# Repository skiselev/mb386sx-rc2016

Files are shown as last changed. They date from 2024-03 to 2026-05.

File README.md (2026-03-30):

# Alsea River 386SX Motherboard
An 386SX/486SLC Motherboard based on SARC RC2016 Chipset

## Introduction

The origin of this project is the [M396F motherboard replica by Marco Both](https://github.com/Marco-Both/M396F-Replika). Marco replicated the PCB layout of a certain revision of M396F motherboard. He didn't provide the schematic.

I reverse engineered the schematic based on his PCB layout and made a PCB layout using that schematic similar to the Marco's replica. This was the initial version of this project - [version 1.0](https://github.com/skiselev/mb386sx-rc2016/tree/v1.0).

The subsequent versions contain the following improvements:

* Use Dallas DS12885 RTC/NVRAM (aka CMOS) with a CR2032 battery instead of Motorola MC146818 with a NiCad battery. This reduces the likliehood of motherboard damage due to a leaking battery. A more modern RTC IC also reduces the number of components
* Use SST39SF010A Flash ROM instead of an EPROM or OTP ROM. The Flash ROM is in-circuit programmable, allowing BIOS and BIOS extension upgrades. It has a bigger 128 KiB capacity, all of which is mapped to the CPU memory. The SST39SF010A is a currently manufactured part
* Use PS/2 compatible keyboard controller, VIA VT82C42N or similar. The motherboard implements a dual PS/2 port with both keyboard and mouse signals. A PS/2 keyboard/mouse splitter cable can be used to connect both a keyboard and a mouse.
* Use ATX case compatible mounting holes placement. Implement ATX power supply power on circuit. This allows using the motherboard with more modern ATX cases and power supplies
* Use DIP-8 / half-can crystal oscillators for the CPU and FPU clocks. This removes the need for a difficult to get clock synthesizer IC used in the original motherboard, while still allowing changing the CPU and the FPU clock by switching the oscillators
* Implement headers for the CPU. The CPU can be either installed on a [386SX Universal Socket Adapter](https://github.com/skiselev/i386sx-socket), or soldered down on the motherboard
* On board disagnostic LEDs, Power, and Reset switches

Alsea River 386SX - Assembled Board

## Status

* Board version 2.3 tested and works properly.
* Board version 2.2 has the fix for the BIOS /OE issue, but it has not been actually built and tested yet.
* Board version 2.1 boots up to BIOS, DOS, and Linux, after performing the fix described in the Known Issues section.
* The following CPUs have been tested with the board version 2.1:
  * Intel 386SX, part name: NG80386SX33. Installed on a 386SX Universal Socket Adapter, configured for 5V. Runs well at 33 MHz.
  * Texas Instruments 486SLCX2-50, part name: TI486SXLC2-G50-WN. Installed on a 386SX Universal Socket Adapter, configured for 3.3V. Runs well at 25 MHz, 33 MHz, and 40 MHz. Unable to enable clock doubling yet.
  * Texas Instruments 486SLCX2-50, part name: TI486SXLC2-G50-PQ. Installed on a 386SX Universal Socket Adapter, configured for 3.3V. Runs well at 25 MHz, 33 MHz, and 40 MHz. Unable to enable clock doubling yet.
  * Texas Instruments 486SLC/E-33. part name: TX486SLC/E-33PAF. Installed on a 386SX Universal Socket Adapter, configured for 5V. Runs well at 33 MHz. Also works at 40 MHz, although gets quite hot. Stability has not been verified yet with 40 MHz.
* PS/2 mouse tested and works properly with both 2 button and 3 button wheeled mouse using [CuteMouse driver](https://cutemouse.sourceforge.net/).
* AMI BIOS 5.10 and [Award BIOS 4.50](https://github.com/skiselev/mb386sx-rc2016/tree/main/BIOS) from other SARC RC2016 based motherboards tested. The latter provides better configurability using MODBIN.

## Hardware Documentation

* [Alsea River 386SX Motherboard - User Guide](User_Guide.md)
* [SARC RC2016 Chipset](SARC_RC2016.md)
* [Cyrix and TI 486SLC/SXLC Processors](Cyrix_and_TI_486.md)

### Schematic and PCB Layout

* [Schematic - Version 2.3](KiCad/AT386SX-Schematic-2.3.pdf)
* [PCB Layout - Version 2.3](KiCad/AT386SX-Board-2.3.pdf)

### Bill of Materials

#### Version 2.3

[Alsea River 386SX Motherboard project on Mouser.com](https://www.mouser.com/Tools/Project/Share?AccessID=6eadf3eb2e) - View and order most components except of the CPU, chipset, keyboard controller, SIMM-30 sockets, and the PCB.

Component type     | Reference | Description                                          | Quantity | Possible sources and notes 
------------------ | --------- | ---------------------------------------------------- | -------- | --------------------------
PCB                |           | Alsea River 386SX PCB - Version 2.1                  | 1        | Order from a PCB manufacturer of your choice using provided Gerber or KiCad files
Integrated Circuit | U1        | 386SX CPU, TI486SXLC, Cx486SLC CPU, 100 pin BQFP     | 1        | eBay
Integrated Circuit | U2        | 387SX FPU or compatible, 68 pin PLCC                 | 1        | eBay. Optional
Integrated Circuit | U3        | SARC RC2016A5, 208 pin PQFP                          | 1        | UTsource
Integrated Circuit | U4        | DS12885 RTC, 24 pin DIP                              | 1        | Mouser [700-DS12885](https://www.mouser.com/ProductDetail/700-DS12885)
Integrated Circuit | U5        | VT82C42N keyboard/mouse controller, 40 pin DIP       | 1        | eBay
Integrated Circuit | U6        | SST39SF010A 128 KiB Flash ROM, 32 pin DIP            | 1        | Mouser [804-39SF010A7CPHE](https://www.mouser.com/ProductDetail/804-39SF010A7CPHE)
Integrated Circuit | U7        | 74HC05 inverters with open drain outputs, 14 pin DIP | 1        | Mouser [595-SN74AHC05N](https://www.mouser.com/ProductDetail/595-SN74AHC05N), [595-SN74HC05N](https://www.mouser.com/ProductDetail/595-SN74HC05N), [595-SN74LS06N](https://www.mouser.com/ProductDetail/595-SN74LS06N)
Integrated Circuit | U8        | 74HCT14 inverters with Schmitt trigger inputs, 14 pin DIP | 1   | Mouser [595-SN74AHCT14N](https://www.mouser.com/ProductDetail/595-SN74AHCT14N), [595-SN74HCT14N](https://www.mouser.com/ProductDetail/595-SN74HCT14N)
Integrated Circuit | U9        | 74HCT74 D-flip flops, 14 pin DIP                     | 1        | Mouser [595-SN74AHCT74N](https://www.mouser.com/ProductDetail/595-SN74AHCT74N), [595-SN74HCT74N](https://www.mouser.com/ProductDetail/595-SN74HCT74N), 
Integrated Circuit | U10       | LM7905 -5V voltage regulator, TO-220-3               | 1        | Mouser [863-MC7905CTG](https://www.mouser.com/ProductDetail/863-MC7905CTG), [926-LM7905CT/NOPB](https://www.mouser.com/ProductDetail/926-LM7905CT-NOPB)
Transistor         | Q1        | 2N3904, NPN transistor, TO-92                        | 1        | Mouser [512-2N3904TA](https://www.mouser.com/ProductDetail/512-2N3904TA)
LED                | D1        | 3 mm LED, blue                                       | 1        | Optional. Mouser [604-WP710A10QBD/D](https://www.mouser.com/ProductDetail/604-WP710A10QBD-D), [696-SSL-LX3054USBD](https://www.mouser.com/ProductDetail/696-SSL-LX3054USBD), [749-3BWD-S](https://www.mouser.com/ProductDetail/749-3BWD-S)
LED                | D2        | 3 mm LED, bi-color red/green                         | 1        | Optional. Mouser [604-WP937EGW](https://www.mouser.com/ProductDetail/604-WP937EGW), [696-SSL-LX3054IGW](https://www.mouser.com/ProductDetail/696-SSL-LX3054IGW), [749-3BC](https://www.mouser.com/ProductDetail/749-3BC)
LED Spacer         | D1, D2    | Spacer for 3 mm LEDs, 3mm height                     | 2        | Optional. Mouser [749-ELM-2-3MM](https://www.mouser.com/ProductDetail/749-ELM-2-3MM)
Crystal Oscillator | X1        | 66 MHz (twice desired CPU frequency), 5V, DIP-8      | 1        | Mouser 50 MHz: [520-TCH5000](https://www.mouser.com/ProductDetail/520-TCH5000), [815-ACH-50-EK](https://www.mouser.com/ProductDetail/815-ACH-50-EK), [774-MXO45HS-3C-50.0](https://www.mouser.com/ProductDetail/774-MXO45HS-3C-50.0); 66.6666MHz: [774-MXO45HS2C66.6666](https://www.mouser.com/ProductDetail/774-MXO45HS2C66.6666), [520-TCH6666-X](https://www.mouser.com/ProductDetail/520-TCH6666-X); 80 MHz: [520-ECS-2200B-800](https://www.mouser.com/ProductDetail/520-ECS-2200B-800), [774-MXO45HS-3C-80.0](https://www.mouser.com/ProductDetail/774-MXO45HS-3C-80.0)
Crystal Oscillator | X2        | 66 MHz (twice desired FPU frequency), 5V, DIP-8      | 1        | Optional. See above.
Crystal Resonator  | Y1        | 14.31818 MHz, parallel, HC-49U                       | 1        | Mouser [815-ABL-14.31818B2](https://www.mouser.com/ProductDetail/815-ABL-14.31818B2), [559-FOXS143-20-LF](https://www.mouser.com/ProductDetail/559-FOXS143-20-LF)
Crystal Resonator Insulator | Y1 | Mylar insulator for HC-49U crystal resonators      | 1        | Optional. Mouser [749-CI-192-028-SR](https://www.mouser.com/ProductDetail/749-CI-192-028-SR)
Crystal Resonator  | Y2        | 32768 Hz, watch crystal, 6 pf, D = 2.1 mm, L = 6.2 mm  | 1      | Mouser [815-AB26T32768KHZ6B](https://www.mouser.com/ProductDetail/815-AB26T32768KHZ6B), [520-ECS327-6-13-X](https://www.mouser.com/ProductDetail/520-ECS327-6-13-X), or [628-VT200F-6PF20PPM](https://www.mouser.com/ProductDetail/628-VT200F-6PF20PPM)
IC Socket          | U2        | 68 pin PLCC, through hole                            | 1        | Mouser [737-PLCC-68-AT](https://www.mouser.com/ProductDetail/737-PLCC-68-AT), [517-8468-11B1-RK-TP](https://www.mouser.com/ProductDetail/517-8468-11B1-RK-TP), [575-682444](https://www.mouser.com/ProductDetail/575-682444)
IC Socket          | U4        | 24 pin DIP                                           | 1        | Mouser [737-ICS-624-T](https://www.mouser.com/ProductDetail/737-ICS-624-T), [517-4824-6000-CP](https://www.mouser.com/ProductDetail/517-4824-6000-CP), [571-1-2199298-8](https://www.mouser.com/ProductDetail/571-1-2199298-8)
IC Socket          | U5        | 40 pin DIP                                           | 1        | Mouser [737-ICS-640-T](https://www.mouser.com/ProductDetail/737-ICS-640-T), [517-4840-6000-CP](https://www.mouser.com/ProductDetail/517-4840-6000-CP), [571-1-2199299-5](https://www.mouser.com/ProductDetail/571-1-2199299-5)
IC Socket          | U6        | 32 pin DIP                                           | 1        | Mouser [737-ICS-632-T](https://www.mouser.com/ProductDetail/737-ICS-632-T), [517-4832-6000-CP](https://www.mouser.com/ProductDetail/517-4832-6000-CP), [571-1-2199300-2](https://www.mouser.com/ProductDetail/571-1-2199300-2)
IC Socket          | U7 - U9   | 14 pin DIP                                           | 3        | Mouser [737-ICS-314-T](https://www.mouser.com/ProductDetail/737-ICS-314-T), [517-4814-3000-CP](https://www.mouser.com/ProductDetail/517-4814-3000-CP), [571-1-2199298-3](https://www.mouser.com/ProductDetail/571-1-2199298-3)
Oscillator Socket  | X1, X2    | 4 pin DIP                                            | 2        | Mouser [535-1108800](https://www.mouser.com/ProductDetail/535-1108800)
Battery            | BT1       | CR2032 battery                                       | 1        | Mouser [81-CR2032](https://www.mouser.com/ProductDetail/81-CR2032), [658-CR2032](https://www.mouser.com/ProductDetail/658-CR2032), [614-CR2032-200](https://www.mouser.com/ProductDetail/614-CR2032-200)
Battery Socket     | BT1       | CR2032 battery socket, through hole                  | 1        | Mouser [122-2420-GR](https://www.mouser.com/ProductDetail/122-2420-GR), [122-2620-GR](https://www.mouser.com/ProductDetail/122-2620-GR)
Connector          | J1 - J4   | SIMM 30 socket, 30 pin                               | 4        | eBay
Connector          | J5 - J10  | ISA card edge connector, 98 pin                      | 6        | Mouser [587-395-098-520-350](https://www.mouser.com/ProductDetail/587-395-098-520-350)
Connector          | J11       | PS/2 Keyboard/Mouse connector, Mini-DIN 6 pin        | 1        | Mouser [806-KMDGX-6S-BS](https://www.mouser.com/ProductDetail/806-KMDGX-6S-BS)
Connector          | J12       | ATX power connector, 20 pin                          | 1        | Mouser [538-46015-2006](https://www.mouser.com/ProductDetail/538-46015-2006)
Connector          | J13       | 2x8 pin header, 2.54 mm (0.1") pitch, through hole   | 1        | Mouser [737-PH2-16-UA](https://www.mouser.com/ProductDetail/737-PH2-16-UA)
Connector          | J14 - J17 | 2x14 pin socket, 2 mm pitch, through hole            | 4        | Optional. Mouser [538-79107-7062](https://www.mouser.com/ProductDetail/538-79107-7062), [200-SQT11301LD](https://www.mouser.com/ProductDetail/200-SQT11301LD), [200-SQT11301FD](https://www.mouser.com/ProductDetail/200-SQT11301FD)
Connector          | JP1 - JP3 | 2 pin header, 2.54 mm (0.1") pitch, through hole     | 3        | Mouser [737-PH1-02-UA](https://www.mouser.com/ProductDetail/737-PH1-02-UA)
Connector          | JP4 - JP6 | 3 pin header, 2.54 mm (0.1") pitch, through hole     | 3        | Mouser [737-PH1-03-UA](https://www.mouser.com/ProductDetail/737-PH1-03-UA). Some headers are optional, and can be hardwired for the soldered CPU.
Connector          | JP1 - JP6 | Shunt, 2 pin, 2.54 mm (0.1") pitch                   | 4        | Mouser [737-MSA-G](https://www.mouser.com/ProductDetail/737-MSA-G), [806-SX1100-B](https://www.mouser.com/ProductDetail/806-SX1100-B)
Switch             | SW1, SW2  | 6 mm tactile switch, vertical, through hole          | 2        | Optional. Mouser [653-B3F-1000](https://www.mouser.com/ProductDetail/653-B3F-1000)
Capacitor          | C1 - C3   | 30 pF, 50V MLCC, 5.08 mm (0.2") pitch                | 3        | Mouser [594-K300J10C0GF5UH5](https://www.mouser.com/ProductDetail/594-K300J10C0GF5UH5)
Capacitor          | C4 - C7   | 47 pF, 50V MLCC, 5.08 mm (0.2") pitch                | 4        | Mouser [810-FG28C0G1H470JNT6](https://www.mouser.com/ProductDetail/810-FG28C0G1H470JNT6)
Capacitor          | C8        | 100 pF, 50V MLCC, 5.08 mm (0.2") pitch               | 1        | Mouser [810-FG28C0G1H101JNT6](https://www.mouser.com/ProductDetail/810-FG28C0G1H101JNT6)
Capacitor          | C9        | 220 pF, 50V MLCC, 5.08 mm (0.2") pitch               | 1        | Mouser [810-FG28C0G1H221JNT6](https://www.mouser.com/ProductDetail/810-FG28C0G1H221JNT6)
Capacitor          | C10 - C21 | 100 nF, 25V MLCC, 5.08 mm (0.2") pitch               | 12       | Mouser [594-K104K15X7RF53H5](https://www.mouser.com/ProductDetail/594-K104K15X7RF53H5), [810-FG28X7R1H104KNT6](https://www.mouser.com/ProductDetail/810-FG28X7R1H104KNT6)
Capacitor          | C22, C23  | 1 uF, 10V MLCC, 5.08 mm (0.2") pitch                 | 2        | Mouser [810-FG28X5R1H105KRT6](https://www.mouser.com/ProductDetail/810-FG28X5R1H105KRT6)
Capacitor          | C24 - C48 | 10 uF, 25V electrolytic, 5 mm diameter, 2.5 mm pitch | 25       | Mouser [667-EEU-FR1H100](https://www.mouser.com/ProductDetail/667-EEU-FR1H100)
Polyfuse           | F1        | 1.1A, 5.08 mm (0.2") pitch                           | 1        | Mouser [650-RUSBF110-2](https://www.mouser.com/ProductDetail/650-RUSBF110-2)
Ferrite Choke      | L1 - L4   | axial                                                | 4        | Mouser [623-2743001112LF](https://www.mouser.com/ProductDetail/623-2743001112LF)
Resistor           | R1 - R12  | 10 ohm, 0.25 W, axial                                | 12       | Mouser [708-CF14JT10R0](https://www.mouser.com/ProductDetail/708-CF14JT10R0), [603-MFR-25FBF52-10R](https://www.mouser.com/ProductDetail/603-MFR-25FBF52-10R)
Resistor           | R13 - R15 | 22 ohm, 0.25 W, axial                                | 3        | Mouser [708-CF14JT22R0](https://www.mouser.com/ProductDetail/708-CF14JT22R0), [603-MFR-25FBF52-22R](https://www.mouser.com/ProductDetail/603-MFR-25FBF52-22R)
Resistor           | R16, R17  | 56 ohm, 0.25 W, axial                                | 2        | Mouser [708-CF14JT56R0](https://www.mouser.com/ProductDetail/708-CF14JT56R0), [603-MFR-25FBF52-56R](https://www.mouser.com/ProductDetail/603-MFR-25FBF52-56R)
Resistor           | R18 - R21 | 100 ohm, 0.25 W, axial                               | 4        | Mouser [708-CF14JT100R](https://www.mouser.com/ProductDetail/708-CF14JT100R), [603-MFR-25FBF52-100R](https://www.mouser.com/ProductDetail/603-MFR-25FBF52-100R)
Resistor           | R22       | 330 ohm, 0.25 W, axial                               | 1        | Mouser [708-CF14JT330R](https://www.mouser.com/ProductDetail/708-CF14JT330R), [603-MFR-25FBF52-330R](https://www.mouser.com/ProductDetail/603-MFR-25FBF52-330R)
Resistor           | R23 - R29 | 470 ohm, 0.25 W, axial                               | 7        | Mouser [708-CF14JT470R](https://www.mouser.com/ProductDetail/708-CF14JT470R), [603-MFR-25FBF52-470R](https://www.mouser.com/ProductDetail/603-MFR-25FBF52-470R)
Resistor           | R30, R31  | 1 kohm, 0.25 W, axial                                | 2        | Mouser [708-CF14JT1K00](https://www.mouser.com/ProductDetail/708-CF14JT1K00), [603-MFR-25FBF52-1K](https://www.mouser.com/ProductDetail/603-MFR-25FBF52-1K)
Resistor           | R32       | 4.7 kohm, 0.25 W, axial                              | 1        | Mouser [708-CF14JT4K70](https://www.mouser.com/ProductDetail/708-CF14JT4K70), [603-MFR-25FBF52-4K7](https://www.mouser.com/ProductDetail/603-MFR-25FBF52-4K7)
Resistor           | R33 - R38 | 10 kohm, 0.25 W, axial                               | 6        | Mouser [708-CF14JT10K0](https://www.mouser.com/ProductDetail/708-CF14JT10K0), [603-MFR-25FBF52-10K](https://www.mouser.com/ProductDetail/603-MFR-25FBF52-10K)
Resistor           | R39       | 22 kohm, 0.25 W, axial                               | 1        | Mouser [708-CF14JT22K0](https://www.mouser.com/ProductDetail/708-CF14JT22K0), [603-MFR-25FBF52-22K](https://www.mouser.com/ProductDetail/603-MFR-25FBF52-22K)
Resistor           | R40       | 1 Mohm, 0.25 W, axial                                | 1        | Mouser [708-CF14JT1M00](https://www.mouser.com/ProductDetail/708-CF14JT1M00), [603-MFR-25FBF52-1M](https://www.mouser.com/ProductDetail/603-MFR-25FBF52-1M)
Resistor Array     | RN1       | 330 ohm, 8 resistors, bussed, 9 pin SIL              | 1        | Mouser [652-4609X-1LF-330](https://www.mouser.com/ProductDetail/652-4609X-1LF-330), [652-4609X-AP1-331LF](https://www.mouser.com/ProductDetail/652-4609X-AP1-331LF)
Resistor Array     | RN2, RN3  | 4.7 kohm, 5 resistors, bussed, 6 pin SIL             | 2        | Mouser [652-4606X-1LF-4.7K](https://www.mouser.com/ProductDetail/652-4606X-1LF-4.7K), [652-4606X-AP1-472LF](https://www.mouser.com/ProductDetail/652-4606X-AP1-472LF)
Resistor Array     | RN4       | 4.7 kohm, 8 resistors, bussed, 9 pin SIL             | 1        | Mouser [652-4609X-1LF-4.7K](https://www.mouser.com/ProductDetail/652-4609X-1LF-4.7K), [652-4609X-AP1-472LF](https://www.mouser.com/ProductDetail/652-4609X-AP1-472LF)
Resistor Array     | RN5       | 10 kohm, 4 resistors, bussed, 5 pin SIL              | 1        | Mouser [652-4605X-1LF-10K](https://www.mouser.com/ProductDetail/652-4605X-1LF-10K), [652-4605X-AP1-103LF](https://www.mouser.com/ProductDetail/652-4605X-AP1-103LF)

## Software

### BIOS

For the testing purposes I am using BIOSes from other commerical motherboards based on the same SARC RC2016 chipset. [The Retro Web](https://theretroweb.com/bios?itemsPerPage=24&chipsetIds[]=648) has a collection of the BIOSes for this chipset.

#### BIOS Progamming and ROM ICs support.

The is designed for the 128 KiB SST SST39SF010A Flash ROM. This ROM is mapped to the 0xE0000-0xFFFFF (or, with 8086 segments, E000:0000 to F000:FFFF). The upper 64 KiB - 0xF0000-0xFFFFF (F000:0000-F000:FFFF) are typically used for the BIOS ROM. The lower 64 KiB - 0xE0000-0xEFFFF can be used for BIOS extensions. Please take that into the consideration when programming the Flash ROM. Make sure to load the BIOS image to the top 64 KiB of the Flash ROM, starting at the address 0x10000. Other pin compatible 128 KiB Flash ROMs, such as AMD AM29F010A, SST SST29EE010, Atmel AT29C010A can be also used without any changes.

It is also possible to use 256 KiB and 512 KiB Flash ROMs, for example SST39SF020 and SST39SF040. Note that the A17 address line is connected to VCC (logic high/"1") and the address line A18 is connected to the ground (logic low/"0"). Therefore when using these flash ROMs, please program the 64 KiB BIOS image starting at the addres 0x30000 of the Flash ROM.

Finally, the board also should work with 64 KiB EPROMs and OTP ROMs, e.g., 27C512. In this case, install the EPROM to the right side of the socket, that is pin 1 of the EPROM should go to the pin 3 of the socket.

## Changes

* Version 2.3
  * Use non-plated through holes for the plastic posts of SIMM30 sockets
  * Ground the shield of the PS/2 connector
  * Update silkscreen: Add acknowledgements, move references and values of DRAM resistors to make them more visible
  * Update schematic: Update a few pins on the RC2016A symbol

* Version 2.2
  * Fix the Flash ROM /OE issue: Connect Flash ROM /OE to ISA /MEMR
  * Renumber DRAM banks - swap Bank 0 and Bank 1. Rename DRAM signals accordingly
  * Add CPU pin 1 marking on the silkscreen
  * Renumber SIMM and ISA slots, so that the reference numbers increase from the top of the PCB to the bottom
  * Renumber electrolytic capacitors, so that the reference numbers increase from the top of the PCB to the bottom
  * Use 22 kohm resistor for R39
  * Remove load capacitors on the ISA bus signals, that are not populated anyway
  * Add a polyfuse for the PS/2 port

* Version 2.1
  * Renumber the component references according to the values and locations on the PCB
  * Update silkscreen
  * Add signal names on the back silkscreen

* Version 2.0
  * Use ATX power supply connector
  * Add ATX power-on circuit

* Version 1.9
  * Add pin headers for the CPU

* Version 1.8
  * Connect /OE and /WE of the BIOS ROM to allow Flash ROM in-system programming
  * Rotate the PCB into portrait orientation

* Version 1.7
  * Use single front panel connector

* Version 1.6
  * Use a low profile 14.31818 MHz crystal (or an SMD part)
  * Add support for the separate FPU clock
  * Use half can oscillators for the CPU and the FPU clocks
  * Use discrete resistors for DRAM interface
  * Use resistors with 300 mil (7.62 mm) lead spacing
  * Move R23 down closer to JP8

* Version 1.5
  * Add more 10 uF filtering capacitors to the power rails
  * Remove extra capacitors for /IOW and RESET signals (use capacitors between two leftmost ISA slots
  * Use resistor arrays for SA17-SA19 pull-ups

* Version 1.4
  * Increase board depth by 0.1". Move mount holes to ATX compatible locations

* Version 1.3
  * Wire keyboard controller in PS/2 mode. Use PS/2 Mini-Din connector in a PS/2 dualport configuration

* Version 1.2
  * Add support for 128 KiB Flash ROM ICs for BIOS. SST39SF010A or similar.
 
* Version 1.1
  * Use DS12885 RTC with CR2032 coin cell battery

* Version 1.0
  * Reverse engineered schematic of M396F motherboard
  * PCB layout closely based on the original M396F layout with a few minor changes

## Known Issues

* Versions 1.8 - 2.1
  * The board will not boot into the BIOS.
    * Workaround: Cut the trace going to the Flash ROM pin 24. Solder a wire to connect the flash ROM /OE signal, pin 24 to the ISA /MEMR signal, ISA bus pin 89.
    * The issue happens because following the reset, 386SX fetches instructions starting from address 0xFFFFF0 - the last 16 bytes of its 16 MiB address space. But the board uses /SMEMR signal for the Flash ROM /OE, and that signal is only generated when reading the first megabyte of memory. So the BIOS ROM does not get the /OE signal.

* Versions 1.0 - 2.1
  * DRAM bank 0 and bank 1 swapped around. Bank 0 is the one closer to the edge of the board.

## Wishlist

* On-board speaker
* Try using more common values for C1 - C2: 27 pF or 33 pF are more commonly available than 30 pF
* 3.3V CPU support
  * The current plan is to test this using the [386SX Universal Socket Adapter](https://github.com/skiselev/i386sx-socket)
  * Separate VCC plane for the CPU
  * Linear voltage regulator
  * Solder jumpers to bypass the voltage regulator and connect the CPU to 5V
* 4 layer PCB
  * VCC and ground planes
* Consider using SMD components

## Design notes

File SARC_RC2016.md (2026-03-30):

# SARC RC2016 Chipset

This documentation is a result of a reverse engineering of an M386F motherboard and observing the chipset configuration registers settings set by AMI and AWARD BIOSes from RC2016-based motherboards.

## Chipset Configuration Registers

The SARC RC2016 configuation registers are accessed by writing the configuration register index to the I/O port 0x22 and then writing or reading the data from the I/O port 0x23

Register Index | Register Bits | Function                                                                   | Default Settings and Notes
---------------|---------------|----------------------------------------------------------------------------|------------------------------------------------------------------------------------------------
0x80           | Bits 7-5      | Unknown                                                                    | Read as 000 on both AMI 5.20 and Award 4.50 BIOSes
0x80           | Bit 4         | Current turbo switch state: 0 = on, 1 = off                                | Appears to be read-only, reflecting the current state of the turbo switch. Also see 0x90, bit 6
0x80           | Bit 3         | FPU status: 0 = no FPU, 1 = FPU installed                                  | Appears to be read-only, set by chipset depending on whether the FPU is installed or not
0x80           | Bits 2-1      | Unknown                                                                    | Read as 000 on both AMI 5.20 and Award 4.50 BIOSes
0x80           | Bit 0         | Unknown                                                                    | Read as 1 on both AMI 5.20 and Award 4.50 BIOSes
0x81           | Bit 7         | Unknown                                                                    | Set to 0 by both AMI 5.20 and Award 4.50 BIOSes
0x81           | Bit 6         | Number of DRAM banks: 0 = 1 bank, 1 = 2 banks                              | Set by the BIOS depending on the number of DRAM banks installed
0x81           | Bits 5-4      | DRAM bank (SIMM) size: 00 = 256 KiB, 10 = 1 MiB, 11 = 4 MiB                | Set by the BIOS depending  on the SIMM size installed
0x81           | Bits 3-1      | Unknown                                                                    | Set to 111 by both AMI 5.20 and Award 4.50 BIOSes
0x81           | Bit 0         | ROM BIOS shadowing control: 0 = disabled, 1 = enabled                      | Set to 1 by BIOS if ROM BIOS shadowing is enabled
0x82           | Bits 7-6      | Unknown                                                                    | Set to 00 by both AMI 5.20 and Award 4.50 BIOSes
0x82           | Bits 5-4      | System BIOS ROM F0000-FFFFF shadowing control: 00 = disabled, 11 = enabled | Set to 11 by both AMI 5.20 and Award 4.50 BIOSes when System BIOS shadowing is enabled
0x82           | Bits 3-0      | Unknown                                                                    | Set to 1111 by both AMI 5.20 and Award 4.50 BIOSes
0x83           | Bits 7,3      | C0000-C3FFF ROM shadowing control: 0xxx0xxx = disabled, 1xxx1xxx = enabled | Set to 1xxx1xxx by both AMI 5.20 and Award 4.50 BIOSes when Video BIOS shadowing is enabled
0x83           | Bits 6,2      | C4000-C7FFF ROM shadowing control: x0xxx0xx = disabled, x1xxx1xx = enabled | Set to x1xxx1xx by both AMI 5.20 and Award 4.50 BIOSes when Video BIOS shadowing is enabled
0x83           | Bits 5,1      | C8000-CBFFF ROM shadowing control: xx0xxx0x = disabled, xx1xxx1x = enabled | Set to xx1xxx1x by both AMI 5.20 and Award 4.50 BIOSes when C8000-CBFFF shadowing is enabled
0x83           | Bits 4,0      | CC000-CFFFF ROM shadowing control: xxx0xxx0 = disabled, xxx1xxx1 = enabled | Set to xxx1xxx1 by both AMI 5.20 and Award 4.50 BIOSes when CC000-CFFFF shadowing is enabled
0x84           | Bits 7,3      | D0000-D3FFF ROM shadowing control: 0xxx0xxx = disabled, 1xxx1xxx = enabled | Set to 1xxx1xxx by both AMI 5.20 and Award 4.50 BIOSes when C0000-C3FFF shadowing is enabled
0x84           | Bits 6,2      | D4000-D7FFF ROM shadowing control: x0xxx0xx = disabled, x1xxx1xx = enabled | Set to x1xxx1xx by both AMI 5.20 and Award 4.50 BIOSes when C4000-C7FFF shadowing is enabled
0x84           | Bits 5,1      | D8000-DBFFF ROM shadowing control: xx0xxx0x = disabled, xx1xxx1x = enabled | Set to xx1xxx1x by both AMI 5.20 and Award 4.50 BIOSes when C8000-CBFFF shadowing is enabled
0x84           | Bits 4,0      | DC000-DFFFF ROM shadowing control: xxx0xxx0 = disabled, xxx1xxx1 = enabled | Set to xxx1xxx1 by both AMI 5.20 and Award 4.50 BIOSes when CC000-CFFFF shadowing is enabled
0x85           | Bits 7,3      | E0000-E3FFF ROM shadowing control: 0xxx0xxx = disabled, 1xxx1xxx = enabled | Set to 1xxx1xxx by both AMI 5.20 and Award 4.50 BIOSes when E0000-E3FFF shadowing is enabled
0x85           | Bits 6,2      | E4000-E7FFF ROM shadowing control: x0xxx0xx = disabled, x1xxx1xx = enabled | Set to x1xxx1xx by both AMI 5.20 and Award 4.50 BIOSes when E4000-E7FFF shadowing is enabled
0x85           | Bits 5,1      | E8000-EBFFF ROM shadowing control: xx0xxx0x = disabled, xx1xxx1x = enabled | Set to xx1xxx1x by both AMI 5.20 and Award 4.50 BIOSes when E8000-EBFFF shadowing is enabled
0x85           | Bits 4,0      | EC000-EFFFF ROM shadowing control: xxx0xxx0 = disabled, xxx1xxx1 = enabled | Set to xxx1xxx1 by both AMI 5.20 and Award 4.50 BIOSes when EC000-EFFFF shadowing is enabled
0x86           | Bits 7,6      | DRAM refresh burst: 00 = 1, 01 = 2, 10 = 3, 11 = 4                         | Set by the BIOS according to the DRAM refresh burst / rate configruation setting
0x86           | Bits 5,4      | DRAM refresh rate: 00 = 1, 01 = 2, 10 = 4, 11 = 8                          | Set by the BIOS according to the DRAM refresh burst / rate configruation setting
0x86           | Bits 3,2      | RAS to CAS width: 01 = CLK2 * 2, 00 = CLK2 * 4                             | Set to 00 by AMI 5.20 BIOS; Set by Award 4.50 BIOS according to "DRAM RAS TO CAS width" setting
0x86           | Bits 1,0      | DRAM RAS precharge: 01 = CLK2 * 6, 10 = CLK2 * 4                           | Set by the BIOS according to the DRAM RAS precharge configuration setting
0x87           | Bit 7         | IO channel refresh: 0 = enabled, 1 = disabled                              | Set by the BIOS according to the IO channel refresh configuration setting
0x87           | Bit 6         | ATBUS stepping: 0 = enabled, 1 = disabled                                  | Set by the BIOS according to the ATBUS stepping configuration setting
0x87           | Bit 5         | Turbo control: 0 = turbo off, 1 = turbo on                                 | Set by AWARD BIOS according to the "Boot Up System Speed" configuration setting. Can be changed using Ctrl-Alt-Plus/Minus. (1)
0x87           | Bit 4         | Turbo LED control: 0 = LED on, 1 = LED off                                 | Set by AWARD BIOS according to the "Boot Up System Speed" configuration setting. Can be changed using Ctrl-Alt-Plus/Minus. (1)
0x87           | Bits 3-2      | Unknown                                                                    | Set to 01 by both AMI 5.20 and Award 4.50 BIOSes
0x87           | Bit 1         | Fast A20 Gate: 0 = enabled, A20 is 0, 1 = disabled, CPU A20 propagated to memory and ISA bus | Controls internal chipset A20 gate circuit. Does not work properly with Cyrix/TI CPUs that require A20M signal. Use the keyboard contoller instead.
0x87           | Bit 0         | Fast CPU Reset: 0 = no reset, 1 = reset CPU                                | Set to 0 after a reset.
0x88           | Bits 3-0      | EMM Page Frame 0 map address (see table below)                             | Set to 0000 by AMI 5.20 BIOS. Award 4.50 BIOS sets to 0100 when 256 KiB SIMMs are installed.
0x88           | Bits 5-4      | EMM Page Frame 0 physical address, bits 15-14                              | Set to 00 by both AMI 5.20 and Award 4.50 BIOSes.
0x88           | Bits 7-6      | EMM Page Frame 0 function: 00 = disabled, 01 = aliased to System BIOS, 10 = mapped to AT bus, 11 = mapped to DRAM | Set to 00 by both AMI 5.20 and Award 4.50 BIOSes.
0x89           | Bits 7-0      | EMM Page Frame 0 physical address, bits 23-16                              | Set to 00000000 by both AMI 5.20 and Award 4.50 BIOSes.
0x8A           | Bits 3-0      | EMM Page Frame 1 map address (see table below)                             | Set to 0000 by both AMI 5.20 and Award 4.50 BIOSes.
0x8A           | Bits 5-4      | EMM Page Frame 1 physical address, bits 15-14                              | Set to 00 by both AMI 5.20 and Award 4.50 BIOSes.
0x8A           | Bits 7-6      | EMM Page Frame 1 function: 00 = disabled, 01 = aliased to System BIOS, 10 = mapped to AT bus, 11 = mapped to DRAM | Set to 00 by both AMI 5.20 and Award 4.50 BIOSes.
0x8B           | Bits 7-0      | EMM Page Frame 1 physical address, bits 23-16                              | Set to 00000000 by both AMI 5.20 and Award 4.50 BIOSes.
0x8C           | Bits 3-0      | EMM Page Frame 2 map address (see table below)                             | Set to 0000 by both AMI 5.20 and Award 4.50 BIOSes.
0x8C           | Bits 5-4      | EMM Page Frame 2 physical address, bits 15-14                              | Set to 00 by both AMI 5.20 and Award 4.50 BIOSes.
0x8C           | Bits 7-6      | EMM Page Frame 2 function: 00 = disabled, 01 = aliased to System BIOS, 10 = mapped to AT bus, 11 = mapped to DRAM | Set to 00 by both AMI 5.20 and Award 4.50 BIOSes.
0x8D           | Bits 7-0      | EMM Page Frame 2 physical address, bits 23-16                              | Set to 00000000 by both AMI 5.20 and Award 4.50 BIOSes.
0x8E           | Bits 3-0      | EMM Page Frame 3 map address (see table below)                             | Set to 0000 by both AMI 5.20 and Award 4.50 BIOSes.
0x8E           | Bits 5-4      | EMM Page Frame 3 physical address, bits 15-14                              | Set to 00 by both AMI 5.20 and Award 4.50 BIOSes.
0x8E           | Bits 7-6      | EMM Page Frame 3 function: 00 = disabled, 01 = aliased to System BIOS, 10 = mapped to AT bus, 11 = mapped to DRAM | Set to 00 by both AMI 5.20 and Award 4.50 BIOSes.
0x8F           | Bits 7-0      | EMM Page Frame 3 physical address, bits 23-16                              | Set to 00000000 by both AMI 5.20 and Award 4.50 BIOSes.
0x90           | Bit 7         | Unknown                                                                    | Set to 0 by AMI 5.20 BIOS; set to 1 by Award 4.50 BIOS.
0x90           | Bit 6         | Current turbo switch state: 0 = off, 1 = on                                | Appears to be read-only, reflecting the current state of the turbo switch. Also see 0x80, bit 4.
0x90           | Bit 5         | Unknown                                                                    | Set 0 to by both AMI 5.20 and Award 4.50 BIOSes.
0x90           | Bit 4         | Number of wait states: 0 = 1 wait state, 1 = 0 wait states                 | Set by the BIOS according to the wait states configuration setting.
0x90           | Bit 3         | RAS to CAS width: 0 = CLK2 * 4, 1 = CLK2 * 6                               | Set by AMI 5.20 BIOS according to the RAS to CAS width setting. Award 5.20 BIOS sets to 0 for 25 and 33 MHz CPUs and to 1 for 40 MHz CPUs.

1. Some Award BIOS calls set these bits to the current BIOS turbo setting regardless of the turbo switch or modifications to the configuration register

### EMM Page Frame Map Address

Register 0x88/0x8A/0x8C/0x8E, Bits 3-0 | Page Frame Map Address
---------------------------------------|-----------------------
0000                                   | 0xC000
0001                                   | 0xC400
0010                                   | 0xC800
0011                                   | 0xCC00
0100                                   | 0xD000
0101                                   | 0xD400
0110                                   | 0xD800
0111                                   | 0xDC00
1000                                   | 0xE000
1001                                   | 0xE400
1010                                   | 0xE800
1011                                   | 0xEC00
1100                                   | Unknown
1101                                   | Unknown
1110                                   | Unknown
1111                                   | Unknown

### Chipset Auto Settings - Award 4.50 BIOS

Setting            | Auto-16MHZ | Auto-20MHZ | Auto-25MHZ | Auto-33MHZ | Auto-40MHZ | Auto-50MHZ | AUTO-50DX2 | AUTO-66DX2
-------------------|------------|------------|------------|------------|------------|------------|------------|-----------
Register 0x86      | 11110110   | 11110110   | 11110110   | 11110010   | 11100010   | N/A        | N/A        | N/A
Register 0x87      | 00XXXXXX   | 00XXXXXX   | 00XXXXXX   | 00XXXXXX   | 00XXXXXX   | N/A        | N/A        | N/A
DRAM refresh burst | 4          | 4          | 4          | 4          | 4          | N/A        | N/A        | N/A
DRAM refresh rate  | 8          | 8          | 8          | 8          | 4          | N/A        | N/A        | N/A
RAS to CAS width   | CLK2 * 2   | CLK2 * 2   | CLK2 * 2   | CLK2 * 4   | CLK2 * 4   | N/A        | N/A        | N/A
DRAM RAS precharge | CLK2 * 4   | CLK2 * 4   | CLK2 * 4   | CLK2 * 4   | CLK2 * 4   | N/A        | N/A        | N/A

### DRAM Refresh Timing

SARC RC2016 uses 14.31818 MHz / 12 / 18 = 66.2878704 kHz as the DRAM refresh frequency.

(To check: Is the divider of 18 configurable using the PIT channel 1?)

* The DRAM refresh rate setting - chipset configuration register 0x86, bits 5,4 set the divider for this refresh frequency.
  * Refresh rate of 1 (register 0x86, bits 5,4 = '00') setting results in 66.2878704 kHz refresh frequency or approximately 15 us refresh period.
  * Refresh rate of 8 (register 0x86, bits 5,4 = '11') setting results in 66.2878704 / 8 = 8.2859838 kHz refresh frequency or approximately 120 us refresh period.
  * The slower refresh rate slighly improves system performance. Ideally, the DRAM/SIMM datasheet should be consulted to determine the correct refresh rates/periods.
* The DRAM refresh burst setting: chipset configuration register 0x86, bits 7,6 set the number of refresh cycles (burst) for each refresh period. 

### ISA Bus Timing

The SARC RC2016 uses 14.31818 MHz / 2 = 7.15909 MHz as ISA clock. That is the frequency BCLK signal is running at.

* 8-bit I/O: /IOR and /IOW timing: 4.5 clock cycles. Signals activated on the falling clock BCLK edge. Singals deactivated on the rising BCLK clock egde.
* 16-bit I/O: /IOR and /IOW timing: 1.5 clock cycles. Signals activated on the falling clock BCLK edge. Singals deactivated on the rising BCLK clock egde.
* Memory: /MEMR, /MEMW, /SMEMR, and /SMEMW timing: 2 clock cycles. Signals activated on the falling? clock BCLK edge. Singals deactivated on the falling? BCLK clock egde.

IO channel refresh setting - chipset configuration register 0x87, bit 7: when set to 1, enables generating refresh cycles on ISA bus by activating /REFRESH signal and suspending other transactions. When set 0 disables ISA refresh cycles, improving system performance.

## Chipset Pinout

### Pins by Function - Chipset, RTC, Keyboard Controller, and BIOS

Pin                                       | Signal Name | Description
------------------------------------------|-------------|------------
13,26,41,65,78,93,117,130,145,169,182,197 | GND         | Ground
12,40,64,92,116,144,168,196               | VCC         | VCC / 5 V Power
1,104,105                                 | NC          | Not connected (1)
7                                         | SPEAKER     | PC speaker, output
8                                         | RESET_SW    | Reset switch, input
9                                         | TURBO_LED   | Turbo LED, output
10                                        | PULLUP      | 4.7k pull-up, input (2)
11                                        | TURBO_SW    | Turbo switch, input
14                                        | X1          | 14.31818 MHz oscillator, input
15                                        | X2          | 14.31818 MHz oscillator, output
141                                       | KBC_IRQ1    | IRQ1 from keyboard controller, input
142                                       | BIOS_CS     | Active high CS for BIOS?, output (3)
143                                       | POWER_GOOD  | Power good from power supply, input
149                                       | RTC_DS      | DS signal to RTC, output
150                                       | RTC_AS      | AS signal to RTC, output
151                                       | RTC_RW      | RW signal to RTC, output
152                                       | /KBC_CS     | /CS to keyboard controller, output
153                                       | /GATE_A20   | /GATE_A20 from keyboard, input
154                                       | KBC_CLK     | Clock to keyboard controller, output
155                                       | /KBC_RC     | Reset from keyboard controller, input
156                                       | /BIOS_CS    | /CS to BIOS ROM (E0000-FFFFF), output
159                                       | /RTC_IRQ8   | /IRQ8 from RTC, input

1. Pins 1, 104, and 105 are not connected. They seem to be pulled high by the chipset during normal operation.
2. Needs to be pulled up with 4.7k - 10k. System will not POST without it. System hangs if this pin is grounded.
3. Pin 142 appears to be active when /BIOS_CS, pin 156 is also active, but it gets active a bit (one ISA clock cycle?!) earlier than /BIOS_CS.

### Pins by Function - CPU and FPU Interface

Pin             | Signal Name | Description
----------------|-------------|------------
42-63,74        | A32-A1      | CPU address bus, input
37              | FPU_PEREQ   | FPU PEREQ, output
38              | FPU_BUSY    | FPU BUSY, output
39              | FPU_ERROR   | FPU ERROR, input
66              | INTR        | CPU INTR, output
67              | NMI         | CPU NMI, output
68              | CPU_PEREQ   | CPU PEREQ, output
69              | CPU_BUSY    | CPU BUSY, output
70              | CPU_RESET   | CPU RESET, output
71              | W/R         | CPU and FPU W/R, input
72              | D/C         | CPU D/C, input
73              | M/IO        | CPU and FPU M/IO, input
75              | /BHE        | CPU /BHE, input
76              | /BLE        | CPU /BLE, input
77              | /ADS        | CPU and FPU /ADS, input
79              | CLK2        | CPU and FPU CLK2, input
80              | /READY      | CPU and FPU /READY, output
81              | HOLD        | CPU HOLD, output
82              | HLDA        | CPU HLDA, input
83-90,94-101    | D0-D15      | CPU data bus, bi-dir
91              | FPU_RESET   | FPU RESET, output

### Pins by Function - DRAM Interface

Pin             | Signal Name | Description
----------------|-------------|------------
102             | /RAS01      | DRAM /RAS, banks 0,1, output
103             | /RAS23      | DRAM /RAS, banks 2,3, output
106-109         | /CAS0-/CAS3 | DRAM /CAS0-/CAS3, output
110             | /MWE        | DRAM write enable, output
111-115,118-123 | MA0-MA10    | DRAM address bus, output
160             | DP_LO       | DRAM parity, low byte, bi-dir
161             | DP_HI       | DRAM parity, high byte, bi-dir

### Pins by Function - ISA Bus

Pin                  | Signal Name                      | Description
---------------------|----------------------------------|------------
2                    | AEN                              | ISA AEN, output
3                    | TC                               | ISA TC, output
4                    | OSC                              | ISA OSC clock 14.31818 MHz, output
5                    | BCLK                             | ISA bus clock, output
6                    | /REFRESH                         | ISA bus refresh, output
16,18,20,22,24,27,39 | /DACK7-/DACK5,/DACK3-/DACK0      | ISA DMA acknowledge, output
17,19,21,23,25,28,30 | DRQ7-DRQ5,DRQ3-DRQ0              | ISA DMA request, input
31                   | /0WS                             | ISA /0WS, input
32                   | MASTER                           | ISA MASTER, input
33                   | IO_CH_RDY                        | ISA IO_CH_RDY, input
34                   | IOCS16                           | ISA IOCS16, input
35                   | IO_CH_CHK                        | ISA IO_CH_CHK, input
36                   | MEMCS16                          | ISA MEMCS16, input
124-129,131-140      | SD0-SD16                         | ISA SD0-SD0 data bus, bi-dir
157                  | /RESET                           | Reset to ISA and peripherals, output
158                  | ALE                              | ISA ALE, output
162-167,170          | LA23-LA17                        | ISA LA23-LA17 unlatched address, output or bi-dir? 
171-181,183-188      | SA16-SA0                         | ISA SA16-SA0 latched address, output or bi-dir?
189                  | /SBHE                            | ISA /SBHE, output
190                  | /IOR                             | ISA I/O read, output
191                  | /IOW                             | ISA I/O write, output
192                  | /MEMR                            | ISA memory read, output
193                  | /MEMW                            | ISA memory write, output
194                  | /SMEMR                           | ISA memory read, low 1 MiB, output
195                  | /SMEMW                           | ISA memory write, low 1 MiB, output
198-208              | IRQ15,IRQ14,IRQ12-IRQ9,IRQ7-IRQ3 | ISA interrupt request, input

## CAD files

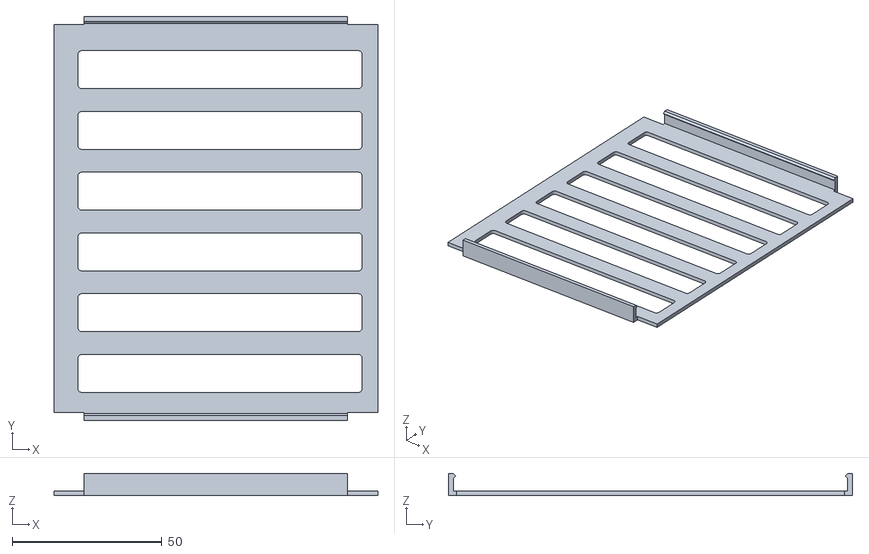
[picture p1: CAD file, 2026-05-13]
printed/Slots_Cover.stl
108.2 x 135.1 x 7.40

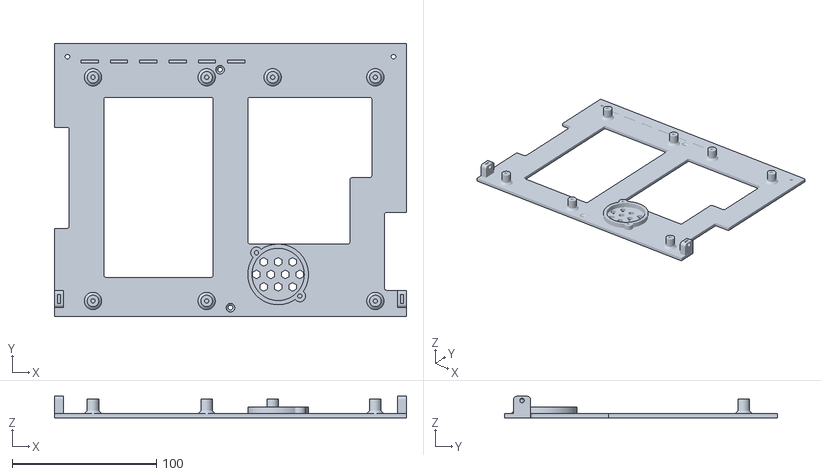
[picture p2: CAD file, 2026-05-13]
printed/Motherboard_Tray.stl
243.8 x 188.8 x 15.0

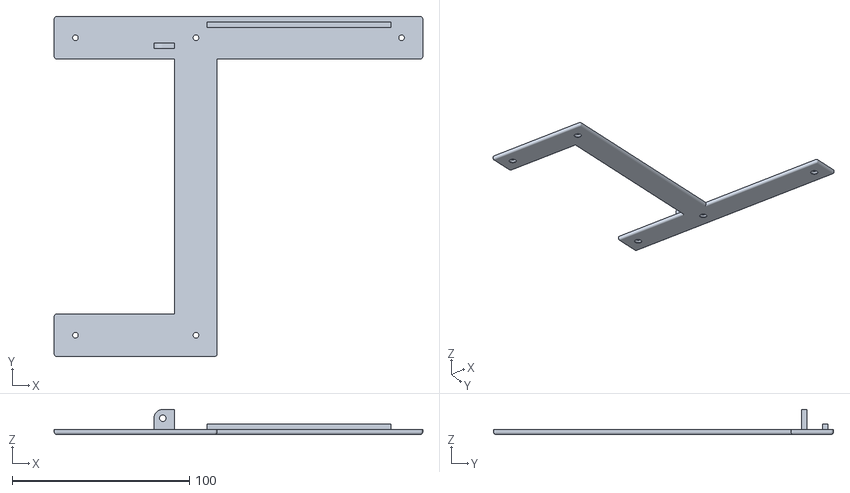
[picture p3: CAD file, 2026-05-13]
printed/Right.stl
208.0 x 191.8 x 14.2

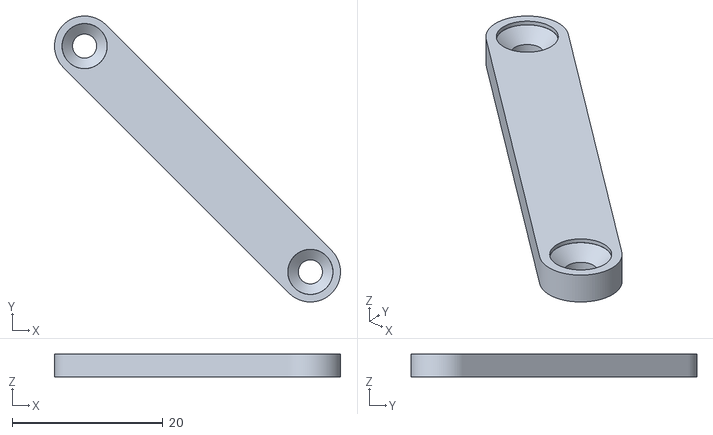
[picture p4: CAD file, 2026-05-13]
printed/Speaker_Bracket.stl
38.0 x 38.0 x 3.00

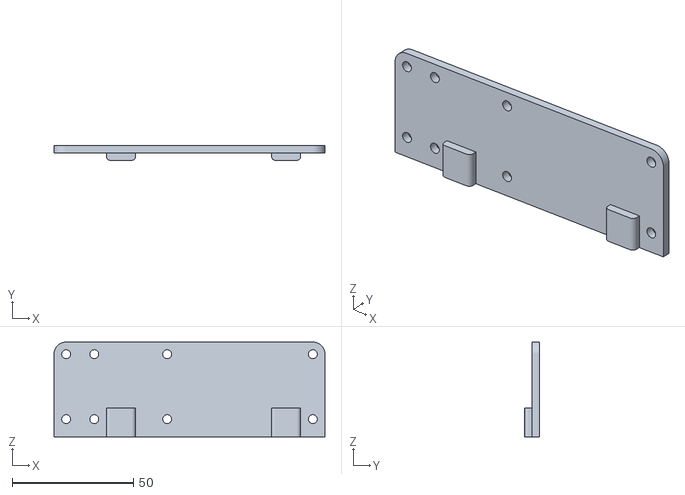
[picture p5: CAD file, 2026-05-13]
printed/Left_Drives_Bracket.stl
111.6 x 6.00 x 39.1

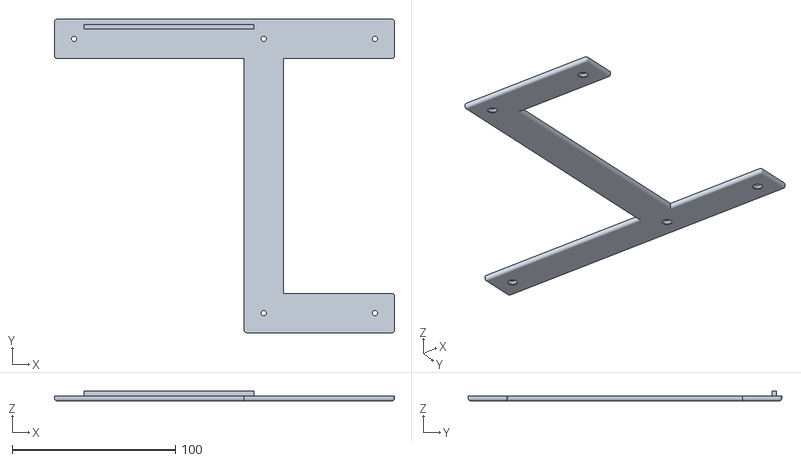
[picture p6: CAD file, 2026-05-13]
printed/Left.stl
208.0 x 191.8 x 6.00

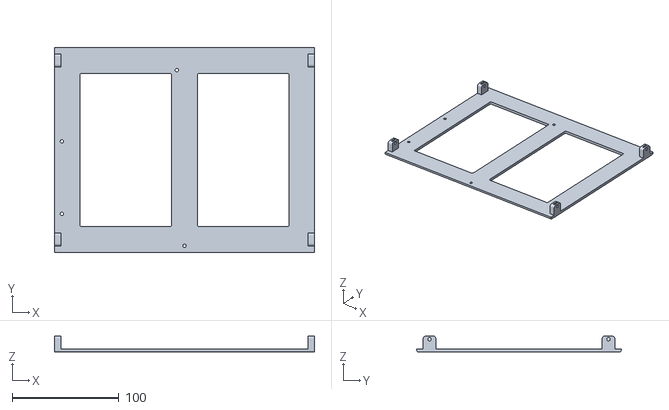
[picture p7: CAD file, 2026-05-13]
printed/Bottom.stl
243.8 x 191.8 x 15.0

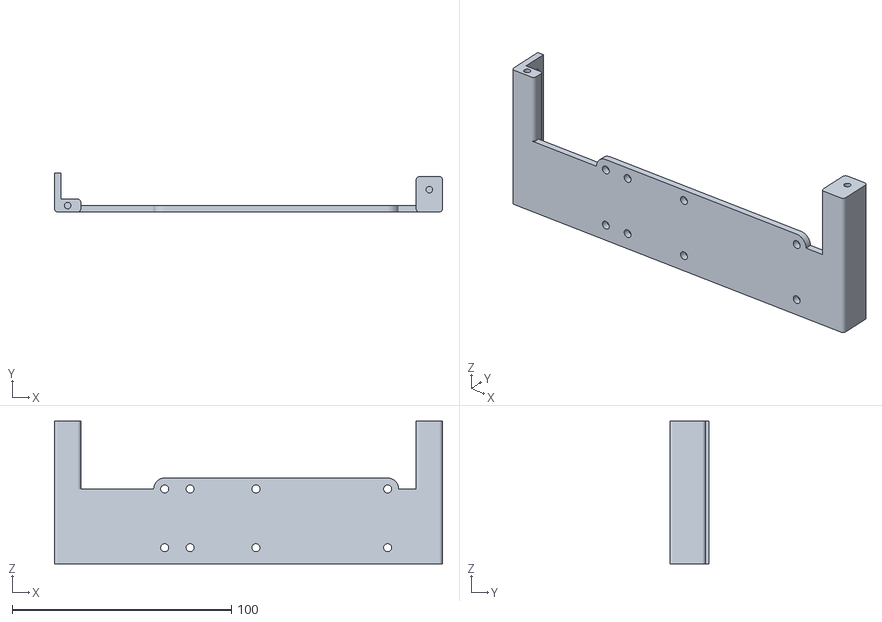
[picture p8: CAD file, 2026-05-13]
printed/Right_Drives_Bracket.stl
176.8 x 17.9 x 65.0

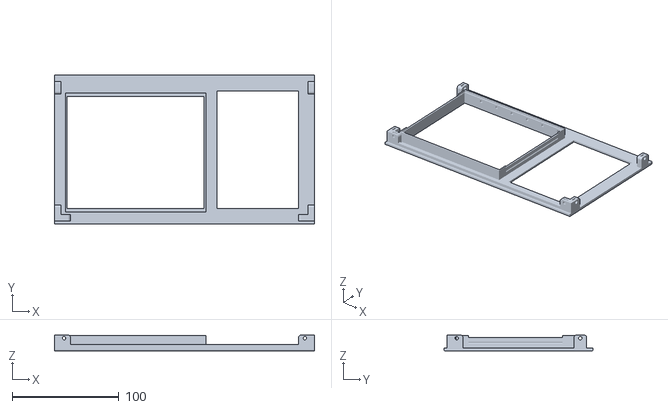
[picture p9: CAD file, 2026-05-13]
printed/Back.stl
243.8 x 140.0 x 15.0

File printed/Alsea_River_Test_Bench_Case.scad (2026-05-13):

// 3D Printed Test Bench Case for the Alsea River 386SX system
//
// Copyright (C) 2026 Sergey Kiselev.
//
// This program is free software: you can redistribute it and/or modify
// it under the terms of the GNU General Public License as published by
// the Free Software Foundation, either version 3 of the License, or
// (at your option) any later version.
//
// This program is distributed in the hope that it will be useful,
// but WITHOUT ANY WARRANTY; without even the implied warranty of
// MERCHANTABILITY or FITNESS FOR A PARTICULAR PURPOSE.  See the
// GNU General Public License for more details.
//
// You should have received a copy of the GNU General Public License
// along with this program.  If not, see <http://www.gnu.org/licenses/>.

// set only one of the variables below to true to draw the respective part
generate_preview = false;
render_back = false;
render_mb_tray = false;
render_bottom = false;
render_right_drives_bracket = false;
render_left_drives_bracket = false;
render_left = false;
render_right = false;
render_slots_cover = false;
render_speaker_bracket = true;

// All dimensions are in mm
in2mm=25.4;                 // mm per inch
mb_depth=6.8*in2mm;         // motherboard X dimension
mb_width=8.6*in2mm;         // motherboard Y dimension

// openings for cable routing on the sides of the motherboard
cable_routing_width_left=0.4*in2mm; // opening for cable routing on the left of the motherboard (floppy and IDE ribbon cables)
cable_routing_depth_left=70; // 2.68" for 50 pin SCSI connector
cable_routing_width_right=0.6*in2mm; // openning for cable routing on the right of the motherboard (ATX power cable)
cable_routing_depth_right=54; // 51.60 mm for 24 pin ATX power connector


bracket_depth=0.45*in2mm;    // depth of an ISA bracket (top part inside)
mb_to_case_back=0.065*in2mm;// motherboard to the inside of the back of the case
bottom_to_mb_height=65; // SFX power supply height is 2.5"

// case inside dimensions
inside_depth=mb_depth+bracket_depth+mb_to_case_back;
inside_width=mb_width+cable_routing_width_left+cable_routing_width_right;
inside_height=134;
case_thickness=3.0;
// case outside dimensions
case_depth=inside_depth+case_thickness*2;
case_width=inside_width+case_thickness*2;
case_height=inside_height+case_thickness*2;


corner_radius=case_thickness/2;
nut_inserts_radius = 2.6;       // corner radius for nut inserts
bracket_thickness=1.6;       // thickness of the material around ISA brackets
pcb_thickness=1.6;

mb_to_case_left=cable_routing_width_left;  // keep space for the cables on the sides of the motherboard
mb_to_left_slot=0.558*in2mm; // distance between the left edge of motherboard to the center of the leftmost slot cut-out
slot_height=0.61*in2mm;
slot_spacing=0.8*in2mm;  // distance between ISA slots
card_height=3.9*in2mm;   // height of an ISA card, not including edge connector
card_to_bracket_top=3.65*in2mm; // ISA card bottom to the top of the bracket

bracket_height=card_to_bracket_top+slot_height;             // height of an ISA bracket (motherboard to top part inside)
bracket_width=0.72*in2mm; // width of an ISA bracket
tongue_cutout_width=12; // width of a cutout for the tongue of an ISA bracket

bracket_tab_offset = (0.740+0.110)*in2mm-bracket_width; // offset of the bracket tab relative to the bracket's left side
slots=6;                // number of slots
slots_area_width=slots*slot_spacing+bracket_tab_offset*2; // width of slots plus a bit more
slots_area_left=mb_to_case_left+mb_to_left_slot-bracket_width/2-bracket_tab_offset; // distance from the inside left wall to slots area
echo("bracket_tab_offset", bracket_tab_offset);
echo("slots_area_width", slots_area_width);

standoff_height=10;
standoff_radius=4;
m3_hole_radius=3.2/2;
unc3_32_hole_radius=0.144*in2mm/2;
m3_tap_hole_radius=3.0/2;
m3_head_radius=3;

floppy_width=101.6;
floppy_height=25.4;
floppy_depth=145;
floppy_mount_height=5;
floppy_mount_depth_1=21;
floppy_mount_depth_2=floppy_mount_depth_1+60;
floppy_mount_depth_3=floppy_mount_depth_1+90;
floppy_bezel_depth=4;
floppy_x_offset=inside_depth+case_thickness-floppy_bezel_depth;

hdd_width=101.6;
hdd_height=26.1;
hdd_depth=147;
hdd_mount_height=6.35;
hdd_mount_depth_1=16.9;
hdd_mount_depth_2=hdd_mount_depth_1+60;
hdd_mount_depth_3=hdd_mount_depth_1+101.6;
hdd_x_offset=inside_depth+case_thickness-floppy_bezel_depth-floppy_mount_depth_1+hdd_mount_depth_1;

drive_spacing=hdd_mount_height+floppy_height-floppy_mount_height; // 26.75 mm - this allows reusing the same holes for HDD and floppy
drive_y_offset=10; // distance from left edge of bottom plate to the left side of drives
drive_z_offset=1; // distance from bottom plate to the bottom of an HDD

screw_to_edge=5; // width of the material around the screws in the drives mounting bracket and PSU mounts
bar_width=24; // width of bars in left, right, and motherboard tray panels

psu_depth=100;
psu_height=2.5*in2mm; // 63.5 mm
psu_width=125;
psu_mount_height1=psu_height/2-25.8;
psu_mount_height2=psu_height/2;
psu_mount_height3=psu_height/2+25.8;
psu_mount_width1=6;
psu_mount_width2=119;
psu_fan_diameter=80;
psu_x_offset=15;
psu_y_offset=inside_width-psu_width-0.25; // 0.25 mm tolerance for PSU size

tolerance=0.1;

// middle front support
support_width=12;
support_screw_length=10;

// speaker
speaker_radius=36/2;
speaker_height=4.5;
speaker_x_offset=inside_depth-speaker_radius-case_thickness-5;
speaker_y_offset=(inside_width+speaker_radius)/2+bar_width;

// distance between ventilation holes
vent_hole_radius=3;
vent_holes_horiz_step=10;
vent_holes_vert_step=sin(60)*vent_holes_horiz_step;

// number of faces in circular objects
$fn=90;

echo("Case width", case_width);
echo("Case depth", case_depth);
echo("Case height", case_height+bottom_to_mb_height+case_thickness);
echo("Space above ISA cards", inside_height-standoff_height-pcb_thickness-slot_height-card_height);
echo("Maximal ISA card length", inside_depth-bracket_depth-mb_to_case_back);
echo("Space between drive bracket and power supply", psu_y_offset-(drive_y_offset+hdd_width+tolerance+case_thickness));

include <ISA_Brackets.scad>


if (render_back) {
    rotate([0,0,-90]) {
        case_back();
    }
}

if (render_bottom) {
    rotate([0,0,-90]) {
        case_bottom();
    }
}
if (render_right_drives_bracket) {
    right_drives_bracket();
}
if (render_left_drives_bracket) {
    left_drives_bracket();
}
if (render_mb_tray) {
    rotate([0,0,-90]) {
        case_mb_tray();
    }
}
if (render_left) {
    rotate([0,0,-90]) {
        case_left();
    }
}
if (render_right) {
    rotate([180,0,-90]) {
        case_right();
    }
}
if (render_slots_cover) {
    slots_cover();
}
if (render_speaker_bracket) {
    rotate([180,0,0]) {
        speaker_bracket();
    }
}

if (generate_preview) {
    // back panel
    translate([0,0,case_height]) {
        rotate([0,90,0]) {
            color("cyan") case_back();
        }
    }
    // slots cover
    translate([case_thickness+bracket_depth,case_thickness+slots_area_left,case_thickness+standoff_height+pcb_thickness]) {
        rotate([0,-90,0]) {
            color("blue") slots_cover();
        }
    }
    // case motherboard tray
    translate([case_thickness,case_thickness,0]) {
        color("orange") case_mb_tray();
    }
    // case bottom
    translate([0,case_thickness,-bottom_to_mb_height-case_thickness]) {
        color("magenta") case_bottom();
        // drives mount brackets
        color("pink") right_drives_bracket();
        color("pink") left_drives_bracket();
    }

    // left panel
    translate([0,0,-bottom_to_mb_height]) {
        rotate([-90,0,0]) {
            color("green") case_left();
        }
    }
    // right panel
    translate([0,case_width,-bottom_to_mb_height]) {
        rotate([-90,0,0]) {
            color("red") case_right();
        }
    }

    // power supply
    translate([psu_x_offset+case_thickness, psu_y_offset+case_thickness,(psu_height-bottom_to_mb_height)/2]) {
        sfx_power_supply(); 
    }

    // motherboard and ISA brackets
    translate([case_thickness,case_thickness,case_thickness]) {
        // motherboard translate
        translate([mb_to_case_back+bracket_depth,mb_to_case_left,standoff_height]) {
            mb();
        }
        // ISA bracket
        translate([bracket_depth+br_thick,mb_to_case_left+mb_to_left_slot-br_width/2,standoff_height+pcb_thickness+bracket_height]) {
            rotate([90,90,180]) {
                eth_bracket();
            }
        }
    }
    // hard drive
    translate([hdd_x_offset-hdd_depth+case_thickness,hdd_width+case_thickness+drive_y_offset,-bottom_to_mb_height+drive_z_offset]){
        rotate([90,0,0]) {
            hard_drive();
        }
    }
    // floppy drive
    translate([floppy_x_offset-floppy_depth+case_thickness,floppy_width+case_thickness+drive_y_offset,-bottom_to_mb_height+drive_z_offset+drive_spacing+hdd_mount_height-floppy_mount_height]){
        rotate([90,0,0]) {
            floppy_drive();
        }
    }
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

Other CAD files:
printed/ISA_Brackets.scad

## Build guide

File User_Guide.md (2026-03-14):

# Alsea River 386SX Motherboard - User Guide

## Specifications

* Processor support: Intel 80386SX, AMD Am386SX/SXL, Cyrix Cx486SLC, TI Tx486SLC, TI TI486SXLC, and other processors pin compatible with Intel 80386SX.
* Math coprocessor support: Intel 80387SX or compatibles.
* Memory: From 512 KiB to 16 MiB of RAM, using 2 or 4 30 pin SIMM modules, from 256 KiB to 4 MiB each.
* System BIOS: 128 KiB flash ROM, that can be programmed in-system.
* 6 ISA slots.
* PS/2 keyboard and PS/2 mouse support.
* Real Time Clock (RTC) and battery backed non-volatile RAM (NVRAM), using replaceable CR2032 battery for backup.
* 20-pin ATX power connector.
* On-board diagnostic LEDs, and power and reset switches.

## Jumpers and Headers

### JP1 - Clear CMOS/NVRAM

Position | Description
---------|------------
Open     | Normal operation
Closed   | Clear CMOS/NVRAM

### JP2 - Select Display Type

Position | Description
---------|------------
Open     | Monochrome
Closed   | Color

Note: This jumper is applicable to the CGA and MDA display controllers.
VGA display controllers typically can detect the display type automatically, and the setting of this jumper has no effect on the VGA display type selection.

### JP3 - Keyboard Lock

Position | Description
---------|------------
Open     | Normal operation, keyboard unlocked
Closed   | Keyboard locked

### JP4 - CPU Clock Select

Position | Description
---------|------------
1-2      | 40 MHz
2-3      | 33 MHz or below

Note: Setting to 1-2 (40 MHz), effectively disables address pipelining, leading to a slightly slower performance. All 40 MHz CPUs tested so far work well with the 2-3 setting.

### JP5 - FPU Clock Select

Position | Description
---------|------------
1-2      | Synchronous operation. The FPU uses the same clock as the CPU, generated by the oscillator X1
2-3      | Asynchronous operation. The FPU uses the clock generated by the oscillator X2

### JP6 - IRQ12 Source Select

Position | Description
---------|------------
1-2      | IRQ12 is connected to the keyboard/mouse controller and used for PS/2 mouse
2-3      | IRQ12 is connected to the ISA bus

Note: Set the JP6 to the position 1-2 when using a PS/2 mouse

### J13 - Front Panel Header

Pin | Description                 | Pin | Description
----|-----------------------------|-----|------------
1   | Speaker (-) terminal        | 2   | Turbo switch input
3   | Not connected               | 4   | GND, Turbo switch
5   | GND                         | 6   | Not connected
7   | 5V, Speaker (+) terminal    | 8   | Power LED (+) terminal
9   | Turbo LED (+) terminal      | 10  | Power LED (+) terminal
11  | GND, Turbo LED (-) terminal | 12  | GND, Power LED (-) terminal
13  | Reset switch input          | 14  | Power switch input
15  | GND, Reset switch           | 16  | GND, Power switch

## On-board LEDs and Switches

The motherboard has two switches and two LEDs to simplify debug and use without an enclosure:
* SW1 - Power switch. Turns on the ATX power supply connected to the board and powers on the board.
* SW2 - Reset switch. Resets the CPU (cold reboot).
* D1 - Power LED (Blue). Lights up when the board is powered on.
* D2 - Activity LED (Red/Green):
  * When the motherboard is powered on, this LED changes color between red and green every time A7 address line changes from 0 to 1. Typically, if this LED changes colors or appears to be yellow, indicates that the CPU is executing the code. If it remains solid red or green, it is likely that the system is stuck or the CPU is halted.
  * When the motherboard is powered off, this LED lights up red, indicating that 5V standby voltage is applied to the motherboard.

## Memory Configuration

The motherboard has two memory banks:
* Bank 0 are the two SIMMs closer to the edge of the board.
* Bank 1 are the two SIMMs closer to the chipset.

A memory bank, if used, must be fully populated. That is, both SIMMs should be installed.
Bank 0 must be populated first, before populating Bank 1.
All SIMMs must be the same size.
The motherboard supports fast page mode (FPM) DRAM memory. Recommended memory latency 60-70ns.

### Supported Memory Configurations

Bank 0 (J1, J2) | Bank 1 (J3, J3) | Memory Size
----------------|-----------------|------------
256 KiB x 2     | None            | 512 KiB
256 KiB x 2     | 256 KiB x 2     | 1 MiB
512 KiB x 2     | None            | 1 KiB
512 KiB x 2     | 512 KiB x 2     | 2 MiB
1 MiB x 2       | None            | 2 MiB
1 MiB x 2       | 1 MiB x 2       | 4 MiB
4 MiB x 2       | None            | 8 MiB
4 MiB x 2       | 4 MiB x 2       | 16 MiB

## PS/2 Mouse Support

The PS/2 connector on Alsea River 386SX Motherboard contains PS/2 keyboard and PS/2 mouse signals. A PS/2 Y splitter cable should be used to connect both a keyboard and a mouse.
Note that with most Y splitter cables, the keyboard should be connected to the mouse connector, and the mouse should be connected to the keyboard connector. Refer to the table below for the splitter cable pinout.
Make sure to set jumper JP6 to 1-2 position for the PS/2 mouse operation.

### PS/2 Combo Port Pinout

Pin - Motherboard | Pin - Keyboard | Pin Mouse | Signal Description
------------------|----------------|-----------|-------------------
1                 | 1              | -         | Keyboard data
2                 | -              | 1         | Mouse data
3                 | 3              | 3         | GND, Ground
4                 | 4              | 4         | VCC, 5V
5                 | 5              | -         | Keyboard clock
6                 | -              | 5         | Mouse clock

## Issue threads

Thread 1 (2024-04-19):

-5V ?

andreacampanella, 2024-04-19:
I really like this project,  I noticed you are planning to use a ATX power supply, would be nice to have a -5v regulator on the board, maybe as an option, new PSUs that doesn't support -5v and many souncards needs that voltage to generate amplied sound.

skiselev, 2024-04-19:
Yes, that's the plan

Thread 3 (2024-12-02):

Are there fabrication ready files?

Nurmukhamed, 2024-12-02:
Hello Sergey.
Thank you for great work for adaptation motherboard.

I want to order 1-2 pcbs at jcbpcb (or other similar services), so i need gerber files and bom file.

Where i can get them? I have no expirience at kicad and dont know how to convert to gerber.

May you help me?

skiselev, 2024-12-02:
The project is not complete yet, not tested, not by me at least, therefore I don't feel comfortable releasing Gerber files.
With that being said, it should be pretty straight forward to load KiCad files in the KiCad software and generate Gerber files and BOM list...

Nurmukhamed, 2024-12-03:
OK. Lets try luck with KiCad.

I guess after fabrication i will found no errors, but if they appears i will notify you. It can help you to fix errors in schemes or pcb.

Marco-Both, 2024-12-09:
What is missing? Just the final test?

Bdw i made something new on the side. https://github.com/Marco-Both/A-one-286 And this time completely in Kicad. :-)

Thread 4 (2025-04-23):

Flash Bios

4bitFanatics, 2025-04-23:
Hello Sergey K, how are you? This project is incredible and very well designed, and I was very excited, I generated the Gerber and ordered 5 boards, I didn't pay attention to the BIOS, will a new BIOS version be written for this PCB? Thank you!

skiselev, 2025-04-23:
I haven't built and tested the project myself, so I'd be curious to know how it works for you.

Please use BIOS dumped from another motherboard with the RC2016 chipset.

Here are a couple of links:
https://minuszerodegrees.net/at_clone_bios/at_clone_bios.htm
https://github.com/dekuNukem/Vintage_Computer_ROM_Dumps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

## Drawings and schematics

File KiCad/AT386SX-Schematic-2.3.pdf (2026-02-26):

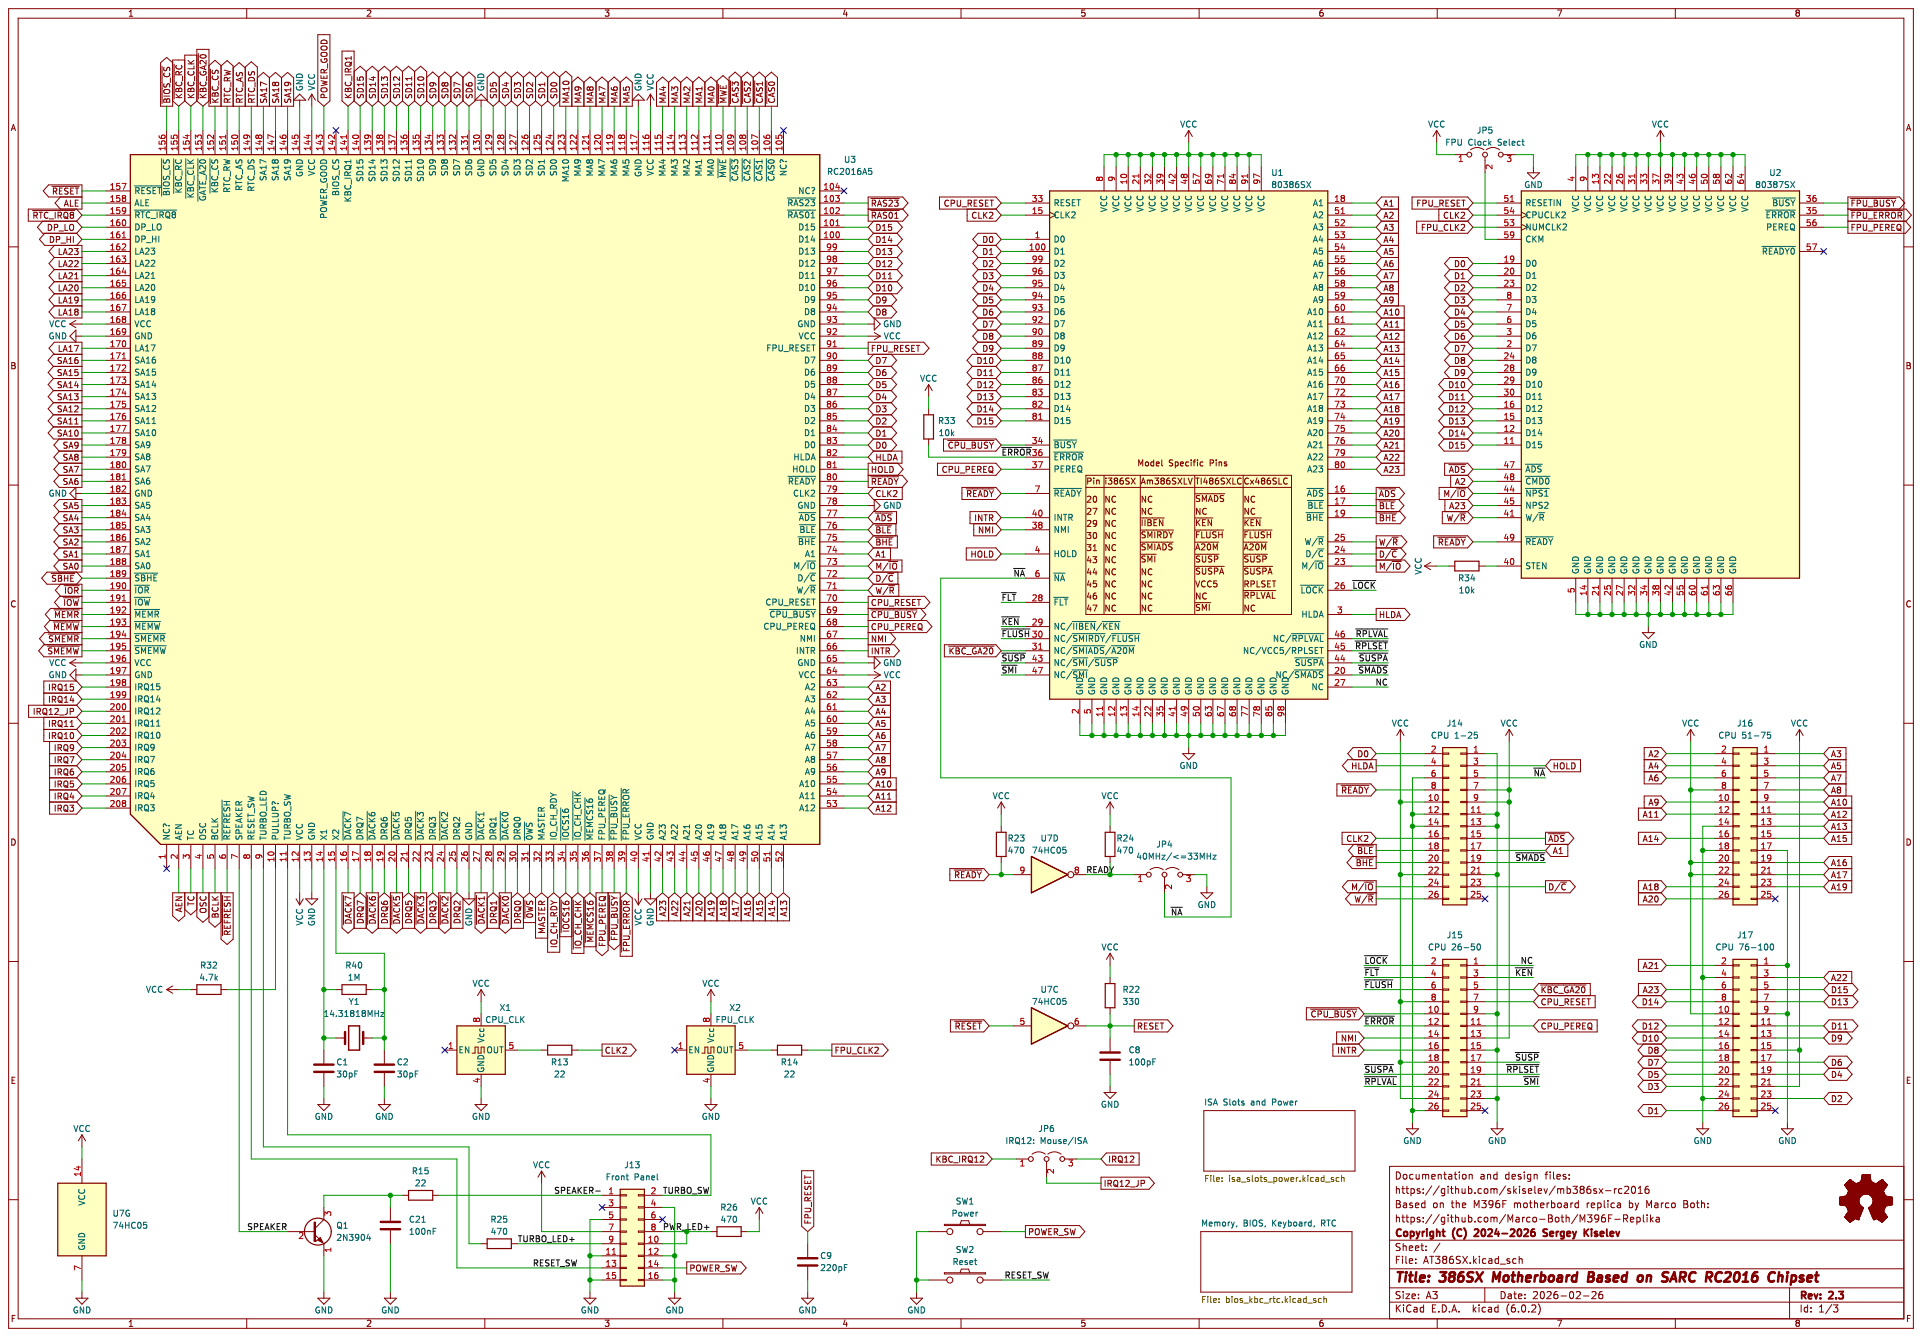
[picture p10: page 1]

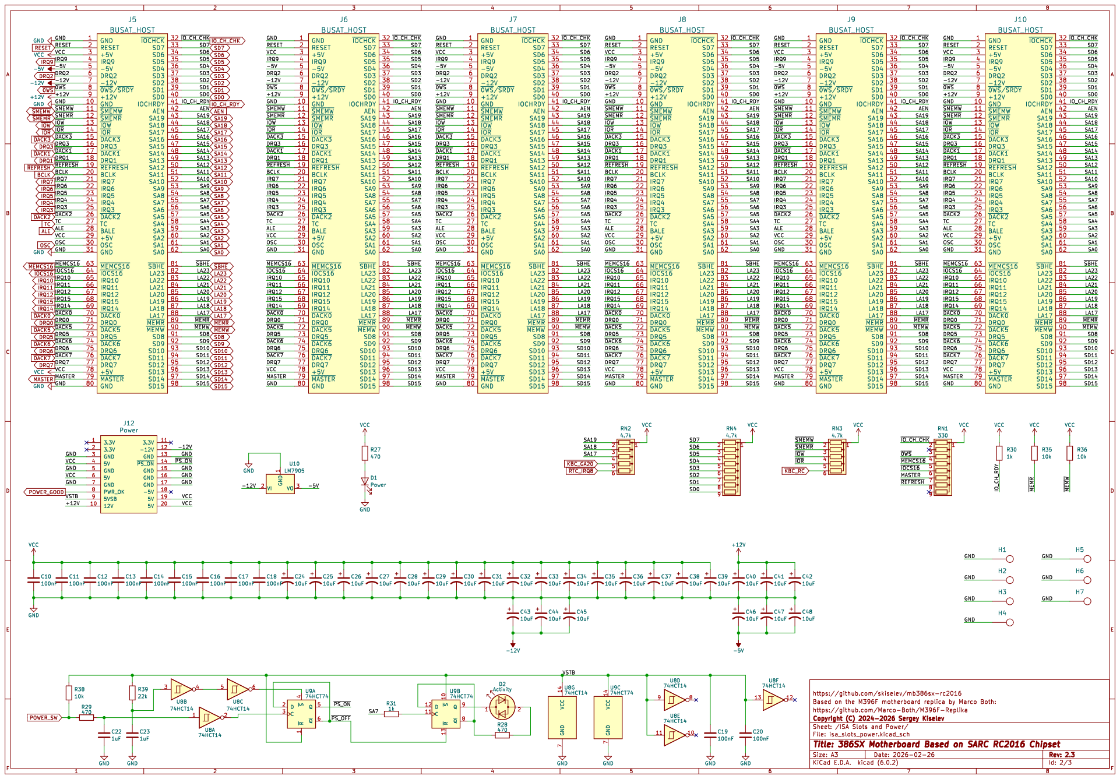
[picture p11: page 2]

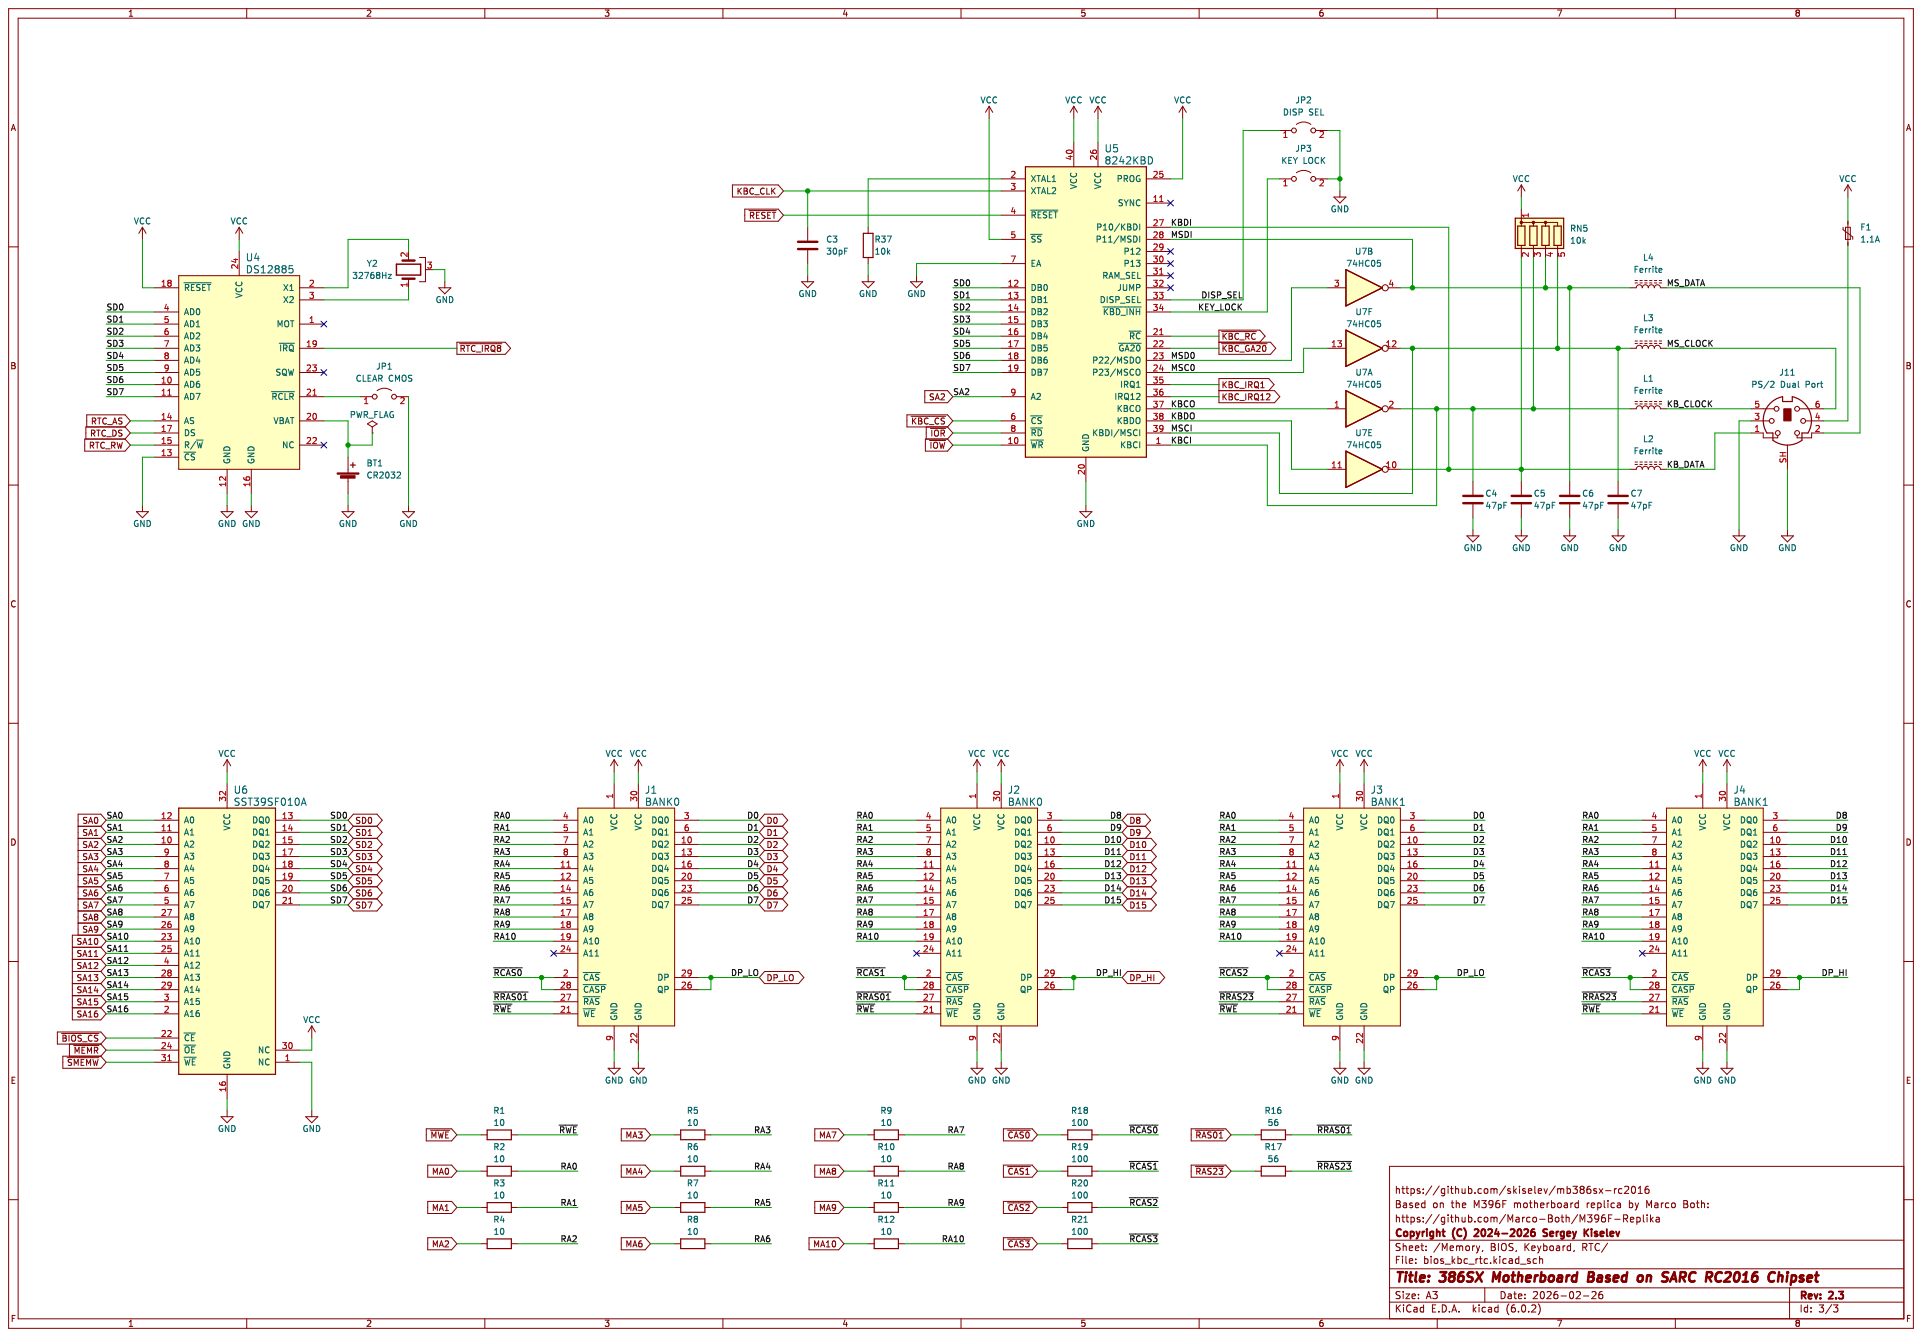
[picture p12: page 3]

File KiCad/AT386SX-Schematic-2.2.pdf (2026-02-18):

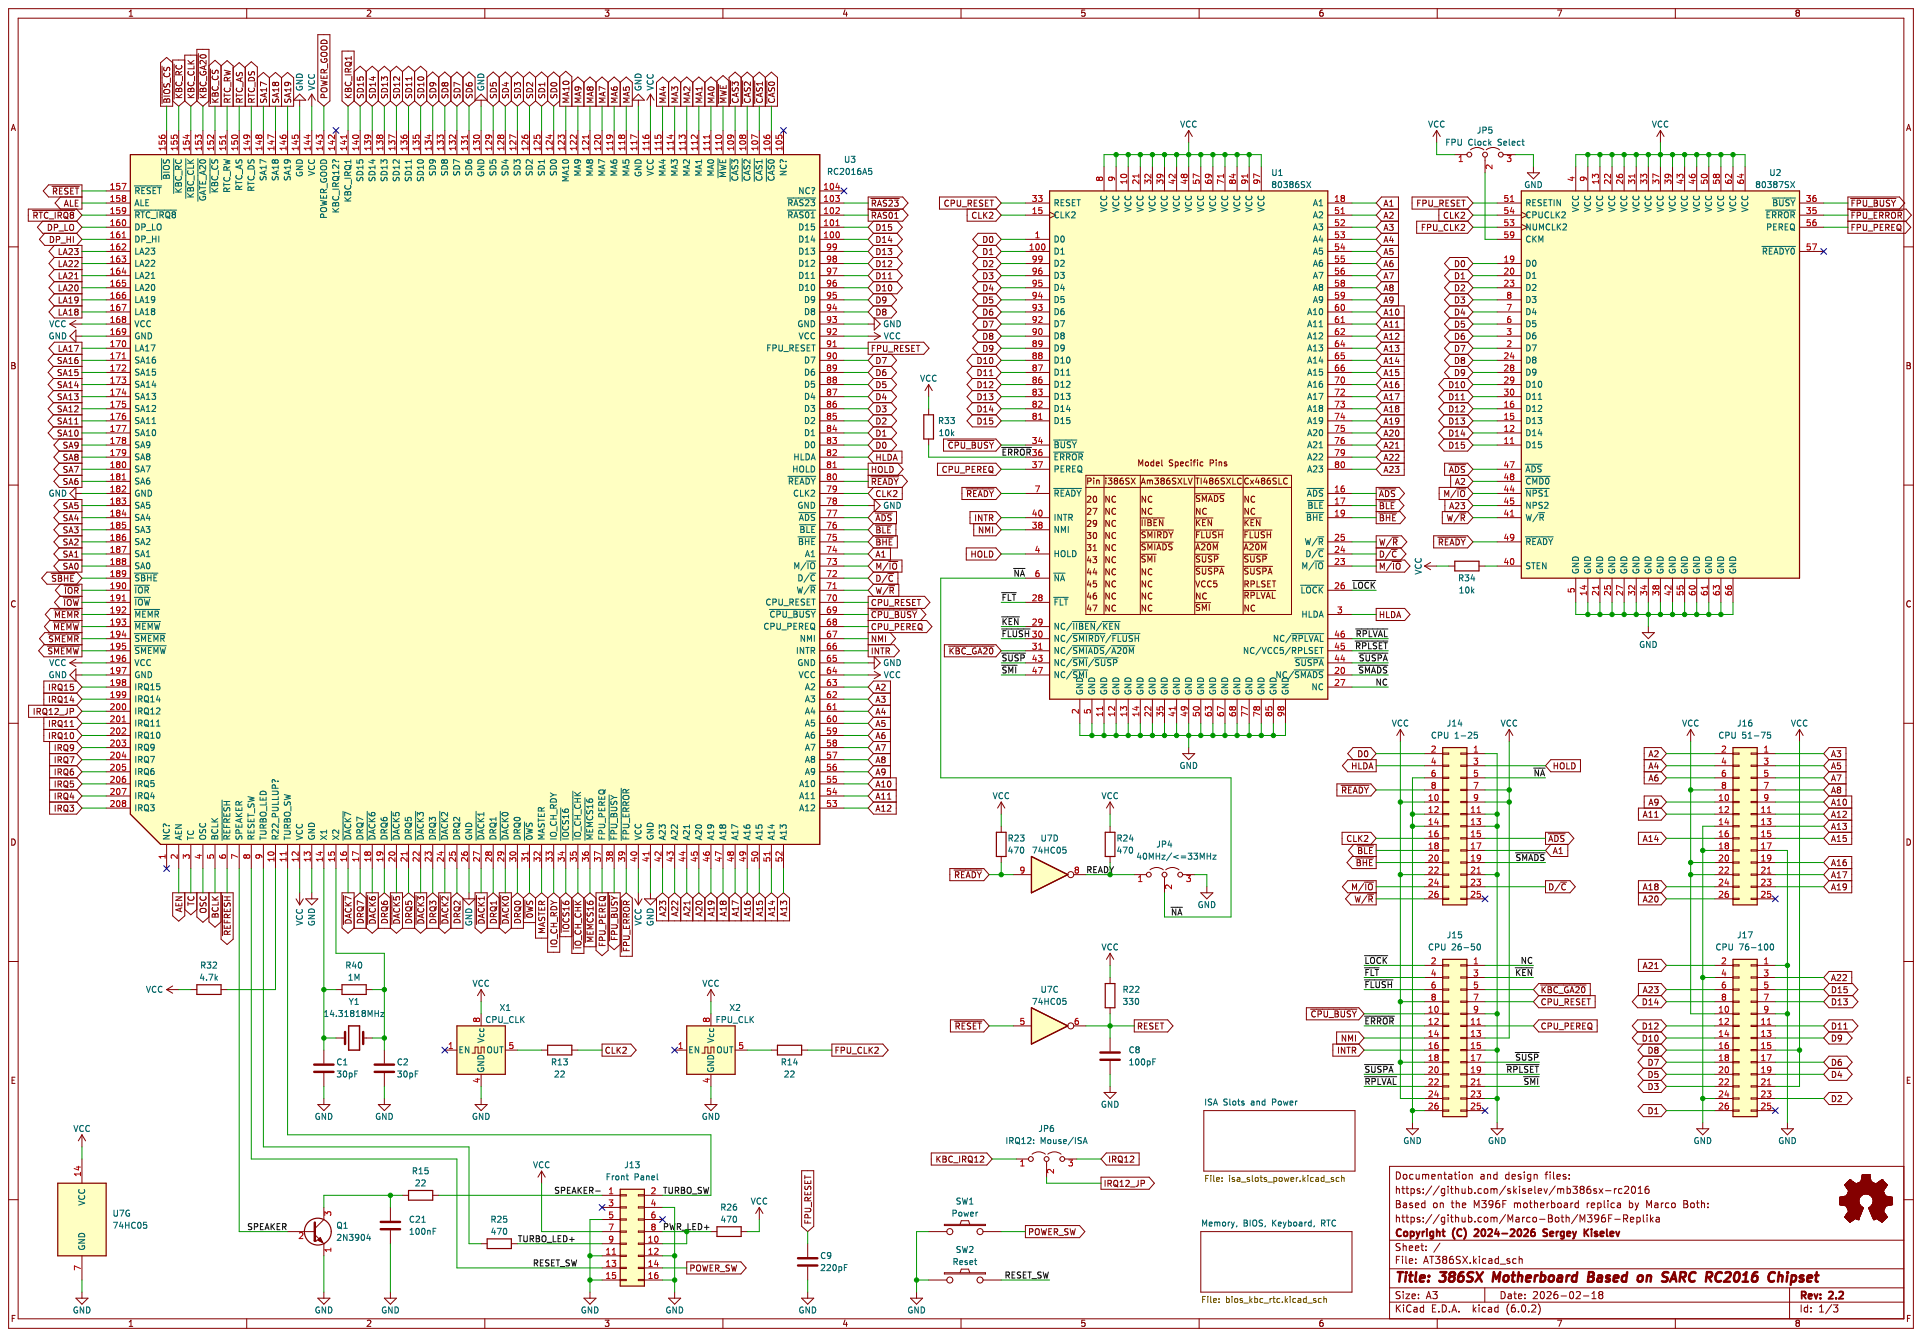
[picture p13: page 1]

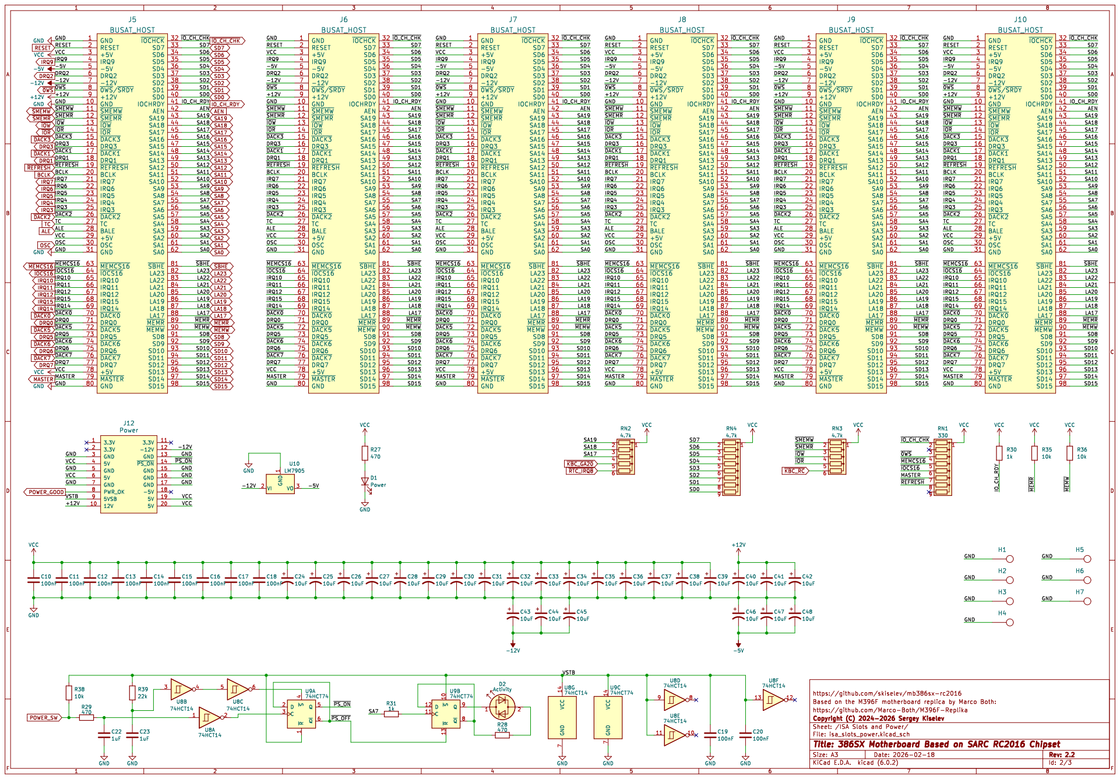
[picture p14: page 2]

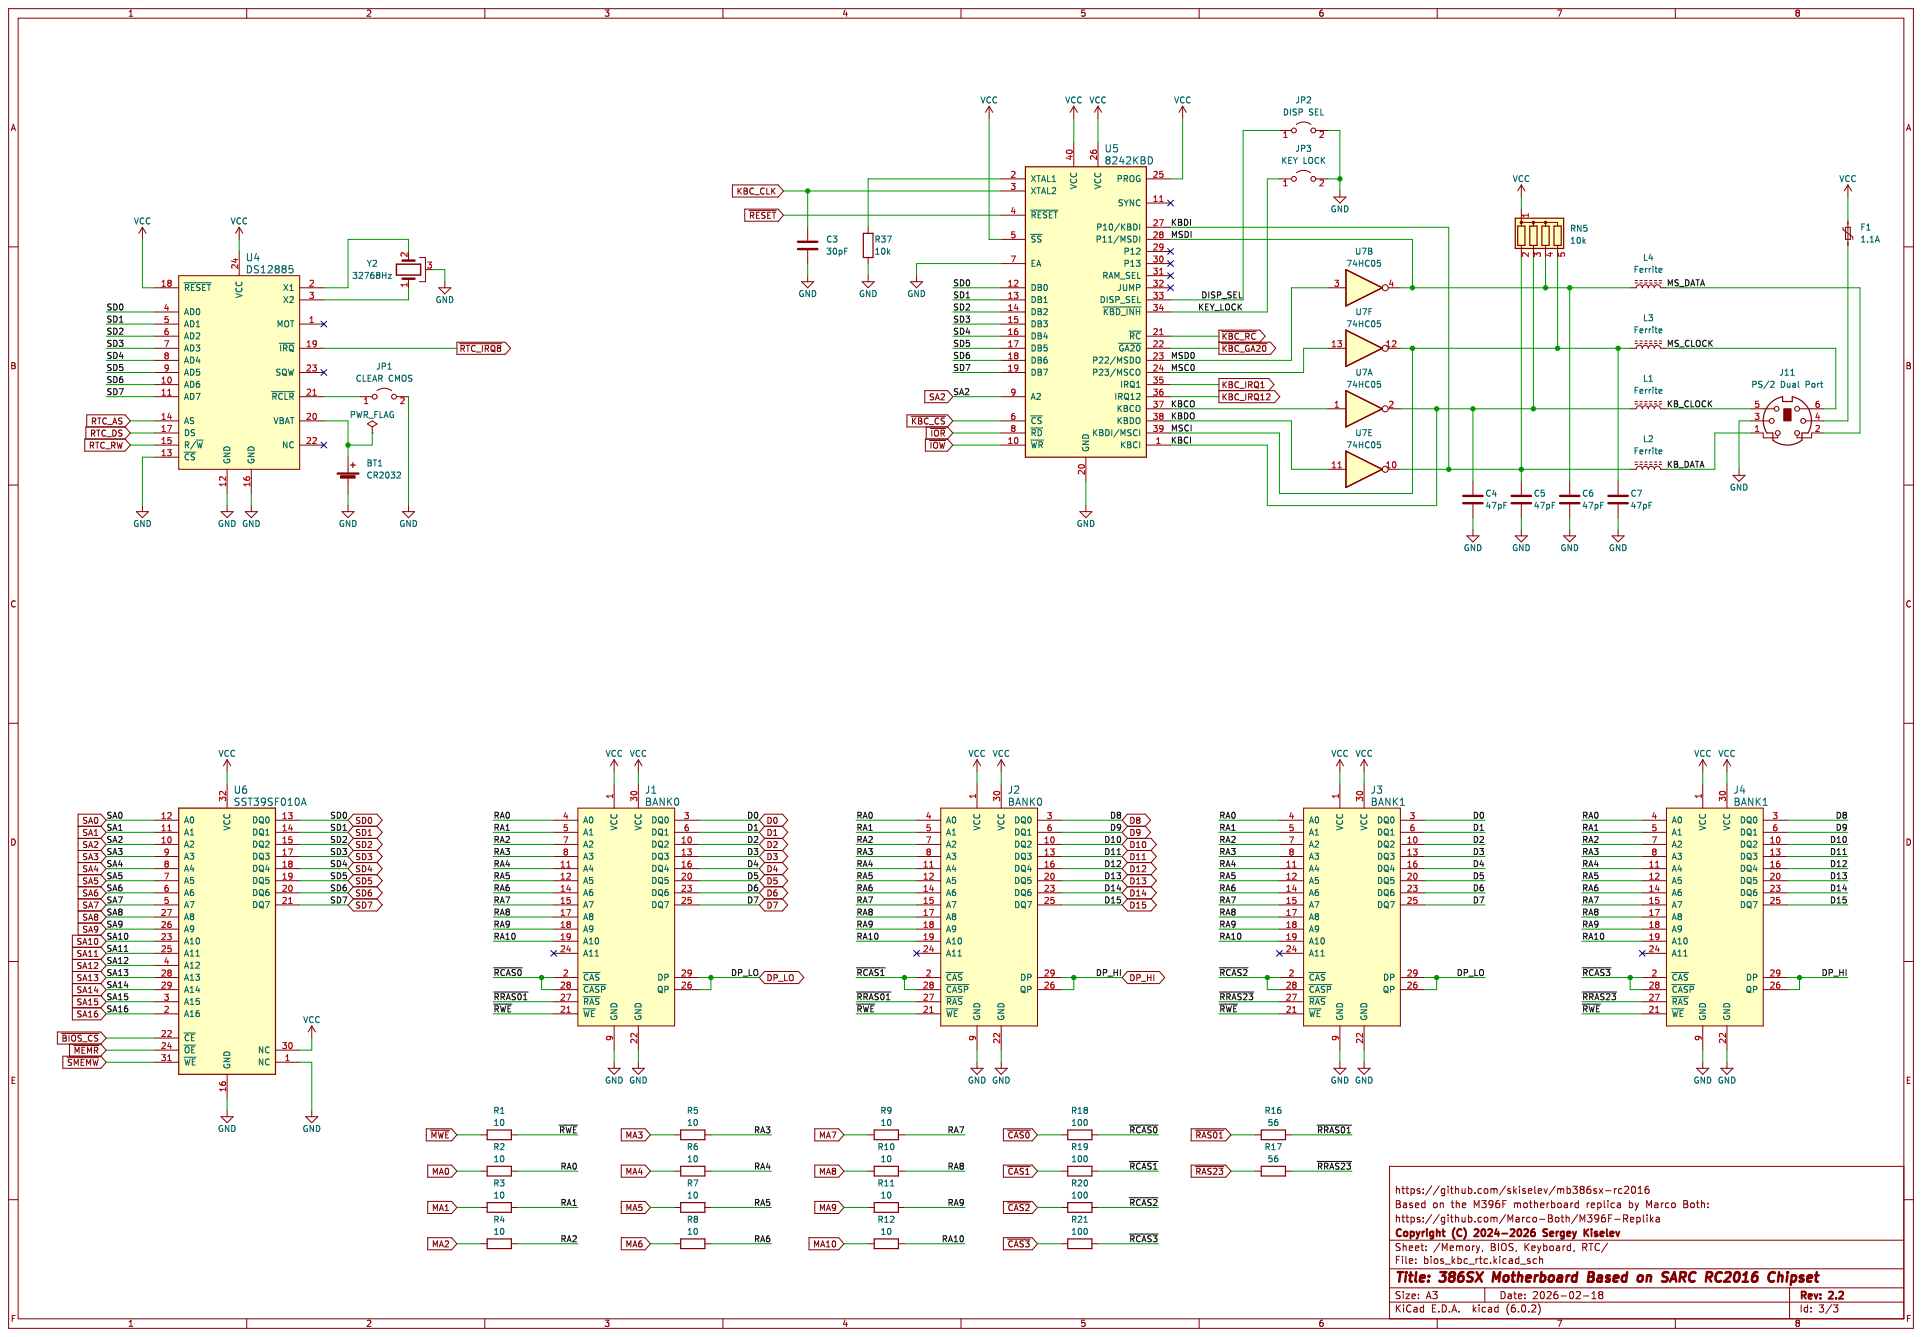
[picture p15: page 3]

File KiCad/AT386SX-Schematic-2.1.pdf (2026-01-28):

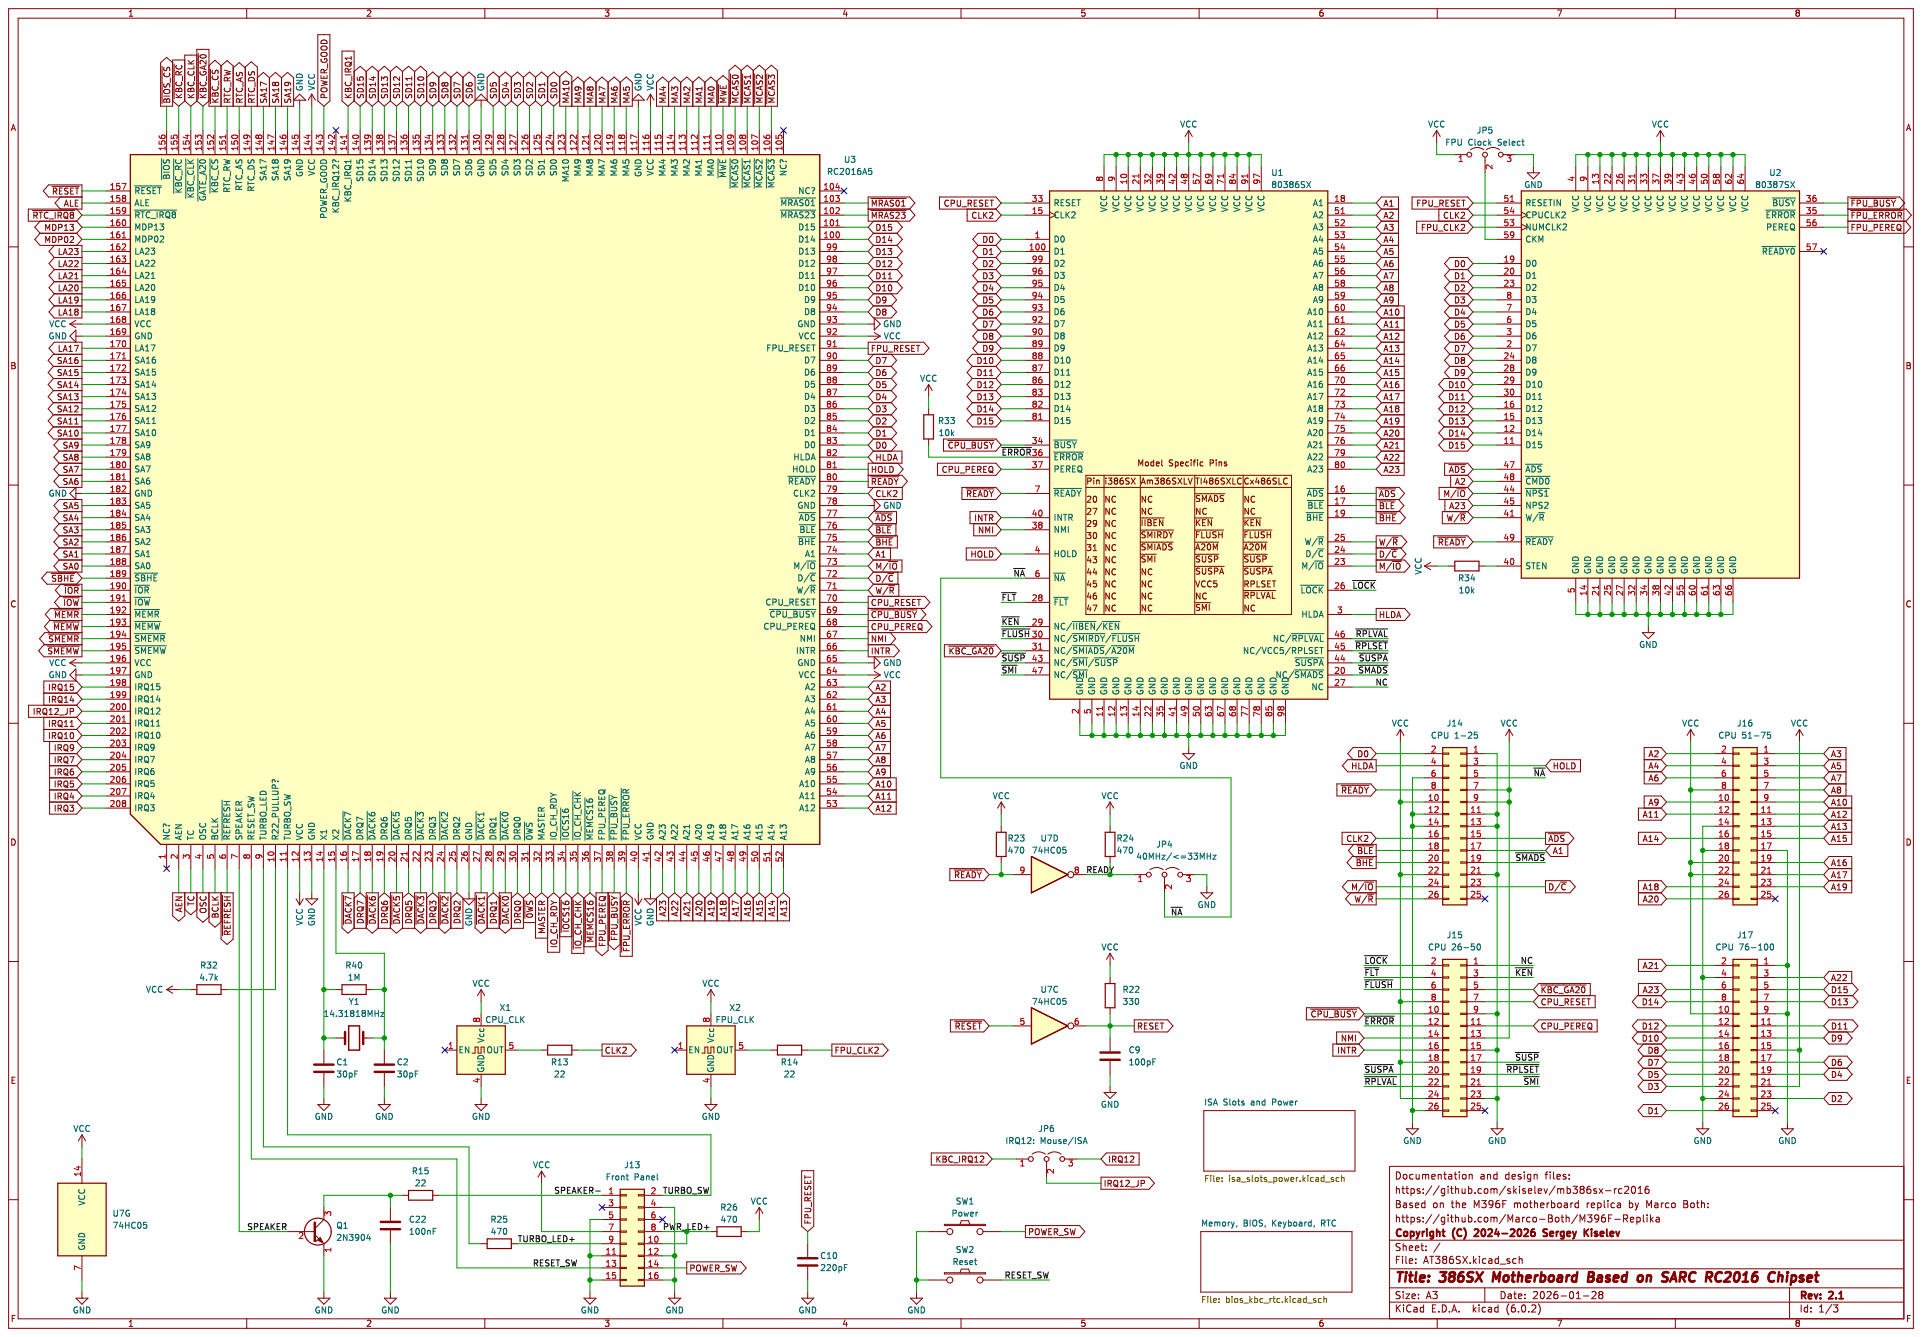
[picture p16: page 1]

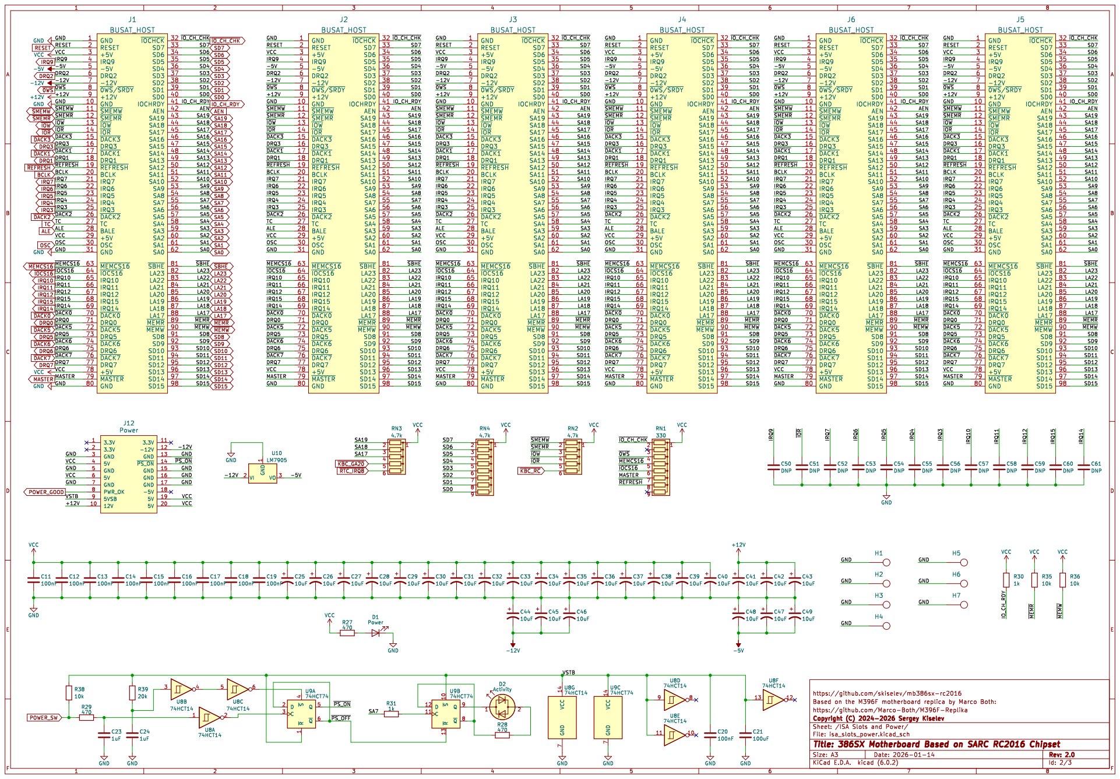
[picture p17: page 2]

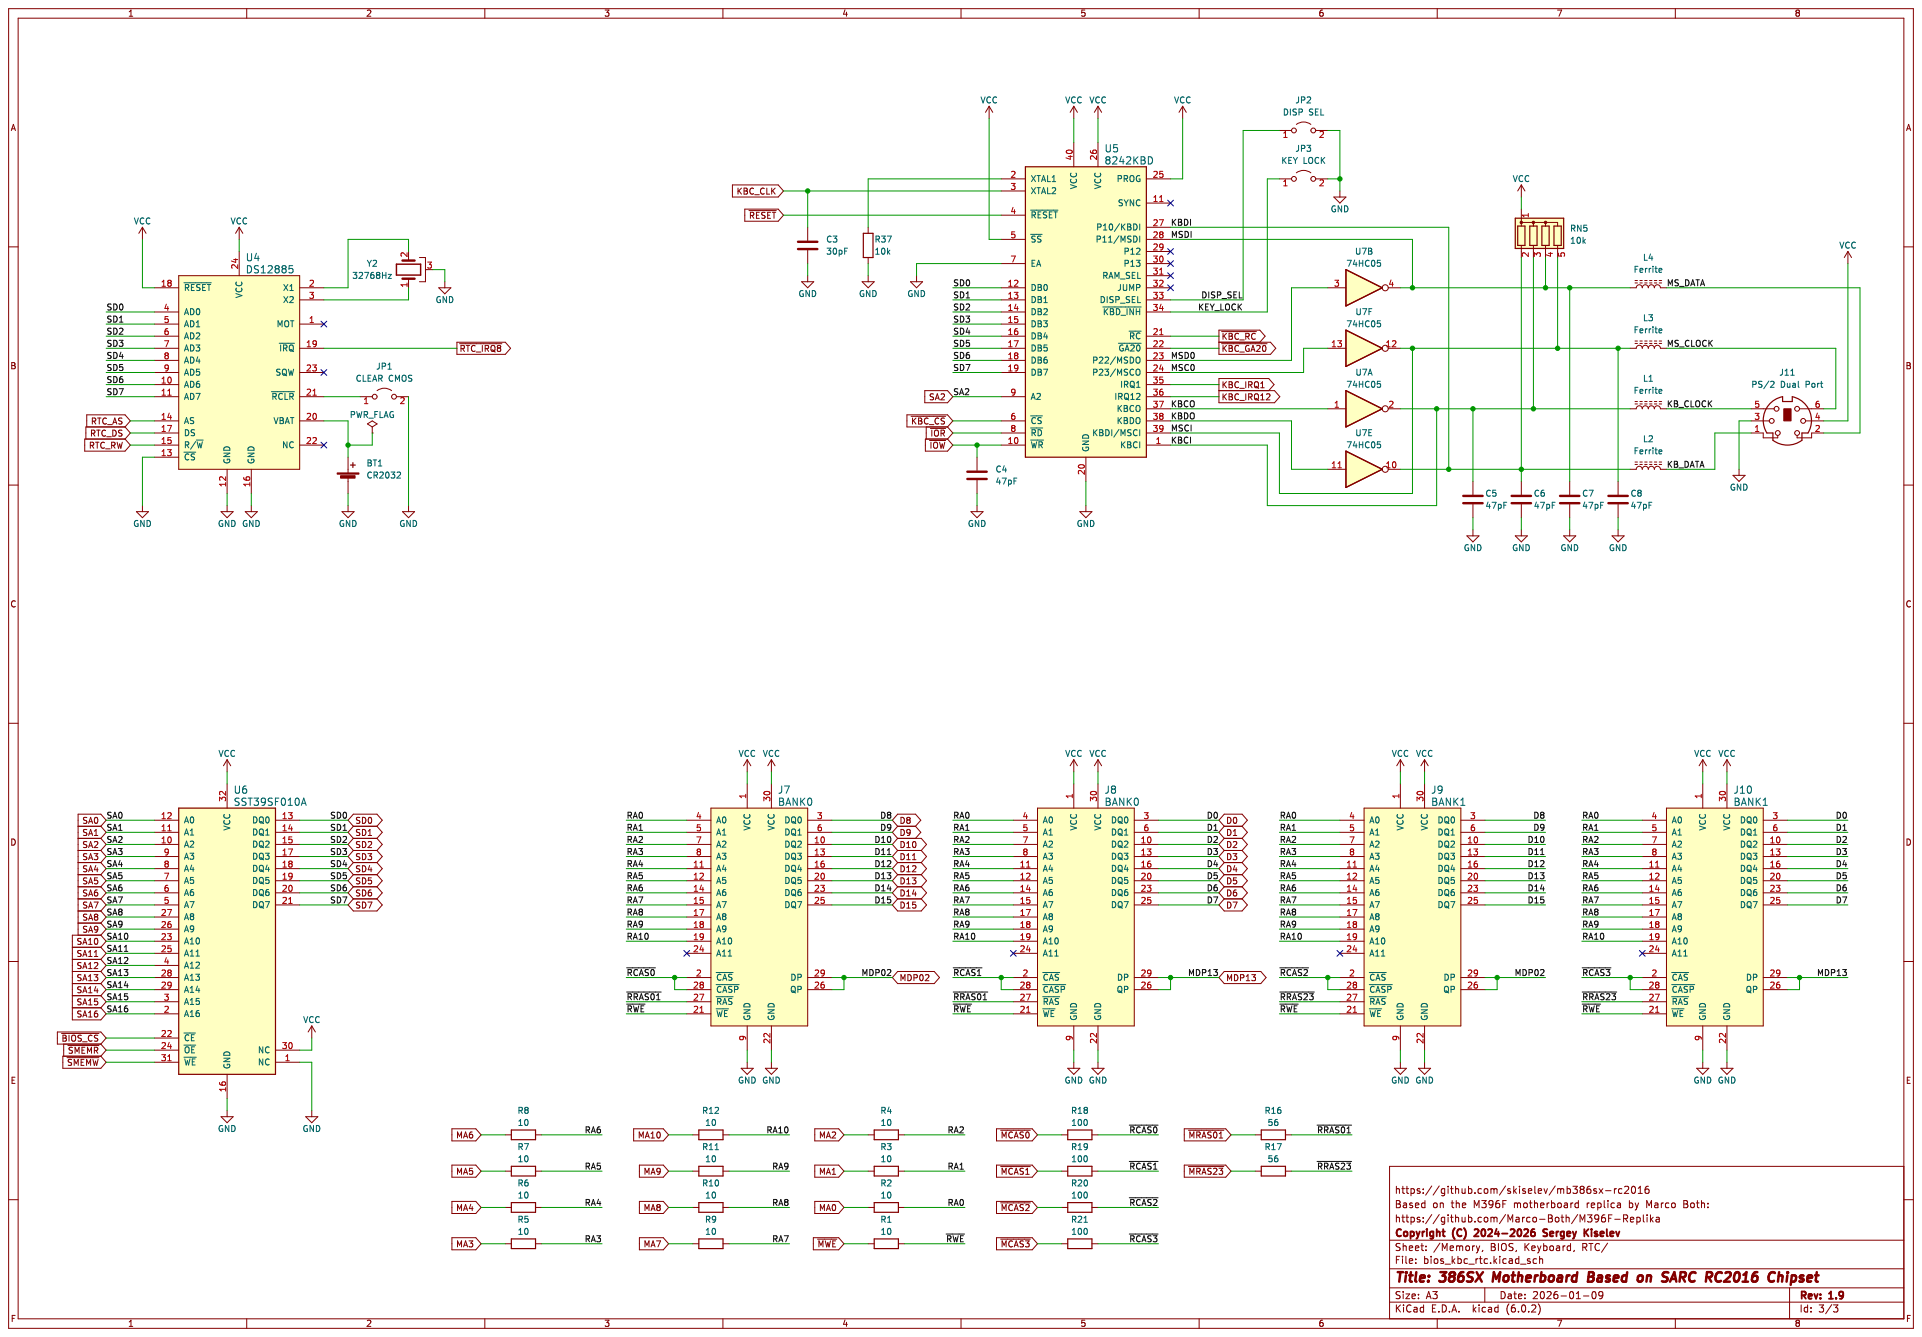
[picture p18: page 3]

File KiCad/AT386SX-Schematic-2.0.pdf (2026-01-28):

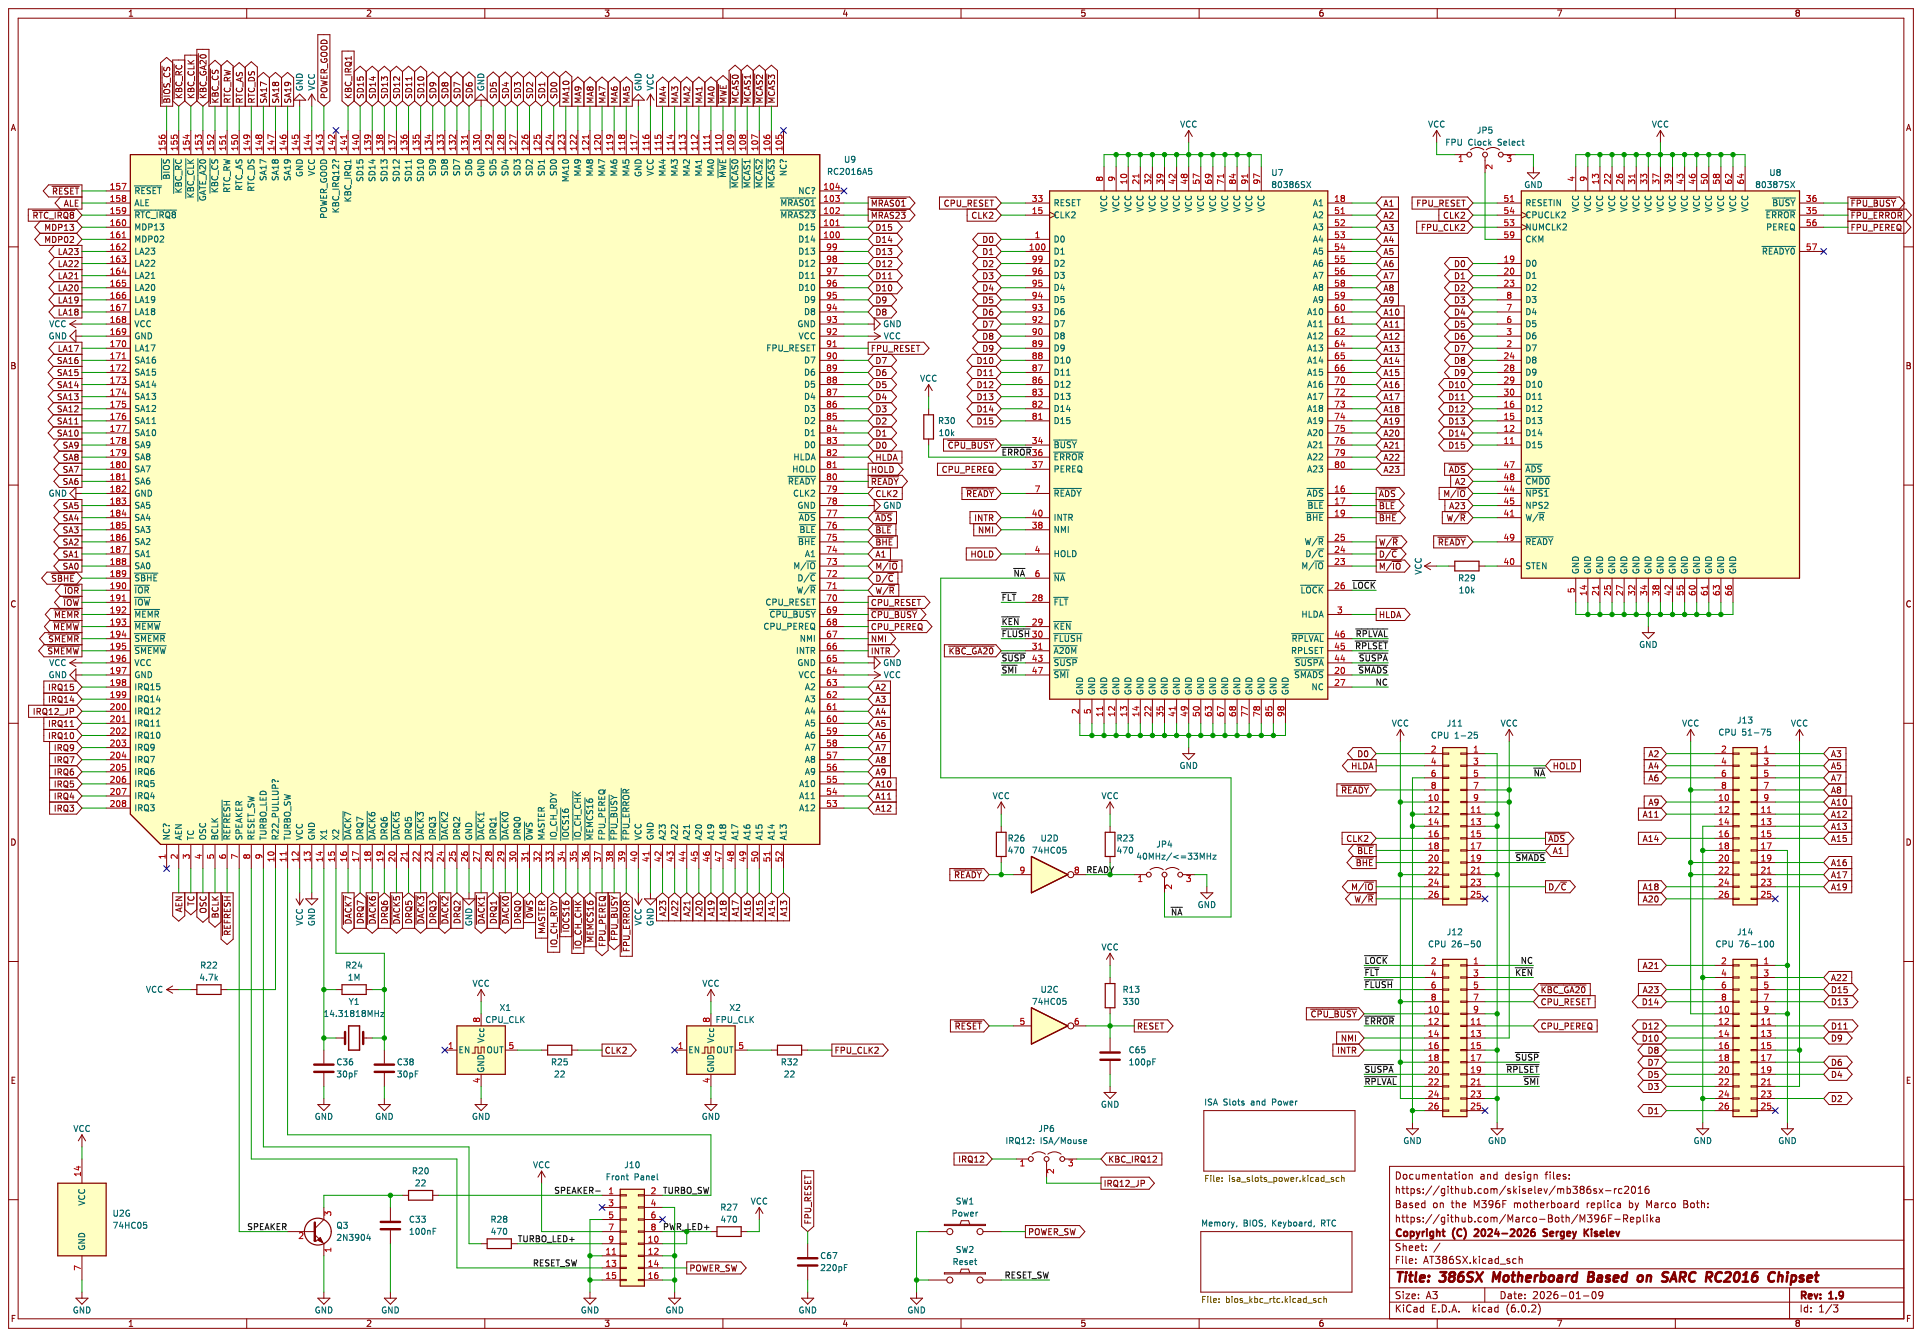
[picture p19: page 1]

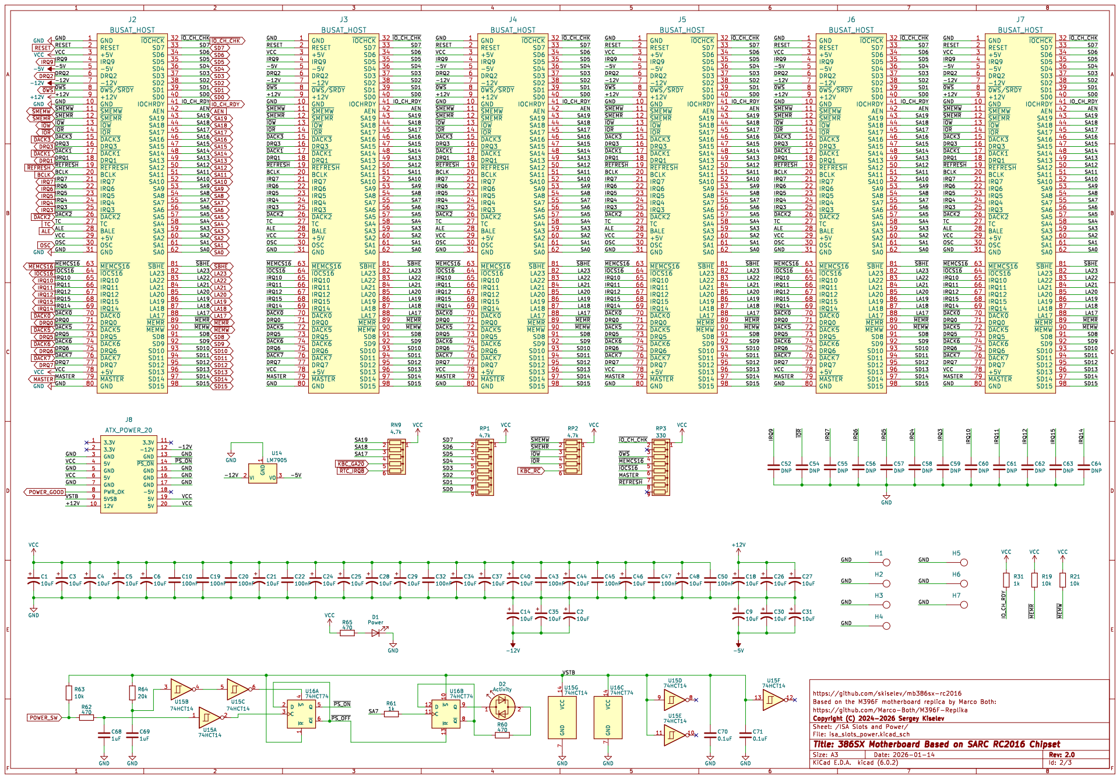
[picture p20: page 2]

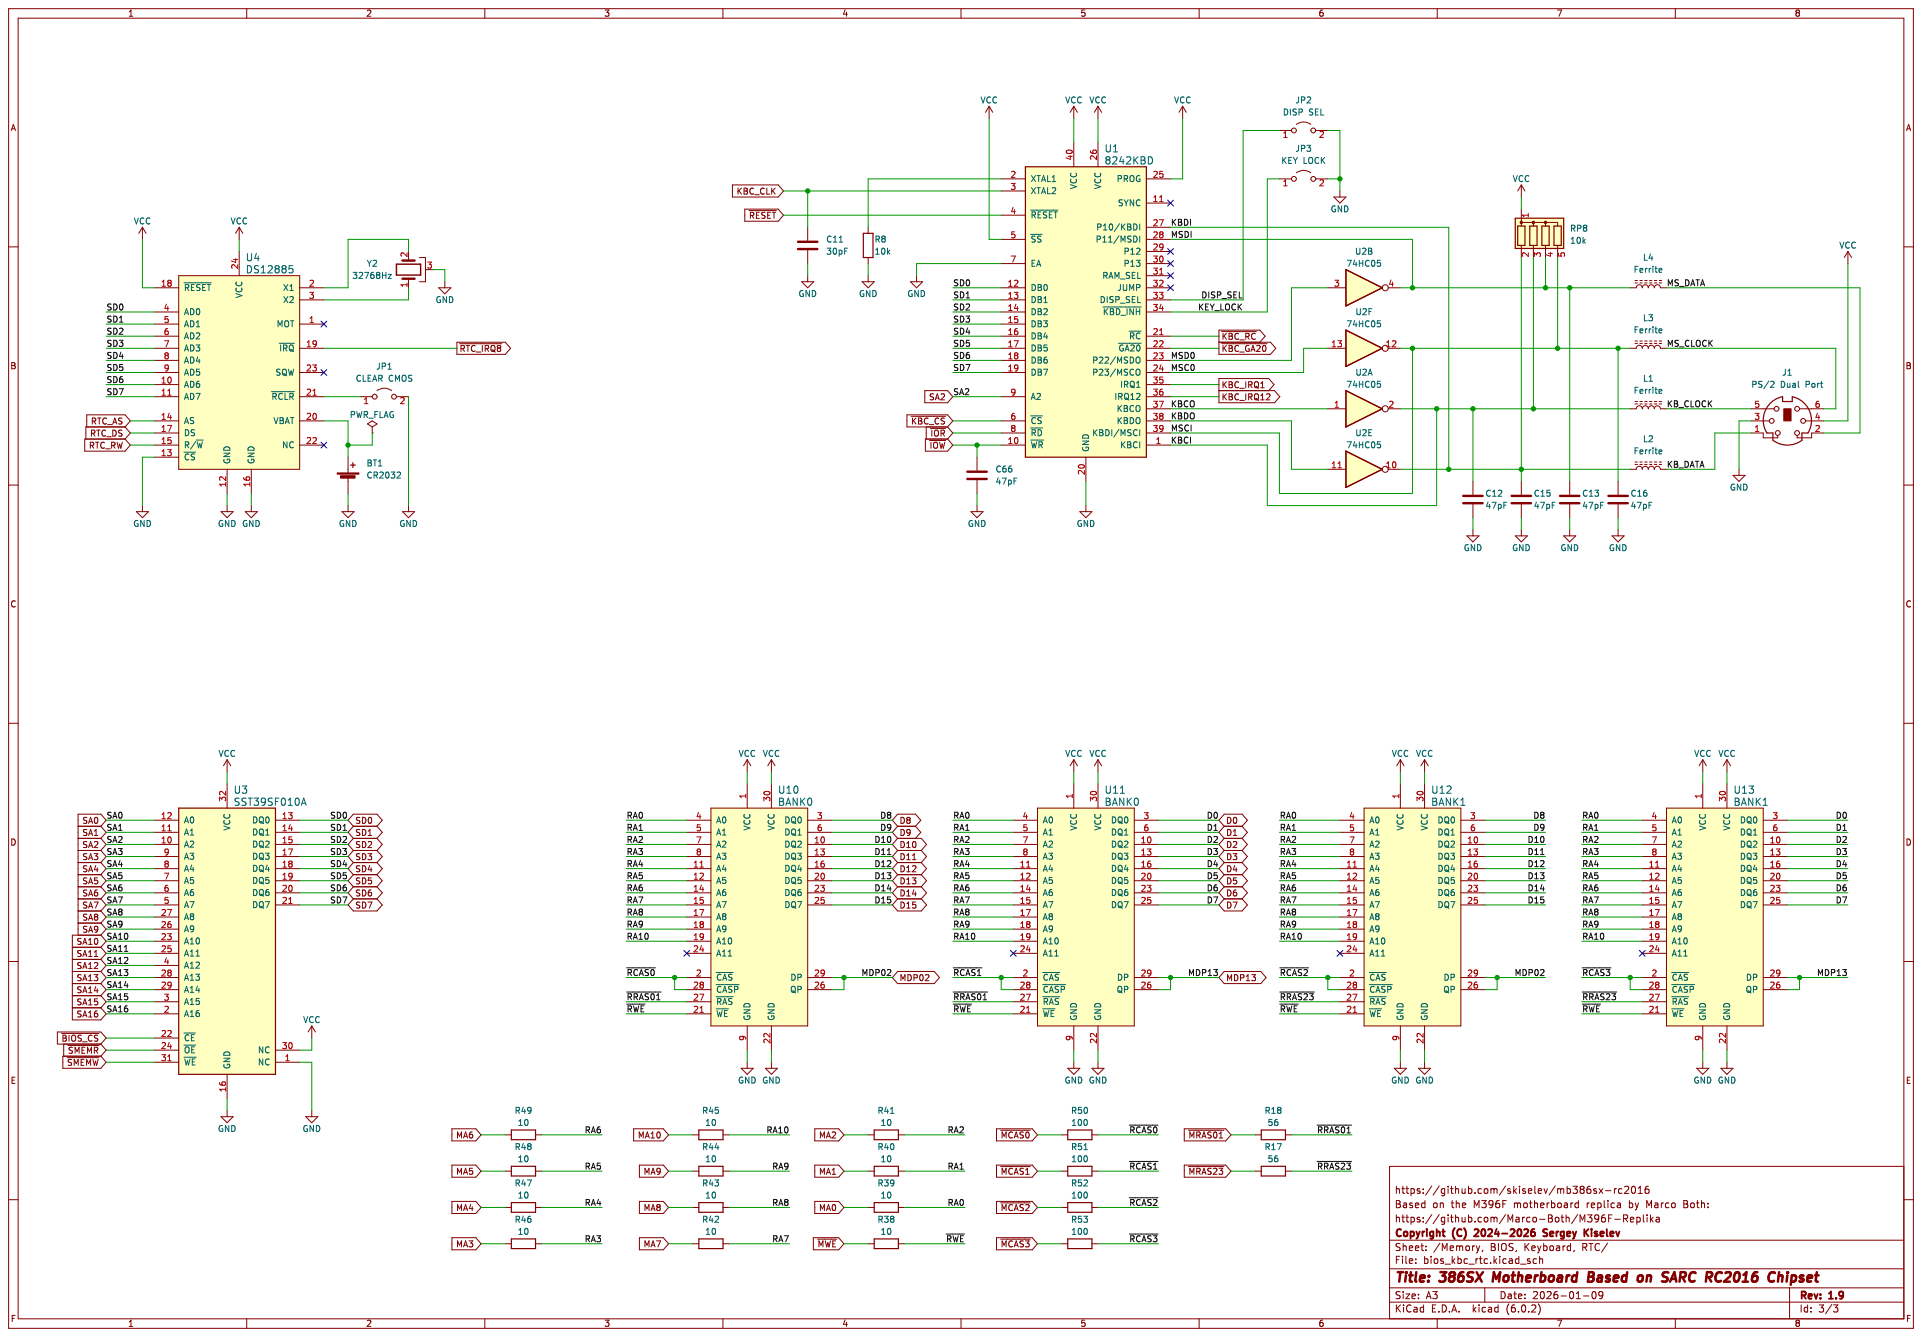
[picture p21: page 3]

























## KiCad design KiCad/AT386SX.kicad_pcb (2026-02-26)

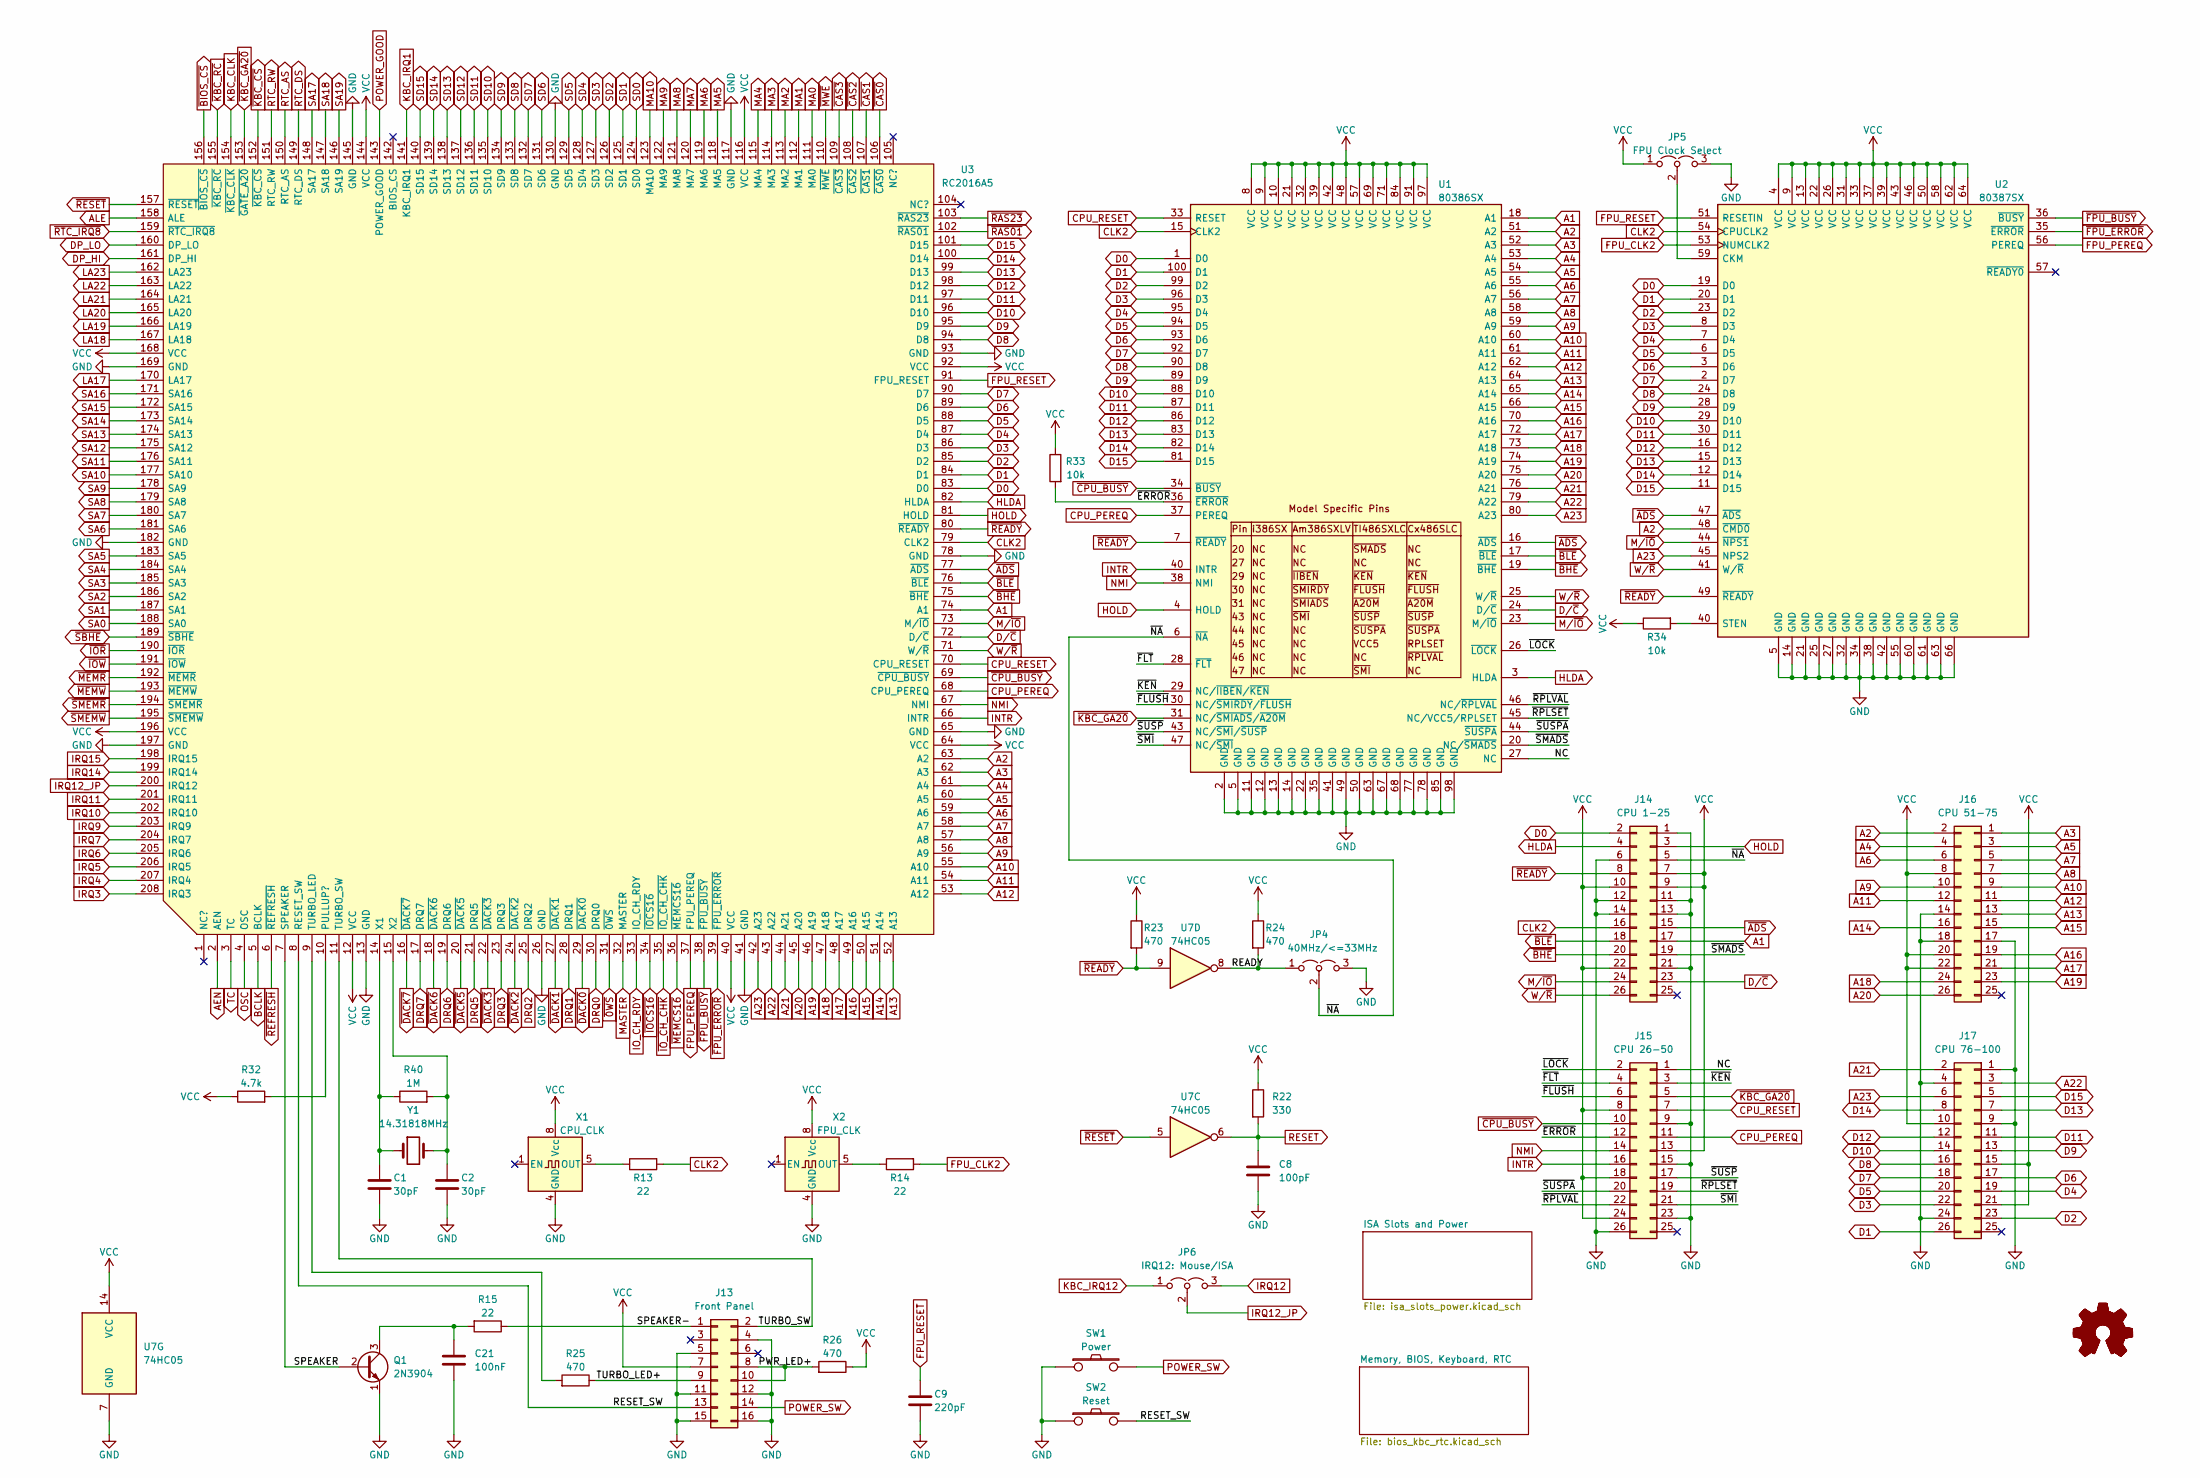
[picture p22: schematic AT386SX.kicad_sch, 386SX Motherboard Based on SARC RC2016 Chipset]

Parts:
C1, C2: 30pF; Cap_Cer_508
C8: 100pF; Cap_Cer_508
C9: 220pF; Cap_Cer_508
C21: 100nF; Cap_Cer_508
J13: Front Panel; Conn_Pin_Header_8x2_2.54mm
J14: CPU 1-25; PinHeader_2x13_P2.00mm_Vertical
J15: CPU 26-50; PinHeader_2x13_P2.00mm_Vertical
J16: CPU 51-75; PinHeader_2x13_P2.00mm_Vertical
J17: CPU 76-100; PinHeader_2x13_P2.00mm_Vertical
JP4: 40MHz/<=33MHz; Conn_Pin_Header_3x1_2.54mm
JP5: FPU Clock Select; Conn_Pin_Header_3x1_2.54mm
JP6: IRQ12: Mouse/ISA; Conn_Pin_Header_3x1_2.54mm
LOGO1: Logo_Open_Hardware_Small; OSHW-Logo2_7.3x6mm_SilkScreen
LOGO2: Logo_Open_Hardware_Small; KiCad-Logo2_5mm_SilkScreen
Q1: 2N3904; Transistor_TO92_EBC_254
R13, R14, R15: 22; Res_762
R22: 330; Res_762
R23, R24, R25, R26: 470; Res_762
R32: 4.7k; Res_762
R33, R34: 10k; Res_762
R40: 1M; Res_762
SW1: Power; Switch_Tactile_6mm
SW2: Reset; Switch_Tactile_6mm
U1: 80386SX; PQFP-100_19x19mm_P0.635mm_i386sx
U2: 80387SX; IC_PLCC68_INTEL_TH
U3: RC2016A5; PQFP-208_28x28mm_P0.5mm
U7: 74HC05; IC_DIP14_300
X1: CPU_CLK; OSC_Half_Can_DIP8
X2: FPU_CLK; OSC_Half_Can_DIP8
Y1: 14.31818MHz; Crystal_HC-49U_Vert

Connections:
/NC: J15.1, U1.27 (NC)
/PWR_LED+: J13.8, J13.10, R26.2
/READY: JP4.1 (A), R24.2, U7.8
/RESET_SW: J13.13, SW2.2, U3.8 (RESET_SW)
/SPEAKER: Q1.2 (B), U3.7 (SPEAKER)
/SPEAKER-: J13.1, R15.1
/TURBO_LED+: J13.9, R25.1
/TURBO_SW: J13.2, U3.11 (TURBO_SW)
/~ERROR: J15.12, R33.2, U1.36 (~ERROR)
/~FLT: J15.4, U1.28 (~FLT)
/~FLUSH: J15.6, U1.30 (NC/~SMIRDY/~FLUSH)
/~KEN: J15.3, U1.29 (NC/~IIBEN/~KEN)
/~LOCK: J15.2, U1.26 (~LOCK)
/~NA: J14.5, JP4.2 (C), U1.6 (~NA)
/~RPLSET: J15.19, U1.45 (NC/VCC5/RPLSET)
/~RPLVAL: J15.22, U1.46 (NC/~RPLVAL)
/~SMADS: J14.19, U1.20 (NC/~SMADS)
/~SMI: J15.21, U1.47 (NC/~SMI)
/~SUSPA: J15.20, U1.44 (~SUSPA)
/~SUSP: J15.17, U1.43 (NC/~SMI/~SUSP)
A1: J14.17, U1.18 (A1), U3.74 (A1)
A2: J16.2, U1.51 (A2), U2.48 (~CMD0), U3.63 (A2)
A3: J16.1, U1.52 (A3), U3.62 (A3)
A4: J16.4, U1.53 (A4), U3.61 (A4)
A5: J16.3, U1.54 (A5), U3.60 (A5)
A6: J16.6, U1.55 (A6), U3.59 (A6)
A7: J16.5, U1.56 (A7), U3.58 (A7)
A8: J16.7, U1.58 (A8), U3.57 (A8)
A9: J16.10, U1.59 (A9), U3.56 (A9)
A10: J16.9, U1.60 (A10), U3.55 (A10)
A11: J16.12, U1.61 (A11), U3.54 (A11)
A12: J16.11, U1.62 (A12), U3.53 (A12)
A13: J16.13, U1.64 (A13), U3.52 (A13)
A14: J16.16, U1.65 (A14), U3.51 (A14)
A15: J16.15, U1.66 (A15), U3.50 (A15)
A16: J16.19, U1.70 (A16), U3.49 (A16)
A17: J16.21, U1.72 (A17), U3.48 (A17)
A18: J16.24, U1.73 (A18), U3.47 (A18)
A19: J16.23, U1.74 (A19), U3.46 (A19)
A20: J16.26, U1.75 (A20), U3.45 (A20)
A21: J17.2, U1.76 (A21), U3.44 (A21)
A22: J17.3, U1.79 (A22), U3.43 (A22)
A23: J17.6, U1.80 (A23), U2.45 (NPS2), U3.42 (A23)
AEN: U3.2 (AEN); also elsewhere on the board
ALE: U3.158 (ALE); also elsewhere on the board
BCLK: U3.5 (BCLK); also elsewhere on the board
CLK2: J14.16, R13.2, U1.15 (CLK2), U2.54 (CPUCLK2), U3.79 (CLK2)
CPU_PEREQ: J15.11, U1.37 (PEREQ), U3.68 (CPU_PEREQ)
CPU_RESET: J15.7, U1.33 (RESET), U3.70 (CPU_RESET)
D0: J14.2, U1.1 (D0), U2.19 (D0), U3.83 (D0); also elsewhere on the board
D1: J17.26, U1.100 (D1), U2.20 (D1), U3.84 (D1); also elsewhere on the board
D2: J17.23, U1.99 (D2), U2.23 (D2), U3.85 (D2); also elsewhere on the board
D3: J17.22, U1.96 (D3), U2.8 (D3), U3.86 (D3); also elsewhere on the board
D4: J17.19, U1.95 (D4), U2.7 (D4), U3.87 (D4); also elsewhere on the board
D5: J17.20, U1.94 (D5), U2.6 (D5), U3.88 (D5); also elsewhere on the board
D6: J17.17, U1.93 (D6), U2.3 (D6), U3.89 (D6); also elsewhere on the board
D7: J17.18, U1.92 (D7), U2.2 (D7), U3.90 (D7); also elsewhere on the board
D8: J17.16, U1.90 (D8), U2.24 (D8), U3.94 (D8); also elsewhere on the board
D9: J17.13, U1.89 (D9), U2.28 (D9), U3.95 (D9); also elsewhere on the board
D10: J17.14, U1.88 (D10), U2.29 (D10), U3.96 (D10); also elsewhere on the board
D11: J17.11, U1.87 (D11), U2.30 (D11), U3.97 (D11); also elsewhere on the board
D12: J17.12, U1.86 (D12), U2.16 (D12), U3.98 (D12); also elsewhere on the board
D13: J17.7, U1.83 (D13), U2.15 (D13), U3.99 (D13); also elsewhere on the board
D14: J17.8, U1.82 (D14), U2.12 (D14), U3.100 (D14); also elsewhere on the board
D15: J17.5, U1.81 (D15), U2.11 (D15), U3.101 (D15); also elsewhere on the board
DP_HI: U3.161 (DP_HI); also elsewhere on the board
DP_LO: U3.160 (DP_LO); also elsewhere on the board
DRQ0: U3.30 (DRQ0); also elsewhere on the board
DRQ1: U3.28 (DRQ1); also elsewhere on the board
DRQ2: U3.25 (DRQ2); also elsewhere on the board
DRQ3: U3.23 (DRQ3); also elsewhere on the board
DRQ5: U3.21 (DRQ5); also elsewhere on the board
DRQ6: U3.19 (DRQ6); also elsewhere on the board
DRQ7: U3.17 (DRQ7); also elsewhere on the board
D/~C: J14.23, U1.24 (D/~C), U3.72 (D/~C)
FPU_CLK2: R14.2, U2.53 (NUMCLK2)
FPU_PEREQ: U2.56 (PEREQ), U3.37 (FPU_PEREQ)
FPU_RESET: C9.1, U2.51 (RESETIN), U3.91 (FPU_RESET)
GND: C1.2, C2.2, C8.2, C9.2, C21.2, J13.4, J13.5, J13.11, J13.12, J13.15, J13.16, J14.1, J14.6, J14.11, J14.12, J14.13, J14.14, J14.21, J15.9, J15.15, J15.23, J15.26, J16.14, J16.17, J16.18, J17.1, J17.4, J17.9, J17.24, JP4.3 (B), JP5.3 (B), Q1.1 (E), SW1.1, SW2.1, U1.2 (GND), U1.5 (GND), U1.11 (GND), U1.12 (GND), U1.13 (GND), U1.14 (GND), U1.22 (GND), U1.35 (GND), U1.41 (GND), U1.49 (GND), U1.50 (GND), U1.63 (GND), U1.67 (GND), U1.68 (GND), U1.77 (GND), U1.78 (GND), U1.85 (GND), U1.98 (GND), U2.5 (GND), U2.14 (GND), U2.21 (GND), U2.25 (GND), U2.27 (GND), U2.32 (GND), U2.34 (GND), U2.38 (GND), U2.42 (GND), U2.55 (GND), U2.60 (GND), U2.61 (GND), U2.63 (GND), U2.66 (GND), U3.13 (GND), U3.26 (GND), U3.41 (GND), U3.65 (GND), U3.78 (GND), U3.93 (GND), U3.117 (GND), U3.130 (GND), U3.145 (GND), U3.169 (GND), U3.182 (GND), U3.197 (GND), U7.7 (GND), X1.4 (GND), X2.4 (GND); also elsewhere on the board
HLDA: J14.4, U1.3 (HLDA), U3.82 (HLDA)
HOLD: J14.3, U1.4 (HOLD), U3.81 (HOLD)
INTR: J15.16, U1.40 (INTR), U3.66 (INTR)
IO_CH_RDY: U3.33 (IO_CH_RDY); also elsewhere on the board
IRQ3: U3.208 (IRQ3); also elsewhere on the board
IRQ4: U3.207 (IRQ4); also elsewhere on the board
IRQ5: U3.206 (IRQ5); also elsewhere on the board
IRQ6: U3.205 (IRQ6); also elsewhere on the board
IRQ7: U3.204 (IRQ7); also elsewhere on the board
IRQ9: U3.203 (IRQ9); also elsewhere on the board
IRQ10: U3.202 (IRQ10); also elsewhere on the board
IRQ11: U3.201 (IRQ11); also elsewhere on the board
IRQ12: JP6.3 (B); also elsewhere on the board
IRQ12_JP: JP6.2 (C), U3.200 (IRQ12)
IRQ14: U3.199 (IRQ14); also elsewhere on the board
IRQ15: U3.198 (IRQ15); also elsewhere on the board
KBC_CLK: U3.154 (~KBC_CLK); also elsewhere on the board
KBC_IRQ1: U3.141 (KBC_IRQ1); also elsewhere on the board
KBC_IRQ12: JP6.1 (A); also elsewhere on the board
LA17: U3.170 (LA17); also elsewhere on the board
LA18: U3.167 (LA18); also elsewhere on the board
LA19: U3.166 (LA19); also elsewhere on the board
LA20: U3.165 (LA20); also elsewhere on the board
LA21: U3.164 (LA21); also elsewhere on the board
LA22: U3.163 (LA22); also elsewhere on the board
LA23: U3.162 (LA23); also elsewhere on the board
MA0: U3.111 (MA0); also elsewhere on the board
MA1: U3.112 (MA1); also elsewhere on the board
MA2: U3.113 (MA2); also elsewhere on the board
MA3: U3.114 (MA3); also elsewhere on the board
MA4: U3.115 (MA4); also elsewhere on the board
MA5: U3.118 (MA5); also elsewhere on the board
MA6: U3.119 (MA6); also elsewhere on the board
MA7: U3.120 (MA7); also elsewhere on the board
MA8: U3.121 (MA8); also elsewhere on the board
MA9: U3.122 (MA9); also elsewhere on the board
MA10: U3.123 (MA10); also elsewhere on the board
MASTER: U3.32 (MASTER); also elsewhere on the board
M/~IO: J14.24, U1.23 (M/~IO), U2.44 (~NPS1), U3.73 (M/~IO)
NMI: J15.14, U1.38 (NMI), U3.67 (NMI)
unnamed: C1.1, R40.1, U3.14 (X1), Y1.1
unnamed: C2.1, R40.2, U3.15 (X2), Y1.2
unnamed: C21.1, Q1.3 (C), R15.2
unnamed: JP5.2 (C), U2.59 (CKM)
unnamed: R13.1, X1.5 (OUT)
unnamed: R14.1, X2.5 (OUT)
unnamed: R25.2, U3.9 (TURBO_LED)
unnamed: R32.2, U3.10 (PULLUP?)
unnamed: R34.2, U2.40 (STEN)
OSC: U3.4 (OSC); also elsewhere on the board
POWER_GOOD: U3.143 (POWER_GOOD); also elsewhere on the board
POWER_SW: J13.14, SW1.2; also elsewhere on the board
RESET: C8.1, R22.2, U7.6; also elsewhere on the board
RTC_AS: U3.150 (RTC_AS); also elsewhere on the board
RTC_DS: U3.149 (RTC_DS); also elsewhere on the board
RTC_RW: U3.151 (RTC_RW); also elsewhere on the board
SA0: U3.188 (SA0); also elsewhere on the board
SA1: U3.187 (SA1); also elsewhere on the board
SA2: U3.186 (SA2); also elsewhere on the board
SA3: U3.185 (SA3); also elsewhere on the board
SA4: U3.184 (SA4); also elsewhere on the board
SA5: U3.183 (SA5); also elsewhere on the board
SA6: U3.181 (SA6); also elsewhere on the board
SA7: U3.180 (SA7); also elsewhere on the board
SA8: U3.179 (SA8); also elsewhere on the board
SA9: U3.178 (SA9); also elsewhere on the board
SA10: U3.177 (SA10); also elsewhere on the board
SA11: U3.176 (SA11); also elsewhere on the board
SA12: U3.175 (SA12); also elsewhere on the board
SA13: U3.174 (SA13); also elsewhere on the board
SA14: U3.173 (SA14); also elsewhere on the board
SA15: U3.172 (SA15); also elsewhere on the board
SA16: U3.171 (SA16); also elsewhere on the board
SA17: U3.148 (SA17); also elsewhere on the board
SA18: U3.147 (SA18); also elsewhere on the board
SA19: U3.146 (SA19); also elsewhere on the board
SD0: U3.124 (SD0); also elsewhere on the board
SD1: U3.125 (SD1); also elsewhere on the board
SD2: U3.126 (SD2); also elsewhere on the board
SD3: U3.127 (SD3); also elsewhere on the board
SD4: U3.128 (SD4); also elsewhere on the board
SD5: U3.129 (SD5); also elsewhere on the board
SD6: U3.131 (SD6); also elsewhere on the board
SD7: U3.132 (SD7); also elsewhere on the board
SD8: U3.133 (SD8); also elsewhere on the board
SD9: U3.134 (SD9); also elsewhere on the board
SD10: U3.135 (SD10); also elsewhere on the board
SD11: U3.136 (SD11); also elsewhere on the board
SD12: U3.137 (SD12); also elsewhere on the board
SD13: U3.138 (SD13); also elsewhere on the board
SD14: U3.139 (SD14); also elsewhere on the board
SD15: U3.140 (SD15); also elsewhere on the board
TC: U3.3 (TC); also elsewhere on the board
VCC: J13.7, J14.7, J14.9, J14.10, J14.22, J15.8, J15.13, J15.18, J15.24, J16.8, J16.20, J16.22, J17.10, J17.15, J17.21, JP5.1 (A), R22.1, R23.1, R24.1, R26.1, R32.1, R33.1, R34.1, U1.8 (VCC), U1.9 (VCC), U1.10 (VCC), U1.21 (VCC), U1.32 (VCC), U1.39 (VCC), U1.42 (VCC), U1.48 (VCC), U1.57 (VCC), U1.69 (VCC), U1.71 (VCC), U1.84 (VCC), U1.91 (VCC), U1.97 (VCC), U2.4 (VCC), U2.9 (VCC), U2.13 (VCC), U2.22 (VCC), U2.26 (VCC), U2.31 (VCC), U2.33 (VCC), U2.37 (VCC), U2.39 (VCC), U2.43 (VCC), U2.46 (VCC), U2.50 (VCC), U2.58 (VCC), U2.62 (VCC), U2.64 (VCC), U3.12 (VCC), U3.40 (VCC), U3.64 (VCC), U3.92 (VCC), U3.116 (VCC), U3.144 (VCC), U3.168 (VCC), U3.196 (VCC), U7.14 (VCC), X1.8 (Vcc), X2.8 (Vcc); also elsewhere on the board
W/~R: J14.26, U1.25 (W/~R), U2.41 (W/~R), U3.71 (W/~R)
~0WS: U3.31 (~0WS); also elsewhere on the board
~ADS: J14.15, U1.16 (~ADS), U2.47 (~ADS), U3.77 (~ADS)
~BHE: J14.20, U1.19 (~BHE), U3.75 (~BHE)
~BIOS_CS: U3.156 (~BIOS_CS); also elsewhere on the board
~BLE: J14.18, U1.17 (~BLE), U3.76 (~BLE)
~CAS0: U3.106 (~CAS0); also elsewhere on the board
~CAS1: U3.107 (~CAS1); also elsewhere on the board
~CAS2: U3.108 (~CAS2); also elsewhere on the board
~CAS3: U3.109 (~CAS3); also elsewhere on the board
~CPU_BUSY: J15.10, U1.34 (~BUSY), U3.69 (~CPU_BUSY)
~DACK0: U3.29 (~DACK0); also elsewhere on the board
~DACK1: U3.27 (~DACK1); also elsewhere on the board
~DACK2: U3.24 (~DACK2); also elsewhere on the board
~DACK3: U3.22 (~DACK3); also elsewhere on the board
~DACK5: U3.20 (~DACK5); also elsewhere on the board
~DACK6: U3.18 (~DACK6); also elsewhere on the board
~DACK7: U3.16 (~DACK7); also elsewhere on the board
~FPU_BUSY: U2.36 (~BUSY), U3.38 (~FPU_BUSY)
~FPU_ERROR: U2.35 (~ERROR), U3.39 (~FPU_ERROR)
~IOCS16: U3.34 (~IOCS16); also elsewhere on the board
~IOR: U3.190 (~IOR); also elsewhere on the board
~IOW: U3.191 (~IOW); also elsewhere on the board
~IO_CH_CHK: U3.35 (~IO_CH_CHK); also elsewhere on the board
~KBC_CS: U3.152 (~KBC_CS); also elsewhere on the board
~KBC_GA20: J15.5, U1.31 (NC/~SMIADS/~A20M), U3.153 (~GATE_A20); also elsewhere on the board
~KBC_RC: U3.155 (~KBC_RC); also elsewhere on the board
~MEMCS16: U3.36 (~MEMCS16); also elsewhere on the board
~MEMR: U3.192 (~MEMR); also elsewhere on the board
~MEMW: U3.193 (~MEMW); also elsewhere on the board
~MWE: U3.110 (~MWE); also elsewhere on the board
~RAS01: U3.102 (~RAS01); also elsewhere on the board
~RAS23: U3.103 (~RAS23); also elsewhere on the board
~READY: J14.8, R23.2, U1.7 (~READY), U2.49 (~READY), U3.80 (~READY), U7.9
~REFRESH: U3.6 (~REFRESH); also elsewhere on the board
~RESET: U3.157 (~RESET), U7.5; also elsewhere on the board
~RTC_IRQ8: U3.159 (~RTC_IRQ8); also elsewhere on the board
~SBHE: U3.189 (~SBHE); also elsewhere on the board
~SMEMR: U3.194 (~SMEMR); also elsewhere on the board
~SMEMW: U3.195 (~SMEMW); also elsewhere on the board

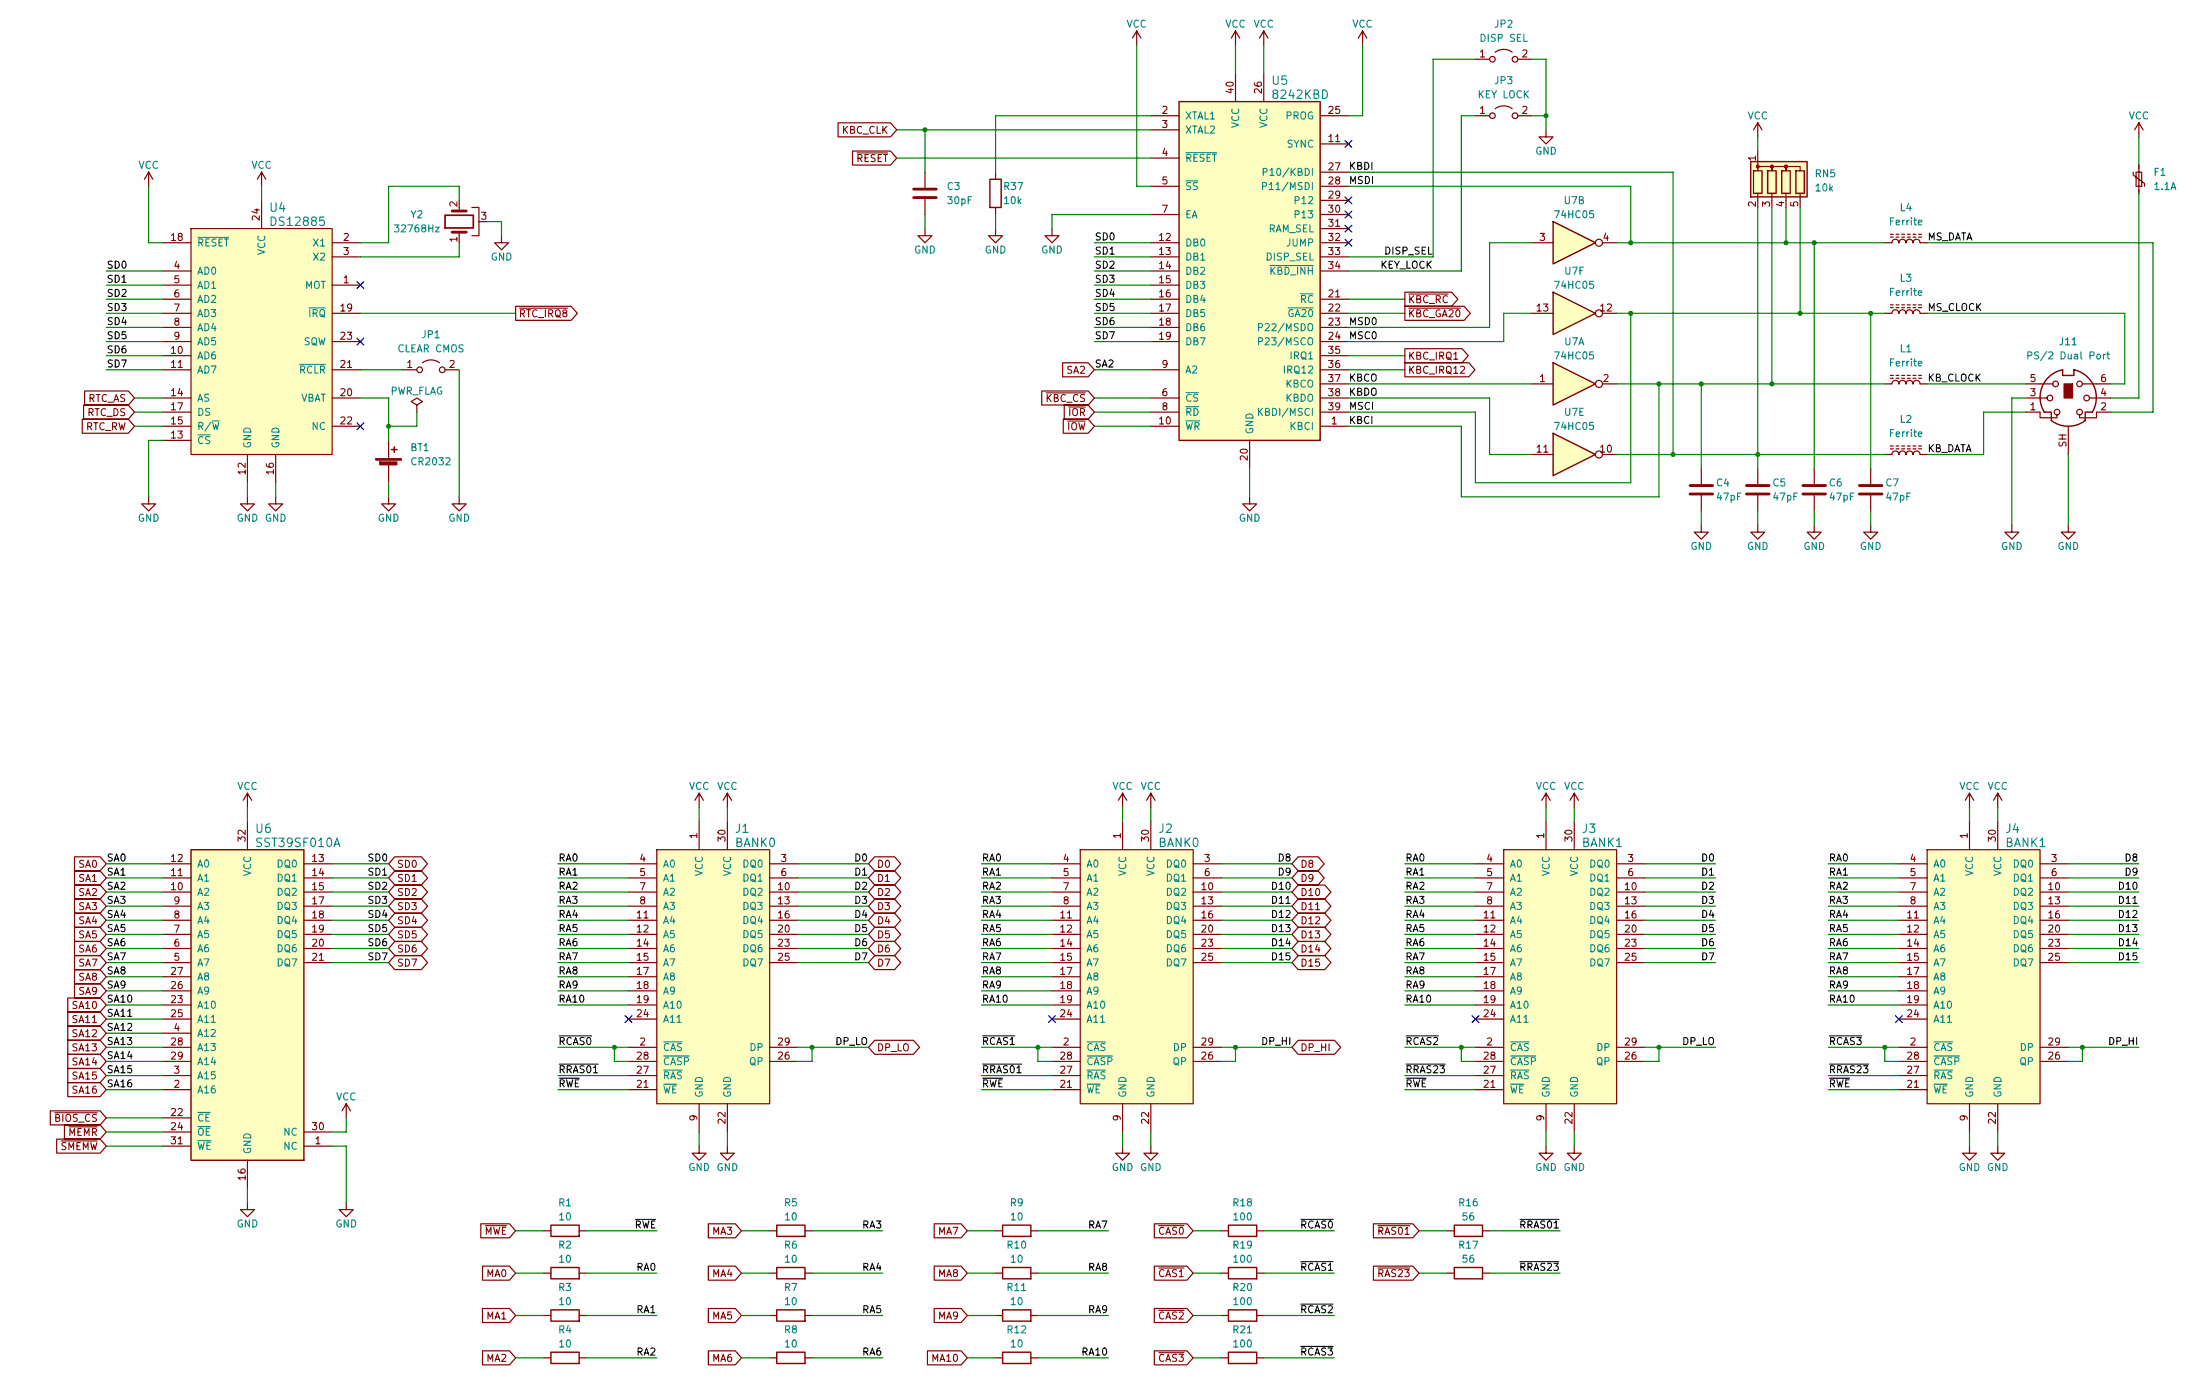
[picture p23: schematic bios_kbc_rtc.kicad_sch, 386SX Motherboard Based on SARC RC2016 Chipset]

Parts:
BT1: CR2032; Battery_Holder_CR2032_Universal
C3: 30pF; Cap_Cer_508
C4, C5, C6, C7: 47pF; Cap_Cer_508
F1: 1.1A; Cap_Cer_508
J1, J2: BANK0; Conn_SIMM30
J3, J4: BANK1; Conn_SIMM30
J11: PS/2 Dual Port; Conn_Mini_DIN_6pin
JP1: CLEAR CMOS; Conn_Pin_Header_2x1_2.54mm
JP2: DISP SEL; Conn_Pin_Header_2x1_2.54mm
JP3: KEY LOCK; Conn_Pin_Header_2x1_2.54mm
L1, L2, L3, L4: Ferrite; L_Ferrite_1016
R1, R2, R3, R4, R5, R6, R7, R8, R9, R10, R11, R12: 10; Res_762
R16, R17: 56; Res_762
R18, R19, R20, R21: 100; Res_762
R37: 10k; Res_762
RN5: 10k; Conn_SIL5
U4: DS12885; IC_DIP24_600
U5: 8242KBD; IC_DIP40_600
U6: SST39SF010A; IC_DIP32_600
U7: 74HC05; IC_DIP14_300
Y2: 32768Hz; Crystal_32K_Horiz

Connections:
/Memory, BIOS, Keyboard, RTC/DISP_SEL: JP2.1 (A), U5.33 (DISP_SEL)
/Memory, BIOS, Keyboard, RTC/KBCI: C4.1, L1.1, RN5.3 (R2), U5.1 (KBCI), U7.2
/Memory, BIOS, Keyboard, RTC/KBCO: U5.37 (KBCO), U7.1
/Memory, BIOS, Keyboard, RTC/KBDI: C5.1, L2.1, RN5.2 (R1), U5.27 (P10/KBDI), U7.10
/Memory, BIOS, Keyboard, RTC/KBDO: U5.38 (KBDO), U7.11
/Memory, BIOS, Keyboard, RTC/KB_CLOCK: J11.5, L1.2
/Memory, BIOS, Keyboard, RTC/KB_DATA: J11.1, L2.2
/Memory, BIOS, Keyboard, RTC/KEY_LOCK: JP3.1 (A), U5.34 (~KBD_INH)
/Memory, BIOS, Keyboard, RTC/MSC0: U5.24 (P23/MSCO), U7.13
/Memory, BIOS, Keyboard, RTC/MSCI: C7.1, L3.1, RN5.5 (R4), U5.39 (KBDI/MSCI), U7.12
/Memory, BIOS, Keyboard, RTC/MSD0: U5.23 (P22/MSDO), U7.3
/Memory, BIOS, Keyboard, RTC/MSDI: C6.1, L4.1, RN5.4 (R3), U5.28 (P11/MSDI), U7.4
/Memory, BIOS, Keyboard, RTC/MS_CLOCK: J11.6, L3.2
/Memory, BIOS, Keyboard, RTC/MS_DATA: J11.2, L4.2
/Memory, BIOS, Keyboard, RTC/RA0: J1.4 (A0), J2.4 (A0), J3.4 (A0), J4.4 (A0), R2.2
/Memory, BIOS, Keyboard, RTC/RA1: J1.5 (A1), J2.5 (A1), J3.5 (A1), J4.5 (A1), R3.2
/Memory, BIOS, Keyboard, RTC/RA2: J1.7 (A2), J2.7 (A2), J3.7 (A2), J4.7 (A2), R4.2
/Memory, BIOS, Keyboard, RTC/RA3: J1.8 (A3), J2.8 (A3), J3.8 (A3), J4.8 (A3), R5.2
/Memory, BIOS, Keyboard, RTC/RA4: J1.11 (A4), J2.11 (A4), J3.11 (A4), J4.11 (A4), R6.2
/Memory, BIOS, Keyboard, RTC/RA5: J1.12 (A5), J2.12 (A5), J3.12 (A5), J4.12 (A5), R7.2
/Memory, BIOS, Keyboard, RTC/RA6: J1.14 (A6), J2.14 (A6), J3.14 (A6), J4.14 (A6), R8.2
/Memory, BIOS, Keyboard, RTC/RA7: J1.15 (A7), J2.15 (A7), J3.15 (A7), J4.15 (A7), R9.2
/Memory, BIOS, Keyboard, RTC/RA8: J1.17 (A8), J2.17 (A8), J3.17 (A8), J4.17 (A8), R10.2
/Memory, BIOS, Keyboard, RTC/RA9: J1.18 (A9), J2.18 (A9), J3.18 (A9), J4.18 (A9), R11.2
/Memory, BIOS, Keyboard, RTC/RA10: J1.19 (A10), J2.19 (A10), J3.19 (A10), J4.19 (A10), R12.2
/Memory, BIOS, Keyboard, RTC/~RCAS0: J1.2 (~CAS), J1.28 (~CASP), R18.2
/Memory, BIOS, Keyboard, RTC/~RCAS1: J2.2 (~CAS), J2.28 (~CASP), R19.2
/Memory, BIOS, Keyboard, RTC/~RCAS2: J3.2 (~CAS), J3.28 (~CASP), R20.2
/Memory, BIOS, Keyboard, RTC/~RCAS3: J4.2 (~CAS), J4.28 (~CASP), R21.2
/Memory, BIOS, Keyboard, RTC/~RRAS01: J1.27 (~RAS), J2.27 (~RAS), R16.2
/Memory, BIOS, Keyboard, RTC/~RRAS23: J3.27 (~RAS), J4.27 (~RAS), R17.2
/Memory, BIOS, Keyboard, RTC/~RWE: J1.21 (~WE), J2.21 (~WE), J3.21 (~WE), J4.21 (~WE), R1.2
D0: J1.3 (DQ0), J3.3 (DQ0); also elsewhere on the board
D1: J1.6 (DQ1), J3.6 (DQ1); also elsewhere on the board
D2: J1.10 (DQ2), J3.10 (DQ2); also elsewhere on the board
D3: J1.13 (DQ3), J3.13 (DQ3); also elsewhere on the board
D4: J1.16 (DQ4), J3.16 (DQ4); also elsewhere on the board
D5: J1.20 (DQ5), J3.20 (DQ5); also elsewhere on the board
D6: J1.23 (DQ6), J3.23 (DQ6); also elsewhere on the board
D7: J1.25 (DQ7), J3.25 (DQ7); also elsewhere on the board
D8: J2.3 (DQ0), J4.3 (DQ0); also elsewhere on the board
D9: J2.6 (DQ1), J4.6 (DQ1); also elsewhere on the board
D10: J2.10 (DQ2), J4.10 (DQ2); also elsewhere on the board
D11: J2.13 (DQ3), J4.13 (DQ3); also elsewhere on the board
D12: J2.16 (DQ4), J4.16 (DQ4); also elsewhere on the board
D13: J2.20 (DQ5), J4.20 (DQ5); also elsewhere on the board
D14: J2.23 (DQ6), J4.23 (DQ6); also elsewhere on the board
D15: J2.25 (DQ7), J4.25 (DQ7); also elsewhere on the board
DP_HI: J2.26 (QP), J2.29 (DP), J4.26 (QP), J4.29 (DP); also elsewhere on the board
DP_LO: J1.26 (QP), J1.29 (DP), J3.26 (QP), J3.29 (DP); also elsewhere on the board
GND: BT1.2 (-), C3.2, C4.2, C5.2, C6.2, C7.2, J1.9 (GND), J1.22 (GND), J2.9 (GND), J2.22 (GND), J3.9 (GND), J3.22 (GND), J4.9 (GND), J4.22 (GND), J11.3, J11.SH, JP1.2 (B), JP2.2 (B), JP3.2 (B), R37.2, U4.12 (GND), U4.13 (~CS), U4.16 (GND), U5.7 (EA), U5.20 (GND), U6.1 (NC), U6.16 (GND), Y2.3; also elsewhere on the board
KBC_CLK: C3.1, U5.3 (XTAL2); also elsewhere on the board
KBC_IRQ1: U5.35 (IRQ1); also elsewhere on the board
KBC_IRQ12: U5.36 (IRQ12); also elsewhere on the board
MA0: R2.1; also elsewhere on the board
MA1: R3.1; also elsewhere on the board
MA2: R4.1; also elsewhere on the board
MA3: R5.1; also elsewhere on the board
MA4: R6.1; also elsewhere on the board
MA5: R7.1; also elsewhere on the board
MA6: R8.1; also elsewhere on the board
MA7: R9.1; also elsewhere on the board
MA8: R10.1; also elsewhere on the board
MA9: R11.1; also elsewhere on the board
MA10: R12.1; also elsewhere on the board
unnamed: BT1.1 (+), U4.20 (VBAT)
unnamed: F1.1, J11.4
unnamed: JP1.1 (A), U4.21 (~RCLR)
unnamed: R37.1, U5.2 (XTAL1)
unnamed: U4.2 (X1), Y2.2
unnamed: U4.3 (X2), Y2.1
RTC_AS: U4.14 (AS); also elsewhere on the board
RTC_DS: U4.17 (DS); also elsewhere on the board
RTC_RW: U4.15 (R/~W); also elsewhere on the board
SA0: U6.12 (A0); also elsewhere on the board
SA1: U6.11 (A1); also elsewhere on the board
SA2: U5.9 (A2), U6.10 (A2); also elsewhere on the board
SA3: U6.9 (A3); also elsewhere on the board
SA4: U6.8 (A4); also elsewhere on the board
SA5: U6.7 (A5); also elsewhere on the board
SA6: U6.6 (A6); also elsewhere on the board
SA7: U6.5 (A7); also elsewhere on the board
SA8: U6.27 (A8); also elsewhere on the board
SA9: U6.26 (A9); also elsewhere on the board
SA10: U6.23 (A10); also elsewhere on the board
SA11: U6.25 (A11); also elsewhere on the board
SA12: U6.4 (A12); also elsewhere on the board
SA13: U6.28 (A13); also elsewhere on the board
SA14: U6.29 (A14); also elsewhere on the board
SA15: U6.3 (A15); also elsewhere on the board
SA16: U6.2 (A16); also elsewhere on the board
SD0: U4.4 (AD0), U5.12 (DB0), U6.13 (DQ0); also elsewhere on the board
SD1: U4.5 (AD1), U5.13 (DB1), U6.14 (DQ1); also elsewhere on the board
SD2: U4.6 (AD2), U5.14 (DB2), U6.15 (DQ2); also elsewhere on the board
SD3: U4.7 (AD3), U5.15 (DB3), U6.17 (DQ3); also elsewhere on the board
SD4: U4.8 (AD4), U5.16 (DB4), U6.18 (DQ4); also elsewhere on the board
SD5: U4.9 (AD5), U5.17 (DB5), U6.19 (DQ5); also elsewhere on the board
SD6: U4.10 (AD6), U5.18 (DB6), U6.20 (DQ6); also elsewhere on the board
SD7: U4.11 (AD7), U5.19 (DB7), U6.21 (DQ7); also elsewhere on the board
VCC: F1.2, J1.1 (VCC), J1.30 (VCC), J2.1 (VCC), J2.30 (VCC), J3.1 (VCC), J3.30 (VCC), J4.1 (VCC), J4.30 (VCC), RN5.1 (common), U4.18 (~RESET), U4.24 (VCC), U5.5 (~SS), U5.25 (PROG), U5.26 (VCC), U5.40 (VCC), U6.30 (NC), U6.32 (VCC); also elsewhere on the board
~BIOS_CS: U6.22 (~CE); also elsewhere on the board
~CAS0: R18.1; also elsewhere on the board
~CAS1: R19.1; also elsewhere on the board
~CAS2: R20.1; also elsewhere on the board
~CAS3: R21.1; also elsewhere on the board
~IOR: U5.8 (~RD); also elsewhere on the board
~IOW: U5.10 (~WR); also elsewhere on the board
~KBC_CS: U5.6 (~CS); also elsewhere on the board
~KBC_GA20: U5.22 (~GA20); also elsewhere on the board
~KBC_RC: U5.21 (~RC); also elsewhere on the board
~MEMR: U6.24 (~OE); also elsewhere on the board
~MWE: R1.1; also elsewhere on the board
~RAS01: R16.1; also elsewhere on the board
~RAS23: R17.1; also elsewhere on the board
~RESET: U5.4 (~RESET); also elsewhere on the board
~RTC_IRQ8: U4.19 (~IRQ); also elsewhere on the board
~SMEMW: U6.31 (~WE); also elsewhere on the board

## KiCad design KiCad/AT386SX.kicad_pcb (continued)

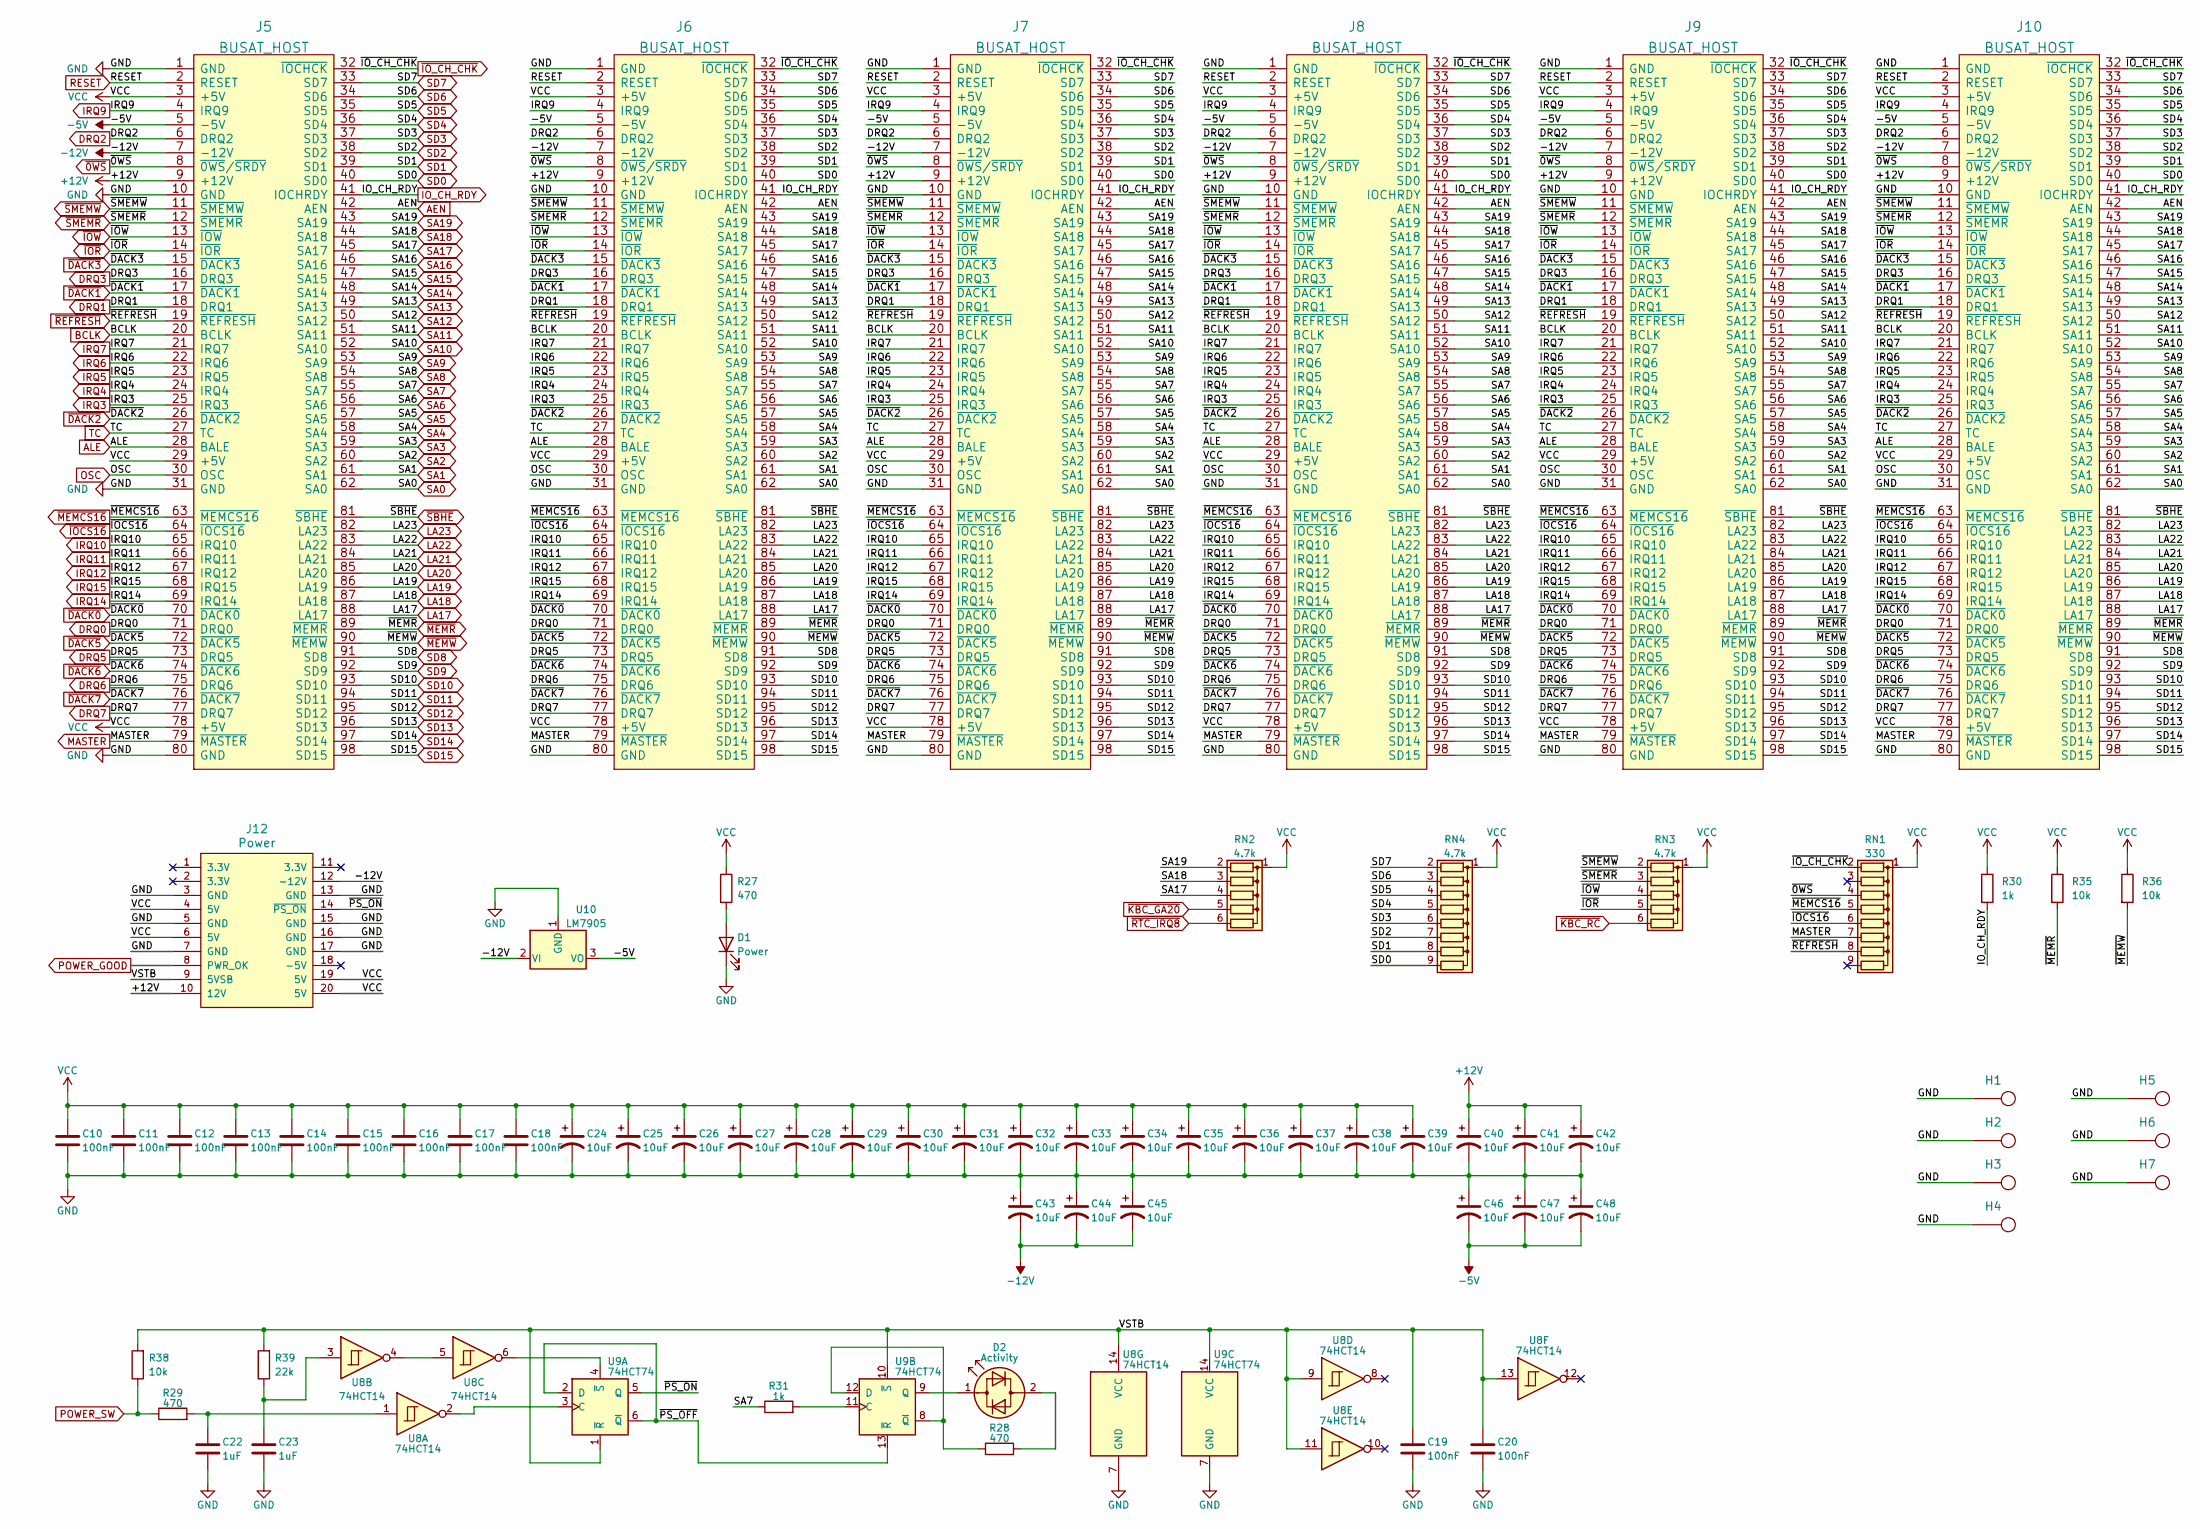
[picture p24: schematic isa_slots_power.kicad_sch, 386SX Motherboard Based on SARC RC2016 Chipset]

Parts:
C10, C11, C12, C13, C14, C15, C16, C17, C18, C19, C20: 100nF; Cap_Cer_508
C22, C23: 1uF; Cap_Cer_508
C24, C25, C26, C27, C28, C29, C30, C31, C32, C33, C34, C35, C36, C37, C38, C39, C40, C41, C42, C43, C44, C45, C46, C47, C48: 10uF; Cap_Elec_Radial_5mm_2.5mm
D1: Power; LED_3mm
D2: Activity; LED_3mm
H1, H2, H3, H4, H5, H6, H7: HOLE; MountingHole_4mm_Pad_Via
J5, J6, J7, J8, J9, J10: BUSAT_HOST; Conn_Edge_ISA16
J12: Power; Conn_Power_ATX_20pin
R27, R28, R29: 470; Res_762
R30, R31: 1k; Res_762
R35, R36, R38: 10k; Res_762
R39: 22k; Res_762
RN1: 330; Conn_SIL9
RN2, RN3: 4.7k; Conn_SIL6
RN4: 4.7k; Conn_SIL9
U8: 74HCT14; IC_DIP14_300
U9: 74HCT74; IC_DIP14_300
U10: LM7905; IC_TO220-3_Vert

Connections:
+12V: C40.1, C41.1, C42.1, J5.9 (+12V), J6.9 (+12V), J7.9 (+12V), J8.9 (+12V), J9.9 (+12V), J10.9 (+12V), J12.10 (12V)
-5V: C46.2, C47.2, C48.2, J5.5 (-5V), J6.5 (-5V), J7.5 (-5V), J8.5 (-5V), J9.5 (-5V), J10.5 (-5V), U10.3 (VO)
-12V: C43.2, C44.2, C45.2, J5.7 (-12V), J6.7 (-12V), J7.7 (-12V), J8.7 (-12V), J9.7 (-12V), J10.7 (-12V), J12.12 (-12V), U10.2 (VI)
/ISA Slots and Power/VSTB: C19.1, C20.1, J12.9 (5VSB), R38.2, R39.2, U8.9, U8.11, U8.13, U8.14 (VCC), U9.1 (~R), U9.10 (~S), U9.14 (VCC)
/ISA Slots and Power/~PS_OFF: U9.2 (D), U9.6 (~Q), U9.13 (~R)
/ISA Slots and Power/~PS_ON: J12.14 (~PS_ON), U9.5 (Q)
AEN: J5.42 (AEN), J6.42 (AEN), J7.42 (AEN), J8.42 (AEN), J9.42 (AEN), J10.42 (AEN); also elsewhere on the board
ALE: J5.28 (BALE), J6.28 (BALE), J7.28 (BALE), J8.28 (BALE), J9.28 (BALE), J10.28 (BALE); also elsewhere on the board
BCLK: J5.20 (BCLK), J6.20 (BCLK), J7.20 (BCLK), J8.20 (BCLK), J9.20 (BCLK), J10.20 (BCLK); also elsewhere on the board
DRQ0: J5.71 (DRQ0), J6.71 (DRQ0), J7.71 (DRQ0), J8.71 (DRQ0), J9.71 (DRQ0), J10.71 (DRQ0); also elsewhere on the board
DRQ1: J5.18 (DRQ1), J6.18 (DRQ1), J7.18 (DRQ1), J8.18 (DRQ1), J9.18 (DRQ1), J10.18 (DRQ1); also elsewhere on the board
DRQ2: J5.6 (DRQ2), J6.6 (DRQ2), J7.6 (DRQ2), J8.6 (DRQ2), J9.6 (DRQ2), J10.6 (DRQ2); also elsewhere on the board
DRQ3: J5.16 (DRQ3), J6.16 (DRQ3), J7.16 (DRQ3), J8.16 (DRQ3), J9.16 (DRQ3), J10.16 (DRQ3); also elsewhere on the board
DRQ5: J5.73 (DRQ5), J6.73 (DRQ5), J7.73 (DRQ5), J8.73 (DRQ5), J9.73 (DRQ5), J10.73 (DRQ5); also elsewhere on the board
DRQ6: J5.75 (DRQ6), J6.75 (DRQ6), J7.75 (DRQ6), J8.75 (DRQ6), J9.75 (DRQ6), J10.75 (DRQ6); also elsewhere on the board
DRQ7: J5.77 (DRQ7), J6.77 (DRQ7), J7.77 (DRQ7), J8.77 (DRQ7), J9.77 (DRQ7), J10.77 (DRQ7); also elsewhere on the board
GND: C10.2, C11.2, C12.2, C13.2, C14.2, C15.2, C16.2, C17.2, C18.2, C19.2, C20.2, C22.2, C23.2, C24.2, C25.2, C26.2, C27.2, C28.2, C29.2, C30.2, C31.2, C32.2, C33.2, C34.2, C35.2, C36.2, C37.2, C38.2, C39.2, C40.2, C41.2, C42.2, C43.1, C44.1, C45.1, C46.1, C47.1, C48.1, D1.1 (K), H1.1, H2.1, H3.1, H4.1, H5.1, H6.1, H7.1, J5.1 (GND), J5.10 (GND), J5.31 (GND), J5.80 (GND), J6.1 (GND), J6.10 (GND), J6.31 (GND), J6.80 (GND), J7.1 (GND), J7.10 (GND), J7.31 (GND), J7.80 (GND), J8.1 (GND), J8.10 (GND), J8.31 (GND), J8.80 (GND), J9.1 (GND), J9.10 (GND), J9.31 (GND), J9.80 (GND), J10.1 (GND), J10.10 (GND), J10.31 (GND), J10.80 (GND), J12.3 (GND), J12.5 (GND), J12.7 (GND), J12.13 (GND), J12.15 (GND), J12.16 (GND), J12.17 (GND), U8.7 (GND), U9.7 (GND), U10.1 (GND); also elsewhere on the board
IO_CH_RDY: J5.41 (IOCHRDY), J6.41 (IOCHRDY), J7.41 (IOCHRDY), J8.41 (IOCHRDY), J9.41 (IOCHRDY), J10.41 (IOCHRDY), R30.2; also elsewhere on the board
IRQ3: J5.25 (IRQ3), J6.25 (IRQ3), J7.25 (IRQ3), J8.25 (IRQ3), J9.25 (IRQ3), J10.25 (IRQ3); also elsewhere on the board
IRQ4: J5.24 (IRQ4), J6.24 (IRQ4), J7.24 (IRQ4), J8.24 (IRQ4), J9.24 (IRQ4), J10.24 (IRQ4); also elsewhere on the board
IRQ5: J5.23 (IRQ5), J6.23 (IRQ5), J7.23 (IRQ5), J8.23 (IRQ5), J9.23 (IRQ5), J10.23 (IRQ5); also elsewhere on the board
IRQ6: J5.22 (IRQ6), J6.22 (IRQ6), J7.22 (IRQ6), J8.22 (IRQ6), J9.22 (IRQ6), J10.22 (IRQ6); also elsewhere on the board
IRQ7: J5.21 (IRQ7), J6.21 (IRQ7), J7.21 (IRQ7), J8.21 (IRQ7), J9.21 (IRQ7), J10.21 (IRQ7); also elsewhere on the board
IRQ9: J5.4 (IRQ9), J6.4 (IRQ9), J7.4 (IRQ9), J8.4 (IRQ9), J9.4 (IRQ9), J10.4 (IRQ9); also elsewhere on the board
IRQ10: J5.65 (IRQ10), J6.65 (IRQ10), J7.65 (IRQ10), J8.65 (IRQ10), J9.65 (IRQ10), J10.65 (IRQ10); also elsewhere on the board
IRQ11: J5.66 (IRQ11), J6.66 (IRQ11), J7.66 (IRQ11), J8.66 (IRQ11), J9.66 (IRQ11), J10.66 (IRQ11); also elsewhere on the board
IRQ12: J5.67 (IRQ12), J6.67 (IRQ12), J7.67 (IRQ12), J8.67 (IRQ12), J9.67 (IRQ12), J10.67 (IRQ12); also elsewhere on the board
IRQ14: J5.69 (IRQ14), J6.69 (IRQ14), J7.69 (IRQ14), J8.69 (IRQ14), J9.69 (IRQ14), J10.69 (IRQ14); also elsewhere on the board
IRQ15: J5.68 (IRQ15), J6.68 (IRQ15), J7.68 (IRQ15), J8.68 (IRQ15), J9.68 (IRQ15), J10.68 (IRQ15); also elsewhere on the board
LA17: J5.88 (LA17), J6.88 (LA17), J7.88 (LA17), J8.88 (LA17), J9.88 (LA17), J10.88 (LA17); also elsewhere on the board
LA18: J5.87 (LA18), J6.87 (LA18), J7.87 (LA18), J8.87 (LA18), J9.87 (LA18), J10.87 (LA18); also elsewhere on the board
LA19: J5.86 (LA19), J6.86 (LA19), J7.86 (LA19), J8.86 (LA19), J9.86 (LA19), J10.86 (LA19); also elsewhere on the board
LA20: J5.85 (LA20), J6.85 (LA20), J7.85 (LA20), J8.85 (LA20), J9.85 (LA20), J10.85 (LA20); also elsewhere on the board
LA21: J5.84 (LA21), J6.84 (LA21), J7.84 (LA21), J8.84 (LA21), J9.84 (LA21), J10.84 (LA21); also elsewhere on the board
LA22: J5.83 (LA22), J6.83 (LA22), J7.83 (LA22), J8.83 (LA22), J9.83 (LA22), J10.83 (LA22); also elsewhere on the board
LA23: J5.82 (LA23), J6.82 (LA23), J7.82 (LA23), J8.82 (LA23), J9.82 (LA23), J10.82 (LA23); also elsewhere on the board
MASTER: J5.79 (~MASTER), J6.79 (~MASTER), J7.79 (~MASTER), J8.79 (~MASTER), J9.79 (~MASTER), J10.79 (~MASTER), RN1.7 (R6); also elsewhere on the board
unnamed: C22.1, R29.2, U8.1
unnamed: C23.1, R39.1, U8.3
unnamed: D1.2 (A), R27.2
unnamed: D2.1 (KA), U9.9 (Q)
unnamed: D2.2 (AK), R28.2
unnamed: R28.1, U9.8 (~Q), U9.12 (D)
unnamed: R31.2, U9.11 (C)
unnamed: U8.2, U9.3 (C)
unnamed: U8.4, U8.5
unnamed: U8.6, U9.4 (~S)
OSC: J5.30 (OSC), J6.30 (OSC), J7.30 (OSC), J8.30 (OSC), J9.30 (OSC), J10.30 (OSC); also elsewhere on the board
POWER_GOOD: J12.8 (PWR_OK); also elsewhere on the board
POWER_SW: R29.1, R38.1; also elsewhere on the board
RESET: J5.2 (RESET), J6.2 (RESET), J7.2 (RESET), J8.2 (RESET), J9.2 (RESET), J10.2 (RESET); also elsewhere on the board
SA0: J5.62 (SA0), J6.62 (SA0), J7.62 (SA0), J8.62 (SA0), J9.62 (SA0), J10.62 (SA0); also elsewhere on the board
SA1: J5.61 (SA1), J6.61 (SA1), J7.61 (SA1), J8.61 (SA1), J9.61 (SA1), J10.61 (SA1); also elsewhere on the board
SA2: J5.60 (SA2), J6.60 (SA2), J7.60 (SA2), J8.60 (SA2), J9.60 (SA2), J10.60 (SA2); also elsewhere on the board
SA3: J5.59 (SA3), J6.59 (SA3), J7.59 (SA3), J8.59 (SA3), J9.59 (SA3), J10.59 (SA3); also elsewhere on the board
SA4: J5.58 (SA4), J6.58 (SA4), J7.58 (SA4), J8.58 (SA4), J9.58 (SA4), J10.58 (SA4); also elsewhere on the board
SA5: J5.57 (SA5), J6.57 (SA5), J7.57 (SA5), J8.57 (SA5), J9.57 (SA5), J10.57 (SA5); also elsewhere on the board
SA6: J5.56 (SA6), J6.56 (SA6), J7.56 (SA6), J8.56 (SA6), J9.56 (SA6), J10.56 (SA6); also elsewhere on the board
SA7: J5.55 (SA7), J6.55 (SA7), J7.55 (SA7), J8.55 (SA7), J9.55 (SA7), J10.55 (SA7), R31.1; also elsewhere on the board
SA8: J5.54 (SA8), J6.54 (SA8), J7.54 (SA8), J8.54 (SA8), J9.54 (SA8), J10.54 (SA8); also elsewhere on the board
SA9: J5.53 (SA9), J6.53 (SA9), J7.53 (SA9), J8.53 (SA9), J9.53 (SA9), J10.53 (SA9); also elsewhere on the board
SA10: J5.52 (SA10), J6.52 (SA10), J7.52 (SA10), J8.52 (SA10), J9.52 (SA10), J10.52 (SA10); also elsewhere on the board
SA11: J5.51 (SA11), J6.51 (SA11), J7.51 (SA11), J8.51 (SA11), J9.51 (SA11), J10.51 (SA11); also elsewhere on the board
SA12: J5.50 (SA12), J6.50 (SA12), J7.50 (SA12), J8.50 (SA12), J9.50 (SA12), J10.50 (SA12); also elsewhere on the board
SA13: J5.49 (SA13), J6.49 (SA13), J7.49 (SA13), J8.49 (SA13), J9.49 (SA13), J10.49 (SA13); also elsewhere on the board
SA14: J5.48 (SA14), J6.48 (SA14), J7.48 (SA14), J8.48 (SA14), J9.48 (SA14), J10.48 (SA14); also elsewhere on the board
SA15: J5.47 (SA15), J6.47 (SA15), J7.47 (SA15), J8.47 (SA15), J9.47 (SA15), J10.47 (SA15); also elsewhere on the board
SA16: J5.46 (SA16), J6.46 (SA16), J7.46 (SA16), J8.46 (SA16), J9.46 (SA16), J10.46 (SA16); also elsewhere on the board
SA17: J5.45 (SA17), J6.45 (SA17), J7.45 (SA17), J8.45 (SA17), J9.45 (SA17), J10.45 (SA17), RN2.4 (R3); also elsewhere on the board
SA18: J5.44 (SA18), J6.44 (SA18), J7.44 (SA18), J8.44 (SA18), J9.44 (SA18), J10.44 (SA18), RN2.3 (R2); also elsewhere on the board
SA19: J5.43 (SA19), J6.43 (SA19), J7.43 (SA19), J8.43 (SA19), J9.43 (SA19), J10.43 (SA19), RN2.2 (R1); also elsewhere on the board
SD0: J5.40 (SD0), J6.40 (SD0), J7.40 (SD0), J8.40 (SD0), J9.40 (SD0), J10.40 (SD0), RN4.9 (R8); also elsewhere on the board
SD1: J5.39 (SD1), J6.39 (SD1), J7.39 (SD1), J8.39 (SD1), J9.39 (SD1), J10.39 (SD1), RN4.8 (R7); also elsewhere on the board
SD2: J5.38 (SD2), J6.38 (SD2), J7.38 (SD2), J8.38 (SD2), J9.38 (SD2), J10.38 (SD2), RN4.7 (R6); also elsewhere on the board
SD3: J5.37 (SD3), J6.37 (SD3), J7.37 (SD3), J8.37 (SD3), J9.37 (SD3), J10.37 (SD3), RN4.6 (R5); also elsewhere on the board
SD4: J5.36 (SD4), J6.36 (SD4), J7.36 (SD4), J8.36 (SD4), J9.36 (SD4), J10.36 (SD4), RN4.5 (R4); also elsewhere on the board
SD5: J5.35 (SD5), J6.35 (SD5), J7.35 (SD5), J8.35 (SD5), J9.35 (SD5), J10.35 (SD5), RN4.4 (R3); also elsewhere on the board
SD6: J5.34 (SD6), J6.34 (SD6), J7.34 (SD6), J8.34 (SD6), J9.34 (SD6), J10.34 (SD6), RN4.3 (R2); also elsewhere on the board
SD7: J5.33 (SD7), J6.33 (SD7), J7.33 (SD7), J8.33 (SD7), J9.33 (SD7), J10.33 (SD7), RN4.2 (R1); also elsewhere on the board
SD8: J5.91 (SD8), J6.91 (SD8), J7.91 (SD8), J8.91 (SD8), J9.91 (SD8), J10.91 (SD8); also elsewhere on the board
SD9: J5.92 (SD9), J6.92 (SD9), J7.92 (SD9), J8.92 (SD9), J9.92 (SD9), J10.92 (SD9); also elsewhere on the board
SD10: J5.93 (SD10), J6.93 (SD10), J7.93 (SD10), J8.93 (SD10), J9.93 (SD10), J10.93 (SD10); also elsewhere on the board
SD11: J5.94 (SD11), J6.94 (SD11), J7.94 (SD11), J8.94 (SD11), J9.94 (SD11), J10.94 (SD11); also elsewhere on the board
SD12: J5.95 (SD12), J6.95 (SD12), J7.95 (SD12), J8.95 (SD12), J9.95 (SD12), J10.95 (SD12); also elsewhere on the board
SD13: J5.96 (SD13), J6.96 (SD13), J7.96 (SD13), J8.96 (SD13), J9.96 (SD13), J10.96 (SD13); also elsewhere on the board
SD14: J5.97 (SD14), J6.97 (SD14), J7.97 (SD14), J8.97 (SD14), J9.97 (SD14), J10.97 (SD14); also elsewhere on the board
SD15: J5.98 (SD15), J6.98 (SD15), J7.98 (SD15), J8.98 (SD15), J9.98 (SD15), J10.98 (SD15); also elsewhere on the board
TC: J5.27 (TC), J6.27 (TC), J7.27 (TC), J8.27 (TC), J9.27 (TC), J10.27 (TC); also elsewhere on the board
VCC: C10.1, C11.1, C12.1, C13.1, C14.1, C15.1, C16.1, C17.1, C18.1, C24.1, C25.1, C26.1, C27.1, C28.1, C29.1, C30.1, C31.1, C32.1, C33.1, C34.1, C35.1, C36.1, C37.1, C38.1, C39.1, J5.3 (+5V), J5.29 (+5V), J5.78 (+5V), J6.3 (+5V), J6.29 (+5V), J6.78 (+5V), J7.3 (+5V), J7.29 (+5V), J7.78 (+5V), J8.3 (+5V), J8.29 (+5V), J8.78 (+5V), J9.3 (+5V), J9.29 (+5V), J9.78 (+5V), J10.3 (+5V), J10.29 (+5V), J10.78 (+5V), J12.4 (5V), J12.6 (5V), J12.19 (5V), J12.20 (5V), R27.1, R30.1, R35.1, R36.1, RN1.1 (common), RN2.1 (common), RN3.1 (common), RN4.1 (common); also elsewhere on the board
~0WS: J5.8 (~0WS/~SRDY), J6.8 (~0WS/~SRDY), J7.8 (~0WS/~SRDY), J8.8 (~0WS/~SRDY), J9.8 (~0WS/~SRDY), J10.8 (~0WS/~SRDY), RN1.4 (R3); also elsewhere on the board
~DACK0: J5.70 (~DACK0), J6.70 (~DACK0), J7.70 (~DACK0), J8.70 (~DACK0), J9.70 (~DACK0), J10.70 (~DACK0); also elsewhere on the board
~DACK1: J5.17 (~DACK1), J6.17 (~DACK1), J7.17 (~DACK1), J8.17 (~DACK1), J9.17 (~DACK1), J10.17 (~DACK1); also elsewhere on the board
~DACK2: J5.26 (~DACK2), J6.26 (~DACK2), J7.26 (~DACK2), J8.26 (~DACK2), J9.26 (~DACK2), J10.26 (~DACK2); also elsewhere on the board
~DACK3: J5.15 (~DACK3), J6.15 (~DACK3), J7.15 (~DACK3), J8.15 (~DACK3), J9.15 (~DACK3), J10.15 (~DACK3); also elsewhere on the board
~DACK5: J5.72 (~DACK5), J6.72 (~DACK5), J7.72 (~DACK5), J8.72 (~DACK5), J9.72 (~DACK5), J10.72 (~DACK5); also elsewhere on the board
~DACK6: J5.74 (~DACK6), J6.74 (~DACK6), J7.74 (~DACK6), J8.74 (~DACK6), J9.74 (~DACK6), J10.74 (~DACK6); also elsewhere on the board
~DACK7: J5.76 (~DACK7), J6.76 (~DACK7), J7.76 (~DACK7), J8.76 (~DACK7), J9.76 (~DACK7), J10.76 (~DACK7); also elsewhere on the board
~IOCS16: J5.64 (~IOCS16), J6.64 (~IOCS16), J7.64 (~IOCS16), J8.64 (~IOCS16), J9.64 (~IOCS16), J10.64 (~IOCS16), RN1.6 (R5); also elsewhere on the board
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

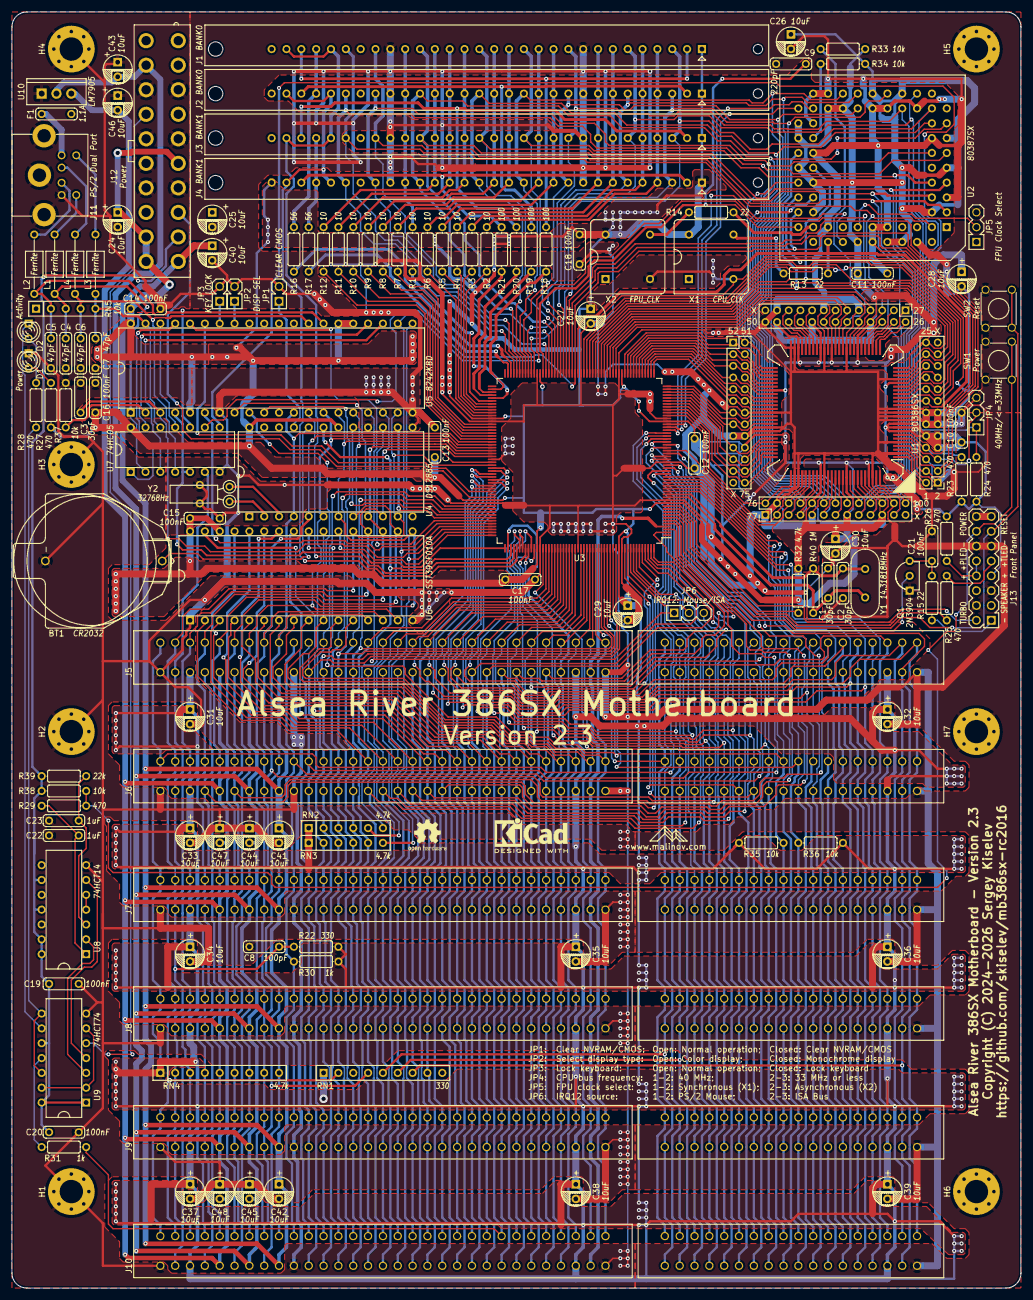
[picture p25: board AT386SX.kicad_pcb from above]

Board: 2 copper layers, 172.7 x 218.4 mm, 150 parts (0 on the bottom side), 267 nets.

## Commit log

2024-03-01 Add KiCad files for version 1.0
    [AT386SX.kicad_pcb, AT386SX.kicad_sch, bios_kbc_rtc.kicad_sch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]
2024-03-01 Add R32, update footprints
    [AT386SX.kicad_pcb, AT386SX.kicad_sch, bios_kbc_rtc.kicad_sch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]
2024-03-02 Use DS12885 RTC
    [AT386SX.kicad_pcb, AT386SX.kicad_sch, bios_kbc_rtc.kicad_sch]
2024-03-03 Add support for 128 KiB Flash ROM ICs
    [AT386SX.kicad_pcb, AT386SX.kicad_sch, bios_kbc_rtc.kicad_sch]
2024-03-05 Version 1.3: Implement PS/2 mouse. Use PS/2 dualport pinout for the keyboard/mouse connector
    [AT386SX.kicad_pcb, AT386SX.kicad_sch, bios_kbc_rtc.kicad_sch]
2024-03-05 Version 1.4: Move mounting holes to ATX compatible locations
    [AT386SX.kicad_sch, bios_kbc_rtc.kicad_sch, isa_slots_power.kicad_sch]
2024-03-06 Version 1.5: Add filtering capacitors
    [AT386SX.kicad_sch, isa_slots_power.kicad_sch]
2024-03-08 Version 1.6: Use half-can oscillators and low-profile crystal
    [AT386SX.kicad_sch, bios_kbc_rtc.kicad_sch, isa_slots_power.kicad_sch]
2024-03-21 Version 1.7: Use single front panel connector
    [AT386SX.kicad_sch, bios_kbc_rtc.kicad_sch, isa_slots_power.kicad_sch]
2024-04-23 Connect /OE and /WE of the BIOS ROM to allow Flash ROM in-system programming; Rotate the PCB into portrait orientation
    [AT386SX.kicad_sch, bios_kbc_rtc.kicad_sch]
2026-01-10 Version 1.9: Add pin headers for the CPU
    [AT386SX.kicad_sch, bios_kbc_rtc.kicad_sch, isa_slots_power.kicad_sch]
2026-01-14 Update zones and tracks, relocate components near the front panel header
    [AT386SX.kicad_sch]
2026-01-28 Use ATX power supply, add ATX power-on circuit
    [AT386SX.kicad_sch, isa_slots_power.kicad_sch]
2026-01-28 Version 2.1: Reorder component references; Update silkscreen; Add signal names on the back silkscreen
    [AT386SX.kicad_sch, bios_kbc_rtc.kicad_sch, isa_slots_power.kicad_sch]
2026-01-28 Version 2.1: Add Gerber files
    [AT386SX-B_Cu.gbr, AT386SX-B_Mask.gbr, AT386SX-B_Paste.gbr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]
2026-01-29 README: Add the BoM, except for the capacitors, resistors, and ferrite chokes.
2026-01-29 README: Complete the BoM
2026-02-04 README: Fix 2 pin header part number
2026-02-13 README: Update 10 uF capacitor part number. Add Status.
2026-02-18 Add a polyfuse for the PS/2 port
    [AT386SX.kicad_pcb, AT386SX.kicad_sch, bios_kbc_rtc.kicad_sch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]
2026-02-24 Update BIOS for Alsea River Motherboard
    * Enable PS/2 mouse
    * Disable Power Management menu
    * Disable External Cache menu option
    * Enable Parity Check menu option
    * Update Setup Defaults:
    * CPU cache: Enabled
    * Quick Power On Self Test: Enabled
    * Boot Up Floppy Seek: Disabled
    * System BIOS Shadow: Enabled
    * Video BIOS Shadow: Enabled
    * Change BIOS sign-in message to "Alsea River 386SX Motherboard"
    * Fix a typo in the word "abandon"
2026-02-26 Add version 2.3 files
    [AT386SX.kicad_pcb, AT386SX.kicad_sch, bios_kbc_rtc.kicad_sch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]
2026-03-14 User_Guide: Add LEDs and switches section, add a note about JP6 jumper for PS/2 mouse.
2026-03-14 User_Guide: Activity LED color clarification.
2026-05-13 Add 3D printed test bench case
    [Alsea_River_Test_Bench_Case.scad, ISA_Brackets.scad]
2026-05-13 Update 3D printed case
    [Alsea_River_Test_Bench_Case.scad]
2026-05-13 Add STL files
    [Back.stl, Bottom.stl, Left.stl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]

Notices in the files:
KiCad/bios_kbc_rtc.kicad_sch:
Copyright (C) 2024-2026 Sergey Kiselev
